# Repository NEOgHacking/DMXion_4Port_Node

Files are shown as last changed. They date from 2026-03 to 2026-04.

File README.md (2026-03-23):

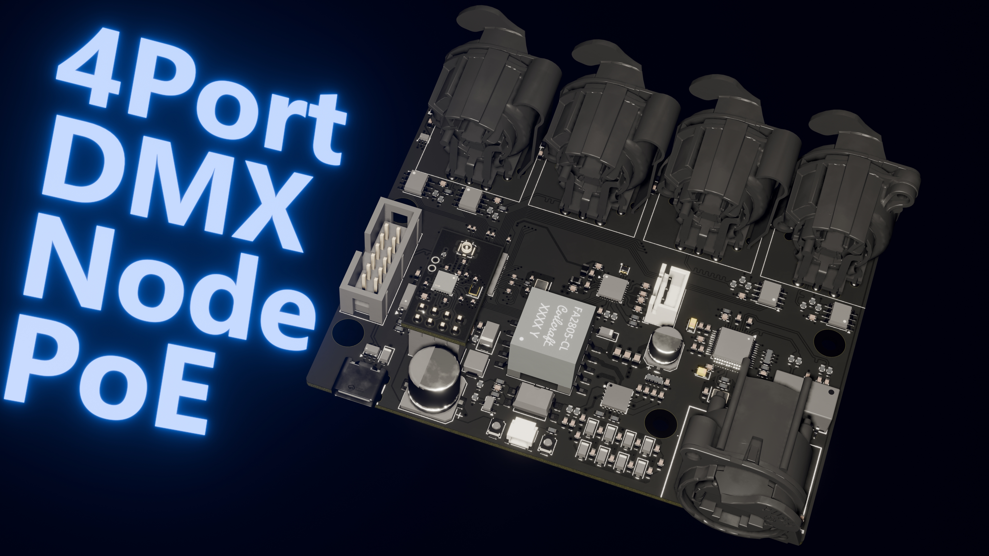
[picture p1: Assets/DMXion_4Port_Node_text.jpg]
Render

# DMXion_4Port_Node
DMXion_4Port_Node is a DMX network node based on the official grandMA3 onPC 4Port Node 4k. My version also has 4DMX outputs with RDM support, a EtherCON connector for sturdy Ethernet connections and a display with a rotating knob for configuration. It also uses the Neutrik halo connectors with adressable rgb leds to show the status of the connection. But it also has some differences. First it unfortunately doesn't unlock any parameters in the GrandMA onPC software, but its 20x cheaper. About $100 instead of $2000.

# Features
This specific DMX node has some really usefull features.
1. 4DMX outputs with RDM support.
2. Neutrik EtherCON connector for a sturdy and lasting connection. Also support for ARTNET and sACN
3. Color display with a rotary encoder for configuration straigt from the unit itself.
4. UPS (uniteruptable power supply) For when the power cuts out but you still need it or just for battery operation.
5. Wifi card slot for wireless operation with the battery.
6. Powered by a rp2350 for its PIO modules so DMX is correctly implemented and not via a hacked uart or bitbanging a pin.
7. PoE (Power over Ethernet) For easy setup and as little wires as possible.
8. USB-C port for power and data to program the rp2350 or configure it.
9. Cheap PCB. The PCB is 100x72mm 4 layer so its cost is low only $7.

# Motivation
I started on making this DMX network node for a few reasons. First i was using a raspberry pi with a usb DMX dongle, this worked but was hard to set up and only got me 1 DMX universe without RDM. It also wasn't the cheapest setup. I wanted it to be cheaper and have more functionallity. Second I once had the opurtunity to use a grandMA3 onPC 4Port Node 4k at school once and realized how usefull it would be. Then my dumb brain said the same sentence it always says: "I can build that myself for cheaper right?" Next thing you know you are 100 hours deep into the project.

# Design
The design process was a heck of a ride, at first i started with the simple DMX part but then got to the ethernet. I really wanted PoE so started with the ride. It was a heck of a long ride, i think it took up 1/3 of the projects time its really complex. Also the most complex schematic from the whole project. The rest went pretty smooth. I had recently done another big project my 3D Printer mainboard and learned allot from that! So the rest was pretty straight forward, always some small chip changes here and there but apart from that it went well. The case design also went quick didn't have to high of standards for that but still wanted it to look good. After a whole day that was done. 
I used KiCad for PCB design, Onshape for 3D design and VScode for Firmware.

# Use
To use this product first get the firmware uploaded via the arduino IDE or PlatformIO Then just plug it into a ethernet setup and plug in your DMX devices. Thats it! Its that simple! For config use the display with the rotating knob to select universes, ethernet settings, ext.

# Schematic
This is a very long schematic. You can find the whole schematics in .PDF format in the individual PCB design folders. But here are some important ones.
First the main schematic of the main PCB.
Main schematic
Then the schematic of the display module.
Display module schematic
And finally the esp wifi module.
WIFI module schematic

# PCB's
So this project has 3 PCB's, first the main PCB that does all the hard work, then a display PCB with a rotary encoder and support components for a bare LCD and finally a custom made WIFI module PCB based on the esp.
Main PCB
Display_module PCB
WIFI_module PCB
(there is a glitch in this game, every project i do i get exactly 3 PCB's)

# Case
For this project there needed to be a case to protect the PCB from the outside world. I did this in onshape and am happy with the end result.
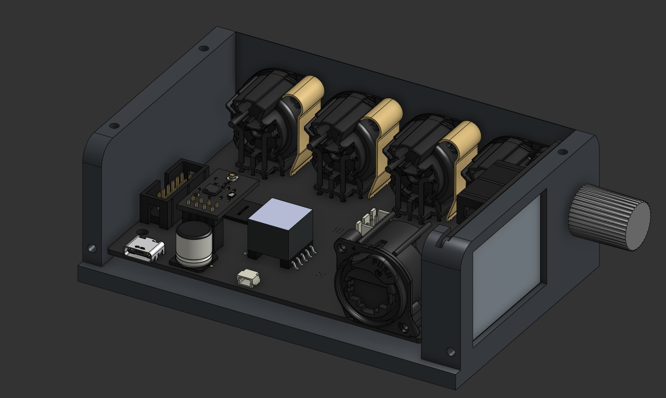
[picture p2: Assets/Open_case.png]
Open_case

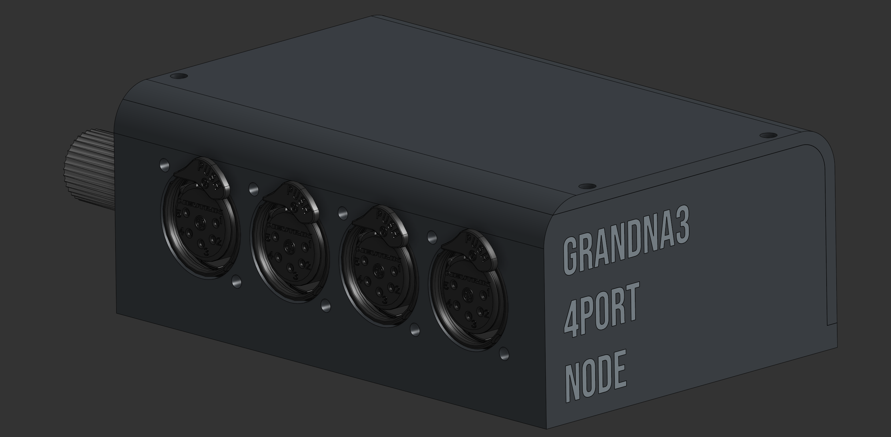
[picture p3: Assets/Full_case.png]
Full_case

Here is the Onshape link:
https://cad.onshape.com/documents/7a1aa90c6a7c74ef8699231e/w/3ea57ea1703701009a206be9/e/21fe65d6bda3912845cd8de3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
<details>
  <summary>BOM</summary>
  
# BOM
| Id | Designator | Footprint | Quantity | Designation | Supplier and ref | Column1 | Needed quantity | - | LCSC | MOUSER | Already in another pcb | Enough? | Mrf# | Mfr. | Order Qty. | Unit Price(USD) | Ext.Price(USD) | LCSC#/MOUSER | Package | Min | Mult | SPQ | Availability | Stock Status | Customer Notes | Description | Matched status | Product Link |  |  |  |  |  |  |  |  |  |  |  |  |  |  |  |  |  |  |  |
| --- | --- | --- | --- | --- | --- | --- | --- | --- | --- | --- | --- | --- | --- | --- | --- | --- | --- | --- | --- | --- | --- | --- | --- | --- | --- | --- | --- | --- | --- | --- | --- | --- | --- | --- | --- | --- | --- | --- | --- | --- | --- | --- | --- | --- | --- | --- | --- |
| 17 | BT1 | JST_XH_B3B-XH-A_1x03_P2.50mm_Vertical | 1 | Battery_Cell |  |  | 2 |  | x |  |  |  | B3B-XH-A(LF)(SN) | JST | 10 | $0.05 | $0.50 | C144394 | Through Hole,P=2.5mm | 10 | 10 | 1000 | 61980 | In Stock |  | Connector Header 3 position 2.5mm Pitch 3A Through Hole -25?~+85? | Exact Matches | https://www.lcsc.com/product-detail/C144394.html |  |  |  |  |  |  |  |  |  |  |  |  |  |  |  |  |  |  |  |
| 6 | C12,C7,C5,C13,C11,C4,C6,C3,C9,C10,C8,C1 | C_0402_1005Metric | 12 | 100n |  |  | 24 |  | x |  |  |  | CL05B104KO5NNNC | Samsung Electro-Mechanics | 100 | $0.00 | $0.13 | C1525 | 402 | 100 | 100 | 10000 | 22016000 | In Stock |  | 100nF �10% 16V Ceramic Capacitor X7R 0402 | Exact Matches | https://www.lcsc.com/product-detail/C1525.html |  |  |  |  |  |  |  |  |  |  |  |  |  |  |  |  |  |  |  |
| 37 | C17,C19 | C_0402_1005Metric | 2 | 15p |  |  | 4 |  | x |  |  |  | CL05C150JB5NNNC | Samsung Electro-Mechanics | 100 | $0.00 | $0.37 | C86285 | 402 | 100 | 100 | 10000 | 454800 | In Stock |  | 15pF �5% 50V Ceramic Capacitor C0G 0402 | Exact Matches | https://www.lcsc.com/product-detail/C86285.html |  |  |  |  |  |  |  |  |  |  |  |  |  |  |  |  |  |  |  |
| 3 | C2,C15,C16,C14 | C_0402_1005Metric | 4 | 4u7 |  |  | 8 |  | x |  |  |  | CL05A475KP5NRNC | Samsung Electro-Mechanics | 50 | $0.01 | $0.31 | C368809 | 402 | 50 | 50 | 10000 | 5001000 | In Stock |  | 4.7uF �10% 10V Ceramic Capacitor X5R 0402 | Exact Matches | https://www.lcsc.com/product-detail/C368809.html |  |  |  |  |  |  |  |  |  |  |  |  |  |  |  |  |  |  |  |
| 9 | C20,C23,C57,C33,C21 | C_0603_1608Metric | 5 | 10n |  |  | 10 |  | x |  |  |  | CL10B103KC8NNNC | Samsung Electro-Mechanics | 100 | $0.01 | $0.62 | C84709 | 603 | 100 | 100 | 4000 | 18800 | In Stock |  | 10nF �10% 100V Ceramic Capacitor X7R 0603 | Exact Matches | https://www.lcsc.com/product-detail/C84709.html |  |  |  |  |  |  |  |  |  |  |  |  |  |  |  |  |  |  |  |
| 15 | C22,C36,C39,C41,C34,C38,C63,C37,C65,C47,C40,C35 | C_0603_1608Metric | 12 | 1n |  |  | 24 |  | x |  |  |  | CL10B102KC8NNNC | Samsung Electro-Mechanics | 50 | $0.01 | $0.25 | C153291 | 603 | 50 | 50 | 4000 | 107650 | In Stock |  | 1nF �10% 100V Ceramic Capacitor X7R 0603 | Exact Matches | https://www.lcsc.com/product-detail/C153291.html |  |  |  |  |  |  |  |  |  |  |  |  |  |  |  |  |  |  |  |
| 5 | C27,C76,C72,C70,C73,C64,C79,C60,C28,C74,C29,C88,C43,C78,C61,C71,C30,C66,C69,C68,C25,C42,C75,C67,C45,C31,C18,C26,C77 | C_0603_1608Metric | 29 | 100n |  |  | 58 |  | x |  |  |  | CL10B104KC8NNNC | Samsung Electro-Mechanics | 100 | $0.01 | $0.65 | C15725 | 603 | 50 | 50 | 4000 | 175750 | In Stock |  | 100nF �10% 100V Ceramic Capacitor X7R 0603 | Exact Matches | https://www.lcsc.com/product-detail/C15725.html |  |  |  |  |  |  |  |  |  |  |  |  |  |  |  |  |  |  |  |
| 63 | C32,C24 | CP_EIA-2012-12_Kemet-R | 2 | 10u |  |  | 4 |  | x |  |  |  | T491A106K006AT | KEMET | 5 | $0.18 | $0.91 | C122260 | CASE-A-3216-18(mm) | 5 | 5 | 2000 | 1980 | In Stock |  | 10uF �10% 6.3V Tantalum Capacitors 4?@100kHz CASE-A-3216-18(mm) | Exact Matches | https://www.lcsc.com/product-detail/C122260.html |  |  |  |  |  |  |  |  |  |  |  |  |  |  |  |  |  |  |  |
| 50 | C46,C44 | C_0603_1608Metric | 2 | 6.8n |  |  | 4 |  | x |  |  |  | CL10B682KB8NNNC | Samsung Electro-Mechanics | 100 | $0.01 | $0.68 | C84723 | 603 | 100 | 100 | 4000 | 5300 | In Stock |  | 6.8nF �10% 50V Ceramic Capacitor X7R 0603 | Exact Matches | https://www.lcsc.com/product-detail/C84723.html |  |  |  |  |  |  |  |  |  |  |  |  |  |  |  |  |  |  |  |
| 8 | C48,C49 | C_0603_1608Metric | 2 | 10p |  |  | 4 |  | x |  |  |  | CL10C100JB8NNNC | Samsung Electro-Mechanics | 100 | $0.01 | $0.50 | C1634 | 603 | 100 | 100 | 4000 | 1498600 | In Stock |  | 10pF �5% 50V Ceramic Capacitor C0G 0603 | Exact Matches | https://www.lcsc.com/product-detail/C1634.html |  |  |  |  |  |  |  |  |  |  |  |  |  |  |  |  |  |  |  |
| 41 | C52,C51,C50 | C_0805_2012Metric | 3 | 1u |  |  | 6 |  | x |  |  |  | C2012X7S2A105KT000N | TDK | 10 | $0.11 | $1.12 | C342785 | 805 | 5 | 5 | 2000 | 5645 | In Stock |  | 1uF �10% 100V Ceramic Capacitor X7S 0805 | Exact Matches | https://www.lcsc.com/product-detail/C342785.html |  |  |  |  |  |  |  |  |  |  |  |  |  |  |  |  |  |  |  |
| 57 | C53 | CP_Elec_6.3x5.8 | 1 | 10u |  |  | 2 |  | x |  |  |  | EEEFK1J100P | PANASONIC | 5 | $0.14 | $0.71 | C128459 | SMD,D6.3xL5.8mm | 5 | 5 | 1000 | 1420 | In Stock |  | 10uF �20% 63V Aluminum Electrolytic Capacitors 2000hrs@105? | Exact Matches | https://www.lcsc.com/product-detail/C128459.html |  |  |  |  |  |  |  |  |  |  |  |  |  |  |  |  |  |  |  |
| 69 | C54 | C_0603_1608Metric | 1 | 470p |  |  | 2 |  | x |  |  |  | CL10B471KB8NNNC | Samsung Electro-Mechanics | 100 | $0.01 | $0.56 | C22396 | 603 | 100 | 100 | 4000 | 189700 | In Stock |  | 470pF �10% 50V Ceramic Capacitor X7R 0603 | Exact Matches | https://www.lcsc.com/product-detail/C22396.html |  |  |  |  |  |  |  |  |  |  |  |  |  |  |  |  |  |  |  |
| 44 | C55 | CP_Elec_10x10.5 | 1 | 1000u |  |  | 2 |  | x |  |  |  | EEEFT1E102UP | PANASONIC | 2 | $0.78 | $1.55 | C401766 | SMD,D10xL10.2mm | 1 | 1 | 500 | 4041 | In Stock |  | 1000uF �20% 25V Aluminum Electrolytic Capacitors 2000hrs@105? | Exact Matches | https://www.lcsc.com/product-detail/C401766.html |  |  |  |  |  |  |  |  |  |  |  |  |  |  |  |  |  |  |  |
| 52 | C56 | C_1206_3216Metric | 1 | 100u |  |  | 2 |  | x |  |  |  | CL31A107MQHNNNE | Samsung Electro-Mechanics | 10 | $0.06 | $0.61 | C15008 | 1206 | 10 | 10 | 2000 | 6009890 | In Stock |  | 100uF �20% 6.3V Ceramic Capacitor X5R 1206 | Exact Matches | https://www.lcsc.com/product-detail/C15008.html |  |  |  |  |  |  |  |  |  |  |  |  |  |  |  |  |  |  |  |
| 14 | C58 | C_0603_1608Metric | 1 | 4u7 |  |  | 2 |  | x |  |  |  | CL10A475KP8NNNC | Samsung Electro-Mechanics | 50 | $0.01 | $0.28 | C1705 | 603 | 50 | 50 | 4000 | 13333100 | In Stock |  | 4.7uF �10% 10V Ceramic Capacitor X5R 0603 | Exact Matches | https://www.lcsc.com/product-detail/C1705.html |  |  |  |  |  |  |  |  |  |  |  |  |  |  |  |  |  |  |  |
| 20 | C59 | C_0603_1608Metric | 1 | 3.3n |  |  | 2 |  | x |  |  |  | CL10B332KB8NNNC | Samsung Electro-Mechanics | 20 | $0.01 | $0.11 | C1613 | 603 | 20 | 20 | 4000 | 61420 | In Stock |  | 3.3nF �10% 50V Ceramic Capacitor X7R 0603 | Exact Matches | https://www.lcsc.com/product-detail/C1613.html |  |  |  |  |  |  |  |  |  |  |  |  |  |  |  |  |  |  |  |
| 42 | C62 | C_0603_1608Metric | 1 | 15n |  |  | 2 |  | x |  |  |  | CL10B153KB8NNNC | Samsung Electro-Mechanics | 20 | $0.01 | $0.16 | C296713 | 603 | 20 | 20 | 4000 | 39800 | In Stock |  | 15nF �10% 50V Ceramic Capacitor X7R 0603 | Exact Matches | https://www.lcsc.com/product-detail/C296713.html |  |  |  |  |  |  |  |  |  |  |  |  |  |  |  |  |  |  |  |
| 10 | C80,C81 | C_0603_1608Metric | 2 | 1u |  |  | 4 |  | x |  |  |  | CL10A105KB8NNNC | Samsung Electro-Mechanics | 50 | $0.01 | $0.28 | C15849 | 603 | 50 | 50 | 4000 | 4548950 | In Stock |  | 1uF �10% 50V Ceramic Capacitor X5R 0603 | Exact Matches | https://www.lcsc.com/product-detail/C15849.html |  |  |  |  |  |  |  |  |  |  |  |  |  |  |  |  |  |  |  |
| 53 | C82,C86,C87,C83,C84 | C_0603_1608Metric | 5 | 10u |  |  | 10 |  | x |  |  |  | CL10A106KP8NNNC | Samsung Electro-Mechanics | 50 | $0.01 | $0.33 | C19702 | 603 | 50 | 50 | 4000 | 13475400 | In Stock |  | 10uF �10% 10V Ceramic Capacitor X5R 0603 | Exact Matches | https://www.lcsc.com/product-detail/C19702.html |  |  |  |  |  |  |  |  |  |  |  |  |  |  |  |  |  |  |  |
| 58 | C85 | C_0603_1608Metric | 1 | 2u2 |  |  | 2 |  | x |  |  |  | CL10A225KO8NNNC | Samsung Electro-Mechanics | 50 | $0.01 | $0.31 | C23630 | 603 | 50 | 50 | 4000 | 5941500 | In Stock |  | 2.2uF �10% 16V Ceramic Capacitor X5R 0603 | Exact Matches | https://www.lcsc.com/product-detail/C23630.html |  |  |  |  |  |  |  |  |  |  |  |  |  |  |  |  |  |  |  |
| 32 | D1 | D_SOD-123F | 1 | DSK24L |  |  | 2 |  | x |  |  |  | DSK24L | LGE | 10 | $0.06 | $0.62 | C19272974 | SOD-123FL | 10 | 10 | 3000 | 2600 | In Stock |  | Diode Independent 40V 2A Surface Mount SOD-123FL | Exact Matches | https://www.lcsc.com/product-detail/C19272974.html |  |  |  |  |  |  |  |  |  |  |  |  |  |  |  |  |  |  |  |
| 56 | D10 | D_SMA | 1 | SS34 |  |  | 2 |  | x |  |  |  | SS34 | GOODWORK | 20 | $0.03 | $0.56 | C908680 | SMA(DO-214AC) | 20 | 20 | 5000 | 202260 | In Stock |  | Diode Independent 40V 3A Surface Mount SMA(DO-214AC) | Exact Matches | https://www.lcsc.com/product-detail/C908680.html |  |  |  |  |  |  |  |  |  |  |  |  |  |  |  |  |  |  |  |
| 49 | D11 | D_SOD-123 | 1 | 1N4148W |  |  | 2 |  | x |  |  |  | 1N4148W-E3-08 | VISHAY | 5 | $0.03 | $0.17 | C241939 | SOD-123 | 5 | 5 | 3000 | 71145 | In Stock |  | Diode Independent 75V 150mA Surface Mount SOD-123 | Exact Matches | https://www.lcsc.com/product-detail/C241939.html |  |  |  |  |  |  |  |  |  |  |  |  |  |  |  |  |  |  |  |
| 66 | D12 | D_SOD-123F | 1 | DFTL30A |  |  | 2 |  | x |  |  |  | P4FL30A_R1_00001 | PANJIT | 5 | $0.09 | $0.43 | C2902532 | SOD-123FL | 5 | 5 | 3000 | 2220 | In Stock |  | 48.4VC Clamp 8.3A@10/1000us Ipp TVS DIODE SOD-123FL | Exact Matches | https://www.lcsc.com/product-detail/C2902532.html |  |  |  |  |  |  |  |  |  |  |  |  |  |  |  |  |  |  |  |
| 11 | D13 | LED-SMD_4P-L1.6-W1.5-TR | 1 | LED_ABGR |  |  | 2 |  | x |  |  |  | DY-S161506BRGC-T5-4T-03 | TONYU | 10 | $0.04 | $0.37 | C7280953 | SMD,1.6x1.5mm | 10 | 10 | 4000 | 1640 | In Stock |  | Red, Green, Blue 630nm LED Indication - Discrete 1.8V~2.4V SMD,1.5x1.6mm | Exact Matches | https://www.lcsc.com/product-detail/C7280953.html |  |  |  |  |  |  |  |  |  |  |  |  |  |  |  |  |  |  |  |
| 28 | D2,D7,D5,D6,D9,D3,D4,D8 | D_SOD-123F | 8 | SL110PL-TP |  |  | 16 |  | x |  |  |  | SL110PL-TP | MCC | 20 | $0.15 | $3.07 | C7080765 | SOD-123FL | 10 | 10 | 2500 | 4140 | In Stock |  | Diode 100V 1A Surface Mount SOD-123FL | Exact Matches | https://www.lcsc.com/product-detail/C7080765.html |  |  |  |  |  |  |  |  |  |  |  |  |  |  |  |  |  |  |  |
| 62 | IC1 | QFN-32-1EP_5x5mm_P0.5mm_EP3.45x3.45mm_ThermalVias | 1 | NPM1300-QEAA-R7 |  |  | 2 |  |  | x |  |  | nPM1300-QEAA-R7 | Nordic Semiconductor | 2 | $1.54 | $3.08 | 949-NPM1300-QEAA-R7 |  |  |  |  |  |  |  |  |  | https://nl.mouser.com/ProductDetail/Nordic-Semiconductor/nPM1300-QEAA-R7?qs=3pZoU%2F6IRTj0hxAp51B2zA%3D%3D |  |  |  |  |  |  |  |  |  |  |  |  |  |  |  |  |  |  |  |
| 33 | J1 | JST_SH_SM03B-SRSS-TB_1x03-1MP_P1.00mm_Horizontal | 1 | Conn_01x03_MountingPin |  |  | 2 |  | x |  |  |  | SM03B-SRSS-TB(LF)(SN) | JST | 5 | $0.17 | $0.87 | C160403 | SMD,P=1mm,Surface Mount,Right Angle | 5 | 5 | 3000 | 47315 | In Stock |  | Connector Header 3 position 1mm Pitch 1A Surface Mount, Right Angle -25?~+85? | Exact Matches | https://www.lcsc.com/product-detail/C160403.html |  |  |  |  |  |  |  |  |  |  |  |  |  |  |  |  |  |  |  |
| 39 | J12 | IDC-Header_2x06_P2.54mm_Vertical | 1 | IDC |  |  | 2 |  | x |  |  |  | 2.54-2*6P | BOOMELE(Boom Precision Elec) | 5 | $0.11 | $0.57 | C9136 | Through Hole,P=2.54mm | 5 | 5 | 220 | 19840 | In Stock |  | Connector IDC Header Through Hole 12 position 2.54mm | Exact Matches | https://www.lcsc.com/product-detail/C9136.html |  |  |  |  |  |  |  |  |  |  |  |  |  |  |  |  |  |  |  |
| 51 | J13 | PinSocket_2x04_P2.54mm_Vertical | 1 | Conn_02x04 |  |  | 2 |  | x |  |  |  | PM254V-12-08-H85 | XFCN | 5 | $0.11 | $0.56 | C2834799 | Through Hole,P=2.54mm | 5 | 5 | 1000 | 26375 | In Stock |  | Female Header 8 Position 2.54mm Pitch Dual Row Through Hole -40?~+105? | Exact Matches | https://www.lcsc.com/product-detail/C2834799.html |  |  |  |  |  |  |  |  |  |  |  |  |  |  |  |  |  |  |  |
| 13 | J2 | USB-C_SMD-TYPE-C-31-M-12_1 | 1 | USB_C_Receptacle_USB2.0_14P |  |  | 2 |  | x |  |  |  | TYPE-C-31-M-12 | Korean Hroparts Elec | 5 | $0.17 | $0.84 | C165948 | SMD | 5 | 5 | 1000 | 263130 | In Stock |  | USB-C (USB TYPE-C) Receptacle Connector 16 Position Surface Mount | Exact Matches | https://www.lcsc.com/product-detail/C165948.html |  |  |  |  |  |  |  |  |  |  |  |  |  |  |  |  |  |  |  |
| 1 | J3 | NE8FAHLRDAE | 1 | RJ45 |  |  | 2 |  |  | x |  |  | NE8FAH-LR-DAE | Neutrik | 2 | $6.73 | $13.46 | 568-NE8FAH-LR-DAE |  |  |  |  |  |  |  |  |  | https://nl.mouser.com/ProductDetail/Neutrik/NE8FAH-LR-DAE?qs=4ASt3YYao0WhX9cY4j%252BFSA%3D%3D |  |  |  |  |  |  |  |  |  |  |  |  |  |  |  |  |  |  |  |
| 12 | J4,J8,J10,J6 | NC5FAH1-LR-DAE | 4 | XLR5 |  |  | 4 |  |  | x |  |  | NC5FAH1-LR-DAE | Neutrik | 4 | $7.79 | $31.16 | 568-NC5FAH1-LR-DAE |  |  |  |  |  |  |  |  |  | https://nl.mouser.com/ProductDetail/Neutrik/NC5FAH1-LR-DAE?qs=6avfeC6zeS5u3oz5Q9UQlw%3D%3D |  |  |  |  |  |  |  |  |  |  |  |  |  |  |  |  |  |  |  |
| 47 | J7,J11,J5,J9 | NC3FAH2-LR-DAE | 4 | XLR3 |  |  | 4 |  |  | x |  |  | NC3FAH2-LR-DAE | Neutrik | 4 | $4.33 | $17.32 | 568-NC3FAH2-LR-DAE |  |  |  |  |  |  |  |  |  | https://nl.mouser.com/ProductDetail/Neutrik/NC3FAH2-LR-DAE?qs=4ASt3YYao0XSl5KoEkZrIA%3D%3D |  |  |  |  |  |  |  |  |  |  |  |  |  |  |  |  |  |  |  |
| 21 | L1 | IND-SMD_L2.0-W1.6_AOTA-B201610S3R3-101-T | 1 | 3.3u |  |  | 2 |  | x |  |  |  | AOTA-B201610S3R3-101-T | ABRACON | 5 | $0.29 | $1.44 | C42411119 | 806 | 5 | 5 | 3000 | 15360 | In Stock |  | 2.1A 3.3uH 115m? 2.4A Molded Inductor 0806 Fixed Inductors RoHS | Exact Matches | https://www.lcsc.com/product-detail/C42411119.html |  |  |  |  |  |  |  |  |  |  |  |  |  |  |  |  |  |  |  |
| 48 | L2 | L_Vishay_IHLP-1616 | 1 | 1u |  |  | 2 |  | x |  |  |  | IHLP1616BZER1R0M11 | VISHAY | 2 | $1.63 | $3.26 | C844978 | 1616 | 1 | 1 | 4000 | 79 | In Stock |  | 4.5A 1uH 27m? 5A �20% 1616 Fixed Inductors RoHS | Exact Matches | https://www.lcsc.com/product-detail/C844978.html |  |  |  |  |  |  |  |  |  |  |  |  |  |  |  |  |  |  |  |
| 22 | L3 | XFMR-SMD_16P-L12.7-W7.1-P1.27-LS9.4-BL | 1 | H2019NLT |  |  | 2 |  | x |  |  |  | H2019NLT | PULSE | 2 | $0.74 | $1.49 | C110250 | SMD,12.7x7.1mm | 1 | 1 | 600 | 2085 | In Stock |  | LAN Transformer 1CT:1CT Surface Mount,12.7x7.1mm | Exact Matches | https://www.lcsc.com/product-detail/C110250.html |  |  |  |  |  |  |  |  |  |  |  |  |  |  |  |  |  |  |  |
| 30 | L4,L5 | L_0805_2012Metric | 2 | 2u2 |  |  | 4 |  | x |  |  |  | MLP2012H2R2MT0S1 | TDK | 10 | $0.08 | $0.84 | C383369 | 805 | 10 | 10 | 4000 | 89820 | In Stock |  | 1A 2.2uH 195m? �20% 0805 Fixed Inductors RoHS | Exact Matches | https://www.lcsc.com/product-detail/C383369.html |  |  |  |  |  |  |  |  |  |  |  |  |  |  |  |  |  |  |  |
| 16 | LED1,LED5,LED6,LED3,LED8,LED10,LED9,LED2,LED4,LED7 | LED-SMD_4P-L1.5-W1.5-BL | 10 | SK6805-EC15 |  |  | 20 |  | x |  |  |  | SK6805-EC15 | OPSCO Optoelectronics | 45 | $0.09 | $4.04 | C2890035 | SMD-4P,1.5x1.5mm | 5 | 5 | 4500 | 259070 | In Stock |  | SMD-4P,1.5x1.5mm LED Addressable, Specialty RoHS | Exact Matches | https://www.lcsc.com/product-detail/C2890035.html |  |  |  |  |  |  |  |  |  |  |  |  |  |  |  |  |  |  |  |
| 29 | R1,R27,R3 | R_0603_1608Metric | 3 | 1k |  |  | 6 |  | x |  |  |  | RC0603FR-071KL | YAGEO | 100 | $0.00 | $0.14 | C22548 | 603 | 100 | 100 | 5000 | 4596000 | In Stock |  | 100mW 1k? 75V Thick Film Resistor �100ppm/? �1% 0603 Chip Resistor - Surface Mount RoHS | Exact Matches | https://www.lcsc.com/product-detail/C22548.html |  |  |  |  |  |  |  |  |  |  |  |  |  |  |  |  |  |  |  |
| 34 | R11,R43,R7,R42 | R_0603_1608Metric | 4 | 10k |  |  | 8 |  | x |  |  |  | RC0603FR-0710KL | YAGEO | 100 | $0.00 | $0.14 | C98220 | 603 | 100 | 100 | 5000 | 9034300 | In Stock |  | 100mW 10k? 75V Thick Film Resistor �100ppm/? �1% 0603 Chip Resistor - Surface Mount RoHS | Exact Matches | https://www.lcsc.com/product-detail/C98220.html |  |  |  |  |  |  |  |  |  |  |  |  |  |  |  |  |  |  |  |
| 19 | R13,R12,R15,R14 | R_0603_1608Metric | 4 | 33R |  |  | 8 |  | x |  |  |  | RC0603FR-0733RL | YAGEO | 100 | $0.00 | $0.15 | C108661 | 603 | 100 | 100 | 5000 | 1912100 | In Stock |  | 100mW 33? 75V Thick Film Resistor �100ppm/? �1% 0603 Chip Resistor - Surface Mount RoHS | Exact Matches | https://www.lcsc.com/product-detail/C108661.html |  |  |  |  |  |  |  |  |  |  |  |  |  |  |  |  |  |  |  |
| 38 | R16 | R_0603_1608Metric | 1 | 1M |  |  | 2 |  | x |  |  |  | RC0603FR-071ML | YAGEO | 100 | $0.00 | $0.15 | C105578 | 603 | 100 | 100 | 5000 | 711300 | In Stock |  | 100mW 1M? 75V Thick Film Resistor �100ppm/? �1% 0603 Chip Resistor - Surface Mount RoHS | Exact Matches | https://www.lcsc.com/product-detail/C105578.html |  |  |  |  |  |  |  |  |  |  |  |  |  |  |  |  |  |  |  |
| 2 | R18 | R_0603_1608Metric | 1 | 10R |  |  | 2 |  | x |  |  |  | RC0603FR-0710RL | YAGEO | 100 | $0.00 | $0.43 | C109318 | 603 | 100 | 100 | 5000 | 1937200 | In Stock |  | 100mW 10? 75V Thick Film Resistor �1% �200ppm/? 0603 Chip Resistor - Surface Mount RoHS | Exact Matches | https://www.lcsc.com/product-detail/C109318.html |  |  |  |  |  |  |  |  |  |  |  |  |  |  |  |  |  |  |  |
| 72 | R19 | R_0603_1608Metric | 1 | 12.4k |  |  | 2 |  | x |  |  |  | RC0603FR-0712K4L | YAGEO | 100 | $0.00 | $0.15 | C137798 | 603 | 100 | 100 | 5000 | 38200 | In Stock |  | 100mW 12.4k? 75V Thick Film Resistor �100ppm/? �1% 0603 Chip Resistor - Surface Mount RoHS | Exact Matches | https://www.lcsc.com/product-detail/C137798.html |  |  |  |  |  |  |  |  |  |  |  |  |  |  |  |  |  |  |  |
| 54 | R2 | R_0402_1005Metric | 1 | 33R |  |  | 2 |  | x |  |  |  | RC0402FR-0733RL | YAGEO | 100 | $0.00 | $0.08 | C138002 | 402 | 100 | 100 | 10000 | 1384200 | In Stock |  | 62.5mW 33? 50V Thick Film Resistor �100ppm/? �1% 0402 Chip Resistor - Surface Mount RoHS | Exact Matches | https://www.lcsc.com/product-detail/C138002.html |  |  |  |  |  |  |  |  |  |  |  |  |  |  |  |  |  |  |  |
| 73 | R20 | R_0603_1608Metric | 1 | 4.99k |  |  | 2 |  | x |  |  |  | RC0603FR-074K99L | YAGEO | 100 | $0.00 | $0.15 | C114621 | 603 | 100 | 100 | 5000 | 164800 | In Stock |  | 100mW 4.99k? 75V Thick Film Resistor �100ppm/? �1% 0603 Chip Resistor - Surface Mount RoHS | Exact Matches | https://www.lcsc.com/product-detail/C114621.html |  |  |  |  |  |  |  |  |  |  |  |  |  |  |  |  |  |  |  |
| 24 | R21 | R_0603_1608Metric | 1 | 2.05k |  |  | 2 |  | x |  |  |  | RC0603FR-072K05L | YAGEO | 100 | $0.00 | $0.14 | C137751 | 603 | 100 | 100 | 5000 | 7700 | In Stock |  | 100mW 2.05k? 75V Thick Film Resistor �100ppm/? �1% 0603 Chip Resistor - Surface Mount RoHS | Exact Matches | https://www.lcsc.com/product-detail/C137751.html |  |  |  |  |  |  |  |  |  |  |  |  |  |  |  |  |  |  |  |
| 46 | R22,R40,R23,R17,R8 | R_0603_1608Metric | 5 | 0R |  |  | 10 |  | x |  |  |  | RC0603FR-070RL | YAGEO | 100 | $0.00 | $0.13 | C100044 | 603 | 100 | 100 | 5000 | 2174100 | In Stock |  | 0? 100mW 75V Thick Film Resistor �1% 0603 Chip Resistor - Surface Mount RoHS | Exact Matches | https://www.lcsc.com/product-detail/C100044.html |  |  |  |  |  |  |  |  |  |  |  |  |  |  |  |  |  |  |  |
| 55 | R24 | R_0603_1608Metric | 1 | 36.5k |  |  | 2 |  | x |  |  |  | RC0603FR-0736K5L | YAGEO | 100 | $0.00 | $0.14 | C137738 | 603 | 100 | 100 | 5000 | 20500 | In Stock |  | 36.5k? 100mW 75V Thick Film Resistor �100ppm/? �1% 0603 Chip Resistor - Surface Mount RoHS | Exact Matches | https://www.lcsc.com/product-detail/C137738.html |  |  |  |  |  |  |  |  |  |  |  |  |  |  |  |  |  |  |  |
| 68 | R25 | R_0603_1608Metric | 1 | 12.1k |  |  | 2 |  | x |  |  |  | RC0603FR-0712K1L | YAGEO | 100 | $0.00 | $0.18 | C123417 | 603 | 100 | 100 | 5000 | 0 | Backordered |  | 100mW 12.1k? 75V Thick Film Resistor �100ppm/? �1% 0603 Chip Resistor - Surface Mount RoHS | Exact Matches | https://www.lcsc.com/product-detail/C123417.html |  |  |  |  |  |  |  |  |  |  |  |  |  |  |  |  |  |  |  |
| 67 | R26 | R_0603_1608Metric | 1 | 24.9k |  |  | 2 |  | x |  |  |  | RC0603FR-0724K9L | YAGEO | 100 | $0.00 | $0.15 | C137761 | 603 | 100 | 100 | 5000 | 0 | Backordered |  | 100mW 24.9k? 75V Thick Film Resistor �100ppm/? �1% 0603 Chip Resistor - Surface Mount RoHS | Exact Matches | https://www.lcsc.com/product-detail/C137761.html |  |  |  |  |  |  |  |  |  |  |  |  |  |  |  |  |  |  |  |
| 4 | R29,R38,R28,R30,R39,R31,R36,R37 | R_0603_1608Metric | 8 | 348R |  |  | 16 |  | x |  |  |  | RC0603FR-07348RL | YAGEO | 100 | $0.00 | $0.14 | C137742 | 603 | 100 | 100 | 5000 | 6700 | In Stock |  | 100mW 348? 75V Thick Film Resistor �100ppm/? �1% 0603 Chip Resistor - Surface Mount RoHS | Exact Matches | https://www.lcsc.com/product-detail/C137742.html |  |  |  |  |  |  |  |  |  |  |  |  |  |  |  |  |  |  |  |
| 26 | R33,R32,R35,R34 | R_0603_1608Metric | 4 | 133R |  |  | 8 |  | x |  |  |  | RC0603FR-07133RL | YAGEO | 100 | $0.00 | $0.07 | C273752 | 603 | 100 | 100 | 5000 | 0 | Backordered |  | 133? 100mW 75V Thick Film Resistor �100ppm/? �1% 0603 Chip Resistor - Surface Mount RoHS | Exact Matches | https://www.lcsc.com/product-detail/C273752.html |  |  |  |  |  |  |  |  |  |  |  |  |  |  |  |  |  |  |  |
| 61 | R41 | R_0603_1608Metric | 1 | 430k |  |  | 2 |  | x |  |  |  | RC0603FR-07430KL | YAGEO | 100 | $0.00 | $0.15 | C482869 | 603 | 100 | 100 | 5000 | 30900 | In Stock |  | 430k? 100mW 75V Thick Film Resistor �100ppm/? �1% 0603 Chip Resistor - Surface Mount RoHS | Exact Matches | https://www.lcsc.com/product-detail/C482869.html |  |  |  |  |  |  |  |  |  |  |  |  |  |  |  |  |  |  |  |
| 7 | R5,R4 | R_0402_1005Metric | 2 | 27R |  |  | 4 |  | x |  |  |  | RC0402FR-0727RL | YAGEO | 100 | $0.00 | $0.09 | C138021 | 402 | 100 | 100 | 10000 | 134000 | In Stock |  | 27? �1% 62.5mW 0402 Thick Film Resistor | Exact Matches | https://www.lcsc.com/product-detail/C138021.html |  |  |  |  |  |  |  |  |  |  |  |  |  |  |  |  |  |  |  |
| 64 | R6 | R_0402_1005Metric | 1 | 1k |  |  | 2 |  | x |  |  |  | RC0402FR-071KL | YAGEO | 100 | $0.00 | $0.08 | C106235 | 402 | 100 | 100 | 10000 | 5619500 | In Stock |  | 1k? 62.5mW 50V Thick Film Resistor �100ppm/? �1% 0402 Chip Resistor - Surface Mount RoHS | Exact Matches | https://www.lcsc.com/product-detail/C106235.html |  |  |  |  |  |  |  |  |  |  |  |  |  |  |  |  |  |  |  |
| 45 | REF**,REF**,REF** | NLR-LB | 3 | NLR-LB |  |  | 6 |  |  | x |  |  | NLR-LB | Neutrik | 6 | $1.01 | $6.06 | 568-NLR-LB |  |  |  |  |  |  |  |  |  | https://nl.mouser.com/ProductDetail/Neutrik/NLR-LB?qs=Imq1NPwxi76abBKVKeKReg%3D%3D |  |  |  |  |  |  |  |  |  |  |  |  |  |  |  |  |  |  |  |
| 36 | RN1,RN2 | R_Array_Concave_4x0603 | 2 | 75R |  |  | 4 |  | x |  |  |  | RTA03-4D750JTP | RALEC | 100 | $0.01 | $0.50 | C102680 | 0603x4 | 100 | 100 | 5000 | 584400 | In Stock |  | 4 �5% 75? 62.5mW �200ppm/? 0603x4 Resistor Networks, Arrays RoHS | Exact Matches | https://www.lcsc.com/product-detail/C102680.html |  |  |  |  |  |  |  |  |  |  |  |  |  |  |  |  |  |  |  |
| 59 | RN3 | R_Array_Concave_4x0603 | 1 | 10k |  |  | 2 |  | x |  |  |  | YC164-FR-0710KL | YAGEO | 50 | $0.01 | $0.47 | C110924 | 0603x4 | 50 | 50 | 5000 | 15400 | In Stock |  | 4 �1% 10k? 62.5mW �200ppm/? 0603x4 Resistor Networks, Arrays RoHS | Exact Matches | https://www.lcsc.com/product-detail/C110924.html |  |  |  |  |  |  |  |  |  |  |  |  |  |  |  |  |  |  |  |
| 18 | SW2,SW1 | SW_SPST_B3U-1000P | 2 | SW_Push |  |  | 4 |  | x |  |  |  | B3U-1000P | OMRON | 5 | $0.22 | $1.09 | C231329 | SMD,3x2.5mm | 5 | 5 | 3500 | 107795 | In Stock |  | Tactile Switch SPST 153gf 1.6mm SMD (SMT) Tab 3mm x 2.5mm Surface Mount | Exact Matches | https://www.lcsc.com/product-detail/C231329.html |  |  |  |  |  |  |  |  |  |  |  |  |  |  |  |  |  |  |  |
| 65 | T1 | FA2924ALD | 1 | FA2805 |  |  | 2 |  |  | x |  |  | FA2805-CLD | Coilcraft | 2 | $4.94 | $9.88 | 994-FA2805-CLD |  |  |  |  |  |  |  |  |  | https://nl.mouser.com/ProductDetail/Coilcraft/FA2805-CLD?qs=ZYnrCdKdyef%252BZjF1kFFBVA%3D%3D |  |  |  |  |  |  |  |  |  |  |  |  |  |  |  |  |  |  |  |
| 43 | U1 | QFN-80-1EP_10x10mm_P0.4mm_EP3.4x3.4mm | 1 | RP2350B |  |  | 2 |  |  | x |  |  | SC1510(13)-A4 | Raspberry Pi | 2 | $0.90 | $1.79 | 358-SC151013 |  |  |  |  |  |  |  |  |  | https://nl.mouser.com/ProductDetail/Raspberry-Pi/SC151013-A4?qs=jcD%2FCkGBYeM5TtP1Ew4BSg%3D%3D |  |  |  |  |  |  |  |  |  |  |  |  |  |  |  |  |  |  |  |
| 31 | U10,U8,U9,U11 | SOIC-8_3.9x4.9mm_P1.27mm | 4 | MAX3485 |  |  | 8 |  | x |  |  |  | MAX3485EESA+T | MAXIM | 8 | $2.30 | $18.38 | C9943 | SOIC-8 | 1 | 1 | 2500 | 12603 | In Stock |  | 3V~3.6V Transceiver 12Mbps Half-Duplex SOIC-8 Drivers, Receivers, Transceivers RoHS | Exact Matches | https://www.lcsc.com/product-detail/C9943.html |  |  |  |  |  |  |  |  |  |  |  |  |  |  |  |  |  |  |  |
| 25 | U12 | SOT-363_SC-70-6 | 1 | TXS0101DCK |  |  | 2 |  | x |  |  |  | TXS0101DCKR | TI | 2 | $0.52 | $1.04 | C132031 | SC-70-6 | 1 | 1 | 3000 | 660 | In Stock |  | 24Mbps 1 1 SC-70-6 Translators, Level Shifters RoHS | Exact Matches | https://www.lcsc.com/product-detail/C132031.html |  |  |  |  |  |  |  |  |  |  |  |  |  |  |  |  |  |  |  |
| 70 | U2 | SOIC-8_5.3x5.3mm_P1.27mm | 1 | W25Q128JVS |  |  | 2 |  | x |  |  |  | W25Q128JVSIQ | Winbond | 5 | $2.34 | $11.69 | C97521 | SOIC-8-208mil | 5 | 5 | 2000 | 59900 | In Stock |  | 2.7V~3.6V 128Mbit 133MHz SPI SOIC-8-208mil Memory (ICs) RoHS | Exact Matches | https://www.lcsc.com/product-detail/C97521.html |  |  |  |  |  |  |  |  |  |  |  |  |  |  |  |  |  |  |  |
| 27 | U3 | SOT-23-6 | 1 | USBLC6-2SC6 |  |  | 2 |  | x |  |  |  | USBLC6-2SC6 | ST | 5 | $0.14 | $0.69 | C7519 | SOT-23-6L | 5 | 5 | 3000 | 29740 | In Stock |  | 17VC Clamp 5A Ipp ESD DIODE SOT-23-6L | Exact Matches | https://www.lcsc.com/product-detail/C7519.html |  |  |  |  |  |  |  |  |  |  |  |  |  |  |  |  |  |  |  |
| 60 | U4 | LQFP-48_7x7mm_P0.5mm | 1 | W5500 |  |  | 2 |  | x |  |  |  | W5500 | WIZNET | 2 | $2.78 | $5.56 | C32843 | LQFP-48(7x7) | 1 | 1 | 2500 | 40852 | In Stock |  | 8 SPI LQFP-48(7x7) Interface Controllers RoHS | Exact Matches | https://www.lcsc.com/product-detail/C32843.html |  |  |  |  |  |  |  |  |  |  |  |  |  |  |  |  |  |  |  |
| 71 | U5 | SMDIP-4_W9.53mm_Clearance8mm | 1 | VO618A-3X017T |  |  | 2 |  | x |  |  |  | VO618A-3X017T | VISHAY | 5 | $0.38 | $1.89 | C143748 | SMD-4P | 5 | 5 | 1000 | 4355 | In Stock |  | 50mA 250mV@2.5mA,1mA 80V 6V 1.1V DC SMD-4P Transistor, Photovoltaic Output Optoisolators RoHS | Exact Matches | https://www.lcsc.com/product-detail/C143748.html |  |  |  |  |  |  |  |  |  |  |  |  |  |  |  |  |  |  |  |
| 74 | U6 | QFN-20_L5.0-W5.0-P0.80-TL-EP2.8 | 1 | SI3402-B-GMR |  |  | 2 |  | x |  |  |  | SI3402-B-GMR | SILICON LABS | 2 | $2.96 | $5.93 | C510771 | QFN-20-EP(5x5) | 1 | 1 | 2500 | 91 | In Stock |  | 37V~57V QFN-20-EP(5x5) Drivers, Receivers, Transceivers RoHS | Exact Matches | https://www.lcsc.com/product-detail/C510771.html |  |  |  |  |  |  |  |  |  |  |  |  |  |  |  |  |  |  |  |
| 35 | U7 | TSOT-23 | 1 | TLV431 |  |  | 2 |  | x |  |  |  | TLV431BQDBZR | TI | 5 | $0.23 | $1.16 | C398374 | SOT-23-3 | 5 | 5 | 3000 | 11190 | In Stock |  | 1.24V~6V �0.5% 1.24V~6V 15mA Adjustable SOT-23-3 Voltage Reference RoHS | Exact Matches | https://www.lcsc.com/product-detail/C398374.html |  |  |  |  |  |  |  |  |  |  |  |  |  |  |  |  |  |  |  |
| 40 | Y1 | Crystal_SMD_3225-4Pin_3.2x2.5mm | 1 | ABM8-272-T3 |  |  | 2 |  | x |  |  |  | ABM8-272-T3 | ABRACON | 5 | $0.33 | $1.64 | C20625731 | SMD3225-4P | 5 | 5 | 3000 | 0 | Backordered |  | �30ppm 10pF �30ppm SMD3225-4P Crystals RoHS | Exact Matches | https://www.lcsc.com/product-detail/C20625731.html |  |  |  |  |  |  |  |  |  |  |  |  |  |  |  |  |  |  |  |
| 23 | Y2 | Crystal_SMD_3225-4Pin_3.2x2.5mm | 1 | ABM8-25.000MHZ-10-D1G-T |  |  | 2 |  | x |  |  |  | ABM8-25.000MHZ-10-D1G-T | ABRACON | 2 | $0.84 | $1.68 | C5366868 | SMD3225-4P | 1 | 1 | 1000 | 436 | In Stock |  | �15ppm 10pF �10ppm SMD3225-4P Crystals RoHS | Exact Matches | https://www.lcsc.com/product-detail/C5366868.html |  |  |  |  |  |  |  |  |  |  |  |  |  |  |  |  |  |  |  |
| Id | Designator | Footprint | Quantity | Designation | Supplier and ref | Column1 | Needed quantity | - | LCSC | MOUSER | Already in another pcb | -- | Mrf# | Mfr. | Order Qty. | Unit Price(USD) | Ext.Price(USD) | LCSC#/MOUSER | Package | Min | Mult | SPQ | Availability | Stock Status | Customer Notes | Description | Matched status | Product Link |  |  |  |  |  |  |  |  |  |  |  |  |  |  |  |  |  |  |  |
| 5 | C1 | C_0603_1608Metric | 1 | 4u7 |  |  | 2 |  |  |  | x |  |  |  |  |  |  |  |  |  |  |  |  |  |  |  |  |  |  |  |  |  |  |  |  |  |  |  |  |  |  |  |  |  |  |  |  |
| 8 | C2 | C_0603_1608Metric | 1 | 100n |  |  | 2 |  |  |  | x |  |  |  |  |  |  |  |  |  |  |  |  |  |  |  |  |  |  |  |  |  |  |  |  |  |  |  |  |  |  |  |  |  |  |  |  |
| 4 | J1 | FPC-SMD_5034801200 | 1 | Conn_01x12_MountingPin |  |  | 2 |  | x |  |  |  | 5034801200 | MOLEX | 5 | $0.36 | $1.78 | C587969 | SMD,P=0.5mm,Surface Mount,Right Angle | 5 | 5 | 3000 | 19735 | In Stock |  | FFC/FPC Connector 12 Position 0.5mm Pitch Double-Sided Contacts, Top and Bottom Entry Surface Mount, Right Angle -40?~+85? | Exact Matches | https://www.lcsc.com/product-detail/C587969.html |  |  |  |  |  |  |  |  |  |  |  |  |  |  |  |  |  |  |  |
| 9 | J2 | IDC-Header_2x06_P2.54mm_Vertical | 1 | IDC |  |  | 2 |  |  |  | x |  |  |  |  |  |  |  |  |  |  |  |  |  |  |  |  |  |  |  |  |  |  |  |  |  |  |  |  |  |  |  |  |  |  |  |  |
| 3 | Q2 | SOT-23 | 1 | BSS138 |  |  | 2 |  | x |  |  |  | BSS138LT1G | onsemi | 10 | $0.04 | $0.41 | C82045 | SOT-23 | 10 | 10 | 3000 | 267340 | In Stock |  | N-Channel 50V 200mA 225mW Surface Mount SOT-23 | Exact Matches | https://www.lcsc.com/product-detail/C82045.html |  |  |  |  |  |  |  |  |  |  |  |  |  |  |  |  |  |  |  |
| 7 | R1 | R_0603_1608Metric | 1 | 10R |  |  | 2 |  |  |  | x |  |  |  |  |  |  |  |  |  |  |  |  |  |  |  |  |  |  |  |  |  |  |  |  |  |  |  |  |  |  |  |  |  |  |  |  |
| 2 | R2,R4,R3 | R_0603_1608Metric | 3 | 10k |  |  | 6 |  |  |  | x |  |  |  |  |  |  |  |  |  |  |  |  |  |  |  |  |  |  |  |  |  |  |  |  |  |  |  |  |  |  |  |  |  |  |  |  |
| 1 | SW2 | RotaryEncoder_Alps_EC11E-Switch_Vertical_H20mm | 1 | EC11E18244AU |  |  | 2 |  | x |  |  |  | EC11E18244AU | ALPSALPINE | 2 | $2.12 | $4.23 | C202365 | Through Hole | 1 | 1 | 120 | 2382 | In Stock |  | Through Hole Encoders RoHS | Exact Matches | https://www.lcsc.com/product-detail/C202365.html |  |  |  |  |  |  |  |  |  |  |  |  |  |  |  |  |  |  |  |
| 6 | U1 | SOT-23 | 1 | APX803S-31SA-7 |  |  | 2 |  | x |  |  |  | APX803S-31SA-7 | DIODES | 5 | $0.18 | $0.90 | C129757 | SOT-23 | 5 | 5 | 3000 | 4525 | In Stock |  | 240ms Active Low 1V~5.5V 1 SOT-23 Supervisors RoHS | Exact Matches | https://www.lcsc.com/product-detail/C129757.html |  |  |  |  |  |  |  |  |  |  |  |  |  |  |  |  |  |  |  |
| Id | Designator | Footprint | Quantity | Designation | Supplier and ref | Column1 | Needed quantity | - | LCSC | MOUSER | Already in another pcb | -- | Mrf# | Mfr. | Order Qty. | Unit Price(USD) | Ext.Price(USD) | LCSC#/MOUSER | Package | Min | Mult | SPQ | Availability | Stock Status | Customer Notes | Description | Matched status | Product Link |  |  |  |  |  |  |  |  |  |  |  |  |  |  |  |  |  |  |  |
| 6 | C1 | C_0603_1608Metric | 1 | 10u |  |  | 2 |  | x |  |  |  | CL10B106MQ8NRNC | Samsung Electro-Mechanics | 2 | $0.08 | $0.15 | C3039698 | 603 | 2 | 2 | 4000 | 25412 | In Stock |  | 10uF �20% 6.3V Ceramic Capacitor X7R 0603 | Exact Matches | https://www.lcsc.com/product-detail/C3039698.html |  |  |  |  |  |  |  |  |  |  |  |  |  |  |  |  |  |  |  |
| 7 | C10,C9 | C_0402_1005Metric | 2 | 14p |  |  | 4 |  | x |  |  |  | 0402CG140J500NT | FH | 100 | $0.00 | $0.16 | C3037644 | 402 | 100 | 100 | 10000 | 41300 | In Stock |  | 14pF �5% 50V Ceramic Capacitor C0G 0402 | Exact Matches | https://www.lcsc.com/product-detail/C3037644.html |  |  |  |  |  |  |  |  |  |  |  |  |  |  |  |  |  |  |  |
| 1 | C2,C4,C5,C3,C6 | C_0402_1005Metric | 5 | 100n |  |  | 10 |  |  |  | x |  |  |  |  |  |  |  |  |  |  |  |  |  |  |  |  |  |  |  |  |  |  |  |  |  |  |  |  |  |  |  |  |  |  |  |  |
| 5 | C7,C8 | C_0402_1005Metric | 2 | 3p |  |  | 4 |  | x |  |  |  | CC0402BRNPO9BN3R0 | YAGEO | 100 | $0.00 | $0.26 | C327228 | 402 | 100 | 100 | 10000 | 17400 | In Stock |  | 3pF 50V Ceramic Capacitor NP0 0402 | Exact Matches | https://www.lcsc.com/product-detail/C327228.html |  |  |  |  |  |  |  |  |  |  |  |  |  |  |  |  |  |  |  |
| 9 | J1 | U.FL_Molex_MCRF_73412-0110_Vertical | 1 | Conn_01x01_Shielded |  |  | 2 |  | x |  |  |  | 734120110 | MOLEX | 2 | $0.62 | $1.25 | C434806 | SMD | 1 | 1 | 5000 | 279 | In Stock |  | Connector Receptacle IPEX Male Pin Surface Mount | Exact Matches | https://www.lcsc.com/product-detail/C434806.html |  |  |  |  |  |  |  |  |  |  |  |  |  |  |  |  |  |  |  |
| 11 | J2 | PinHeader_2x04_P2.54mm_Vertical | 1 | Conn_02x04 |  |  | 2 |  | x |  |  |  | PZ254V-12-8P | XFCN | 10 | $0.04 | $0.40 | C492421 | Through Hole,P=2.54mm | 10 | 10 | 1000 | 148950 | In Stock |  | Pin Header 8 Position 2.54mm Pitch Dual Row Through Hole -40?~+105? | Exact Matches | https://www.lcsc.com/product-detail/C492421.html |  |  |  |  |  |  |  |  |  |  |  |  |  |  |  |  |  |  |  |
| 3 | L1 | L_0402_1005Metric | 1 | 2n |  |  | 2 |  | x |  |  |  | MLG1005S2N0BT000 | TDK | 10 | $0.01 | $0.09 | C76769 | 402 | 10 | 10 | 10000 | 67470 | In Stock |  | 900mA 2nH 70m? Multilayer inductor 0402 Fixed Inductors RoHS | Exact Matches | https://www.lcsc.com/product-detail/C76769.html |  |  |  |  |  |  |  |  |  |  |  |  |  |  |  |  |  |  |  |
| 4 | R1 | R_0402_1005Metric | 1 | 10k |  |  | 2 |  | x |  |  |  | RC0402FR-0710KL | YAGEO | 100 | $0.00 | $0.08 | C60490 | 402 | 100 | 100 | 10000 | 5173500 | In Stock |  | 62.5mW 10k? 50V Thick Film Resistor �100ppm/? �1% 0402 Chip Resistor - Surface Mount RoHS | Exact Matches | https://www.lcsc.com/product-detail/C60490.html |  |  |  |  |  |  |  |  |  |  |  |  |  |  |  |  |  |  |  |
| 2 | TP2,TP1 | TestPoint_Pad_D1.0mm | 2 | TestPoint |  |  | 4 |  |  |  |  |  |  |  |  |  |  |  |  |  |  |  |  |  |  |  |  |  |  |  |  |  |  |  |  |  |  |  |  |  |  |  |  |  |  |  |  |
| 8 | U1 | QFN-24-1EP_4x4mm_P0.5mm_EP2.8x2.8mm | 1 | ESP8684 |  |  | 2 |  | x |  |  |  | ESP8684H4X | ESPRESSIF | 2 | $1.54 | $3.08 | C48929155 | QFN-24(4x4) | 1 | 1 | 5000 | 4843 | In Stock |  | QFN-24(4x4) RF Transceiver ICs RoHS | Exact Matches | https://www.lcsc.com/product-detail/C48929155.html |  |  |  |  |  |  |  |  |  |  |  |  |  |  |  |  |  |  |  |
| 10 | Y1 | Crystal_SMD_SeikoEpson_FA128-4Pin_2.0x1.6mm | 1 | Q22FA12800230 |  |  | 2 |  |  |  |  |  | Q22FA12800230 | EPSON | 5 | $0.33 | $1.63 | C255886 | SMD2016-4P | 5 | 5 | 3000 | 1585 | In Stock |  | Crystal 26MHz �10ppm 10pF 60? SMD2016-4P | Exact Matches | https://www.lcsc.com/product-detail/C255886.html |  |  |  |  |  |  |  |  |  |  |  |  |  |  |  |  |  |  |  |
| x | x | x | 1 | IDC interconnect cable |  |  | 2 |  | x |  |  |  | IDC-265126-200-12P | DEALON | 2 | $0.30 | $0.60 | C7465811 | - | 1 | 1 | 250 | 119 | In Stock |  | Wire Wrap RoHS | Exact Matches | https://www.lcsc.com/product-detail/C7465811.html |  |  |  |  |  |  |  |  |  |  |  |  |  |  |  |  |  |  |  |
| x | x | x | 1 | 2 Inch 240x320 lcd display |  |  | 2 |  | x |  |  |  | HS20HS072RX | HS | 2 | $3.46 | $6.93 | C5329582 | - | 1 | 1 | 1 | 242 | In Stock |  | 2 320x240 ST7789 SPI LCD, OLED, Graphic RoHS | Exact Matches | https://www.lcsc.com/product-detail/C5329582.html |  |  |  |  |  |  |  |  |  |  |  |  |  |  |  |  |  |  |  |
|  |  |  |  | PKCELL Li-Po Battery 3.7V 2000mAh |  |  | 2 |  |  |  |  |  | Li-Po Battery 3.7V 2000mAh - JST-PH - LP803860 | PKCELL | 2 | $8.69 | $17.37 |  |  |  |  |  |  |  |  | Li-Po Battery 3.7V 2000mAh - JST-PH - LP803860 |  | https://www.tinytronics.nl/en/power/batteries/li-po/pkcell-li-po-battery-3.7v-2000mah-jst-ph-lp803860 |  |  |  |  |  |  |  |  |  |  |  |  |  |  |  |  |  |  |  |
|  |  |  |  |  |  |  |  |  |  |  |  |  | JLCPCB Main PCB inc. Stencil |  |  |  | $14.11 |  |  |  |  |  |  |  |  |  |  |  |  |  |  |  |  |  |  |  |  |  |  |  |  |  |  |  |  |  |  |
|  |  |  |  |  |  |  |  |  |  |  |  |  | JLCPCB WIFI PCB inc. Stencil |  |  |  | $5.05 |  |  |  |  |  |  |  |  |  |  |  |  |  |  |  |  |  |  |  |  |  |  |  |  |  |  |  |  |  |  |
|  |  |  |  |  |  |  |  |  |  |  |  |  | JLCPCB Display PCB inc. Stencil |  |  |  | $7.05 |  |  |  |  |  |  |  |  |  |  |  |  |  |  |  |  |  |  |  |  |  |  |  |  |  |  |  |  |  |  |
|  |  |  |  |  |  |  |  |  |  |  |  |  | shipping LCSC |  |  |  | $14.87 |  |  |  |  |  |  |  |  |  |  |  |  |  |  |  |  |  |  |  |  |  |  |  |  |  |  |  |  |  |  |
|  |  |  |  |  |  |  |  |  |  |  |  |  | Shipping JLCPCB |  |  |  | $14.89 |  |  |  |  |  |  |  |  |  |  |  |  |  |  |  |  |  |  |  |  |  |  |  |  |  |  |  |  |  |  |
|  |  |  |  |  |  |  |  |  |  |  |  |  | Shipping Tinytronics |  |  |  | $6.90 |  |  |  |  |  |  |  |  |  |  |  |  |  |  |  |  |  |  |  |  |  |  |  |  |  |  |  |  |  |  |
|  |  |  |  |  |  |  |  |  |  |  |  |  | Shipping Mouser |  |  |  | $- |  |  |  |  |  |  |  |  |  |  |  |  |  |  |  |  |  |  |  |  |  |  |  |  |  |  |  |  |  |  |
|  |  |  |  |  |  |  |  |  |  |  |  |  | Total |  |  |  | $269.39 |  |  |  |  |  |  |  |  |  |  |  |  |  |  |  |  |  |  |  |  |  |  |  |  |  |  |  |  |  |  |

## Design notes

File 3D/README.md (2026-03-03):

# 3D design

I used onshape so here is the link:

https://cad.onshape.com/documents/7a1aa90c6a7c74ef8699231e/w/3ea57ea1703701009a206be9/e/21fe65d6bda3912845cd8de3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

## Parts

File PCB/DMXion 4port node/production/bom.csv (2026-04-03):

Designator | Footprint | Quantity | Value | LCSC Part #
BT1 | JST_XH_B3B-XH-A_1x03_P2.50mm_Vertical | 1 | Battery_Cell
C1, C10, C11, C12, C13, C3, C4, C5, C6, C7, C8, C9 | 0402 | 12 | 100n
C14, C15, C16, C2 | 0402 | 4 | 4u7
C17, C19 | 0402 | 2 | 15p
C18, C25, C26, C27, C28, C29, C30, C31, C38, C39, C41, C60, C61, C64, C66, C67, C68, C69, C70, C71, C72, C73, C74, C75, C76, C77, C78, C79, C88 | 0603 | 29 | 100n
C20, C21, C23, C33, C57 | 0603 | 5 | 10n
C22, C34, C35, C36, C37, C43, C44, C45, C46, C47, C63, C65 | 0603 | 12 | 1n
C24, C32 | CP_EIA-2012-12_Kemet-R | 2 | 10u
C40, C42 | 0603 | 2 | 6.8n
C48, C49 | 0603 | 2 | 10p
C50, C51, C52 | 0805 | 3 | 1u
C53 | CP_Elec_6.3x5.8 | 1 | 10u
C54 | 0603 | 1 | 470p
C55 | CP_Elec_10x10.5 | 1 | 1000u
C56 | 1206 | 1 | 100u
C58 | 0603 | 1 | 4u7
C59 | 0603 | 1 | 3.3n
C62 | 0603 | 1 | 15n
C80, C84 | 0603 | 2 | 1u
C81, C82, C83, C86, C87, C89, C90 | 0603 | 7 | 10u
C85 | 0603 | 1 | 2u2
D1 | D_SOD-123F | 1 | DSK24L
D10 | D_SMA | 1 | SS34
D11 | D_SOD-123 | 1 | 1N4148W
D12 | D_SOD-123F | 1 | DFTL30A
D13 | LED-SMD_4P-L1.6-W1.5-TR | 1 | LED_ABGR
D2, D3, D4, D5, D6, D7, D8, D9 | D_SOD-123F | 8 | SL110PL-TP
IC1 | QFN-32-1EP_5x5mm_P0.5mm_EP3.45x3.45mm_ThermalVias | 1 | NPM1300-QEAA-R7
J1 | JST_SH_SM03B-SRSS-TB_1x03-1MP_P1.00mm_Horizontal | 1 | Conn_01x03_MountingPin
J10, J4, J6, J8 | NC5FAH1-LR-DAE | 4 | XLR5
J11, J5, J7, J9 | NC3FAH2-LR-DAE | 4 | XLR3
J12 | IDC-Header_2x06_P2.54mm_Vertical | 1 | IDC
J13 | PinSocket_2x04_P2.54mm_Vertical | 1 | Conn_02x04
J2 | USB-C_SMD-TYPE-C-31-M-12_1 | 1 | USB_C_Receptacle_USB2.0_14P
J3 | NE8FAHLRDAE | 1 | RJ45
L1 | L_pol_2016 | 1 | 3.3u
L2 | L_Vishay_IHLP-1616 | 1 | 1u
L3 | XFMR-SMD_16P-L12.7-W7.1-P1.27-LS9.4-BL | 1 | H2019NLT | C110250
L4, L5 | 0805 | 2 | 2u2
LED1, LED10, LED2, LED3, LED4, LED5, LED6, LED7, LED8, LED9 | LED-SMD_4P-L1.5-W1.5-BL | 10 | SK6805-EC15 | C2890035
R1, R25, R3 | 0603 | 3 | 1k
R10, R11, R12, R13 | 0603 | 4 | 33R
R14 | 0603 | 1 | 1M
R15, R20, R21, R38, R8 | 0603 | 5 | 0R
R16 | 0603 | 1 | 10R
R17 | 0603 | 1 | 12.4k
R18 | 0603 | 1 | 4.99k
R19 | 0603 | 1 | 2.05k
R2 | 0402 | 1 | 33R
R22 | 0603 | 1 | 36.5k
R23 | 0603 | 1 | 12.1k
R24 | 0603 | 1 | 24.9k
R26, R27, R28, R29, R34, R35, R36, R37 | 0603 | 8 | 348R
R30, R31, R32, R33 | 0603 | 4 | 133R
R39 | 0603 | 1 | 430k
R4, R5 | 0402 | 2 | 27R
R40, R41, R7, R9 | 0603 | 4 | 10k
R6 | 0402 | 1 | 1k
RN1, RN2 | R_Array_Concave_4x0603 | 2 | 75R
RN3 | R_Array_Concave_4x0603 | 1 | 10k
SW1, SW2 | SW_SPST_B3U-1000P | 2 | SW_Push
T1 | FA2924ALD | 1 | FA2805
TP1, TP10, TP11, TP12, TP13, TP14, TP15, TP16, TP17, TP18, TP19, TP2, TP20, TP21, TP22, TP23, TP24, TP25, TP26, TP27, TP28, TP29, TP3, TP30, TP31, TP32, TP33, TP34, TP35, TP36, TP37, TP38, TP39, TP4, TP40, TP41, TP42, TP43, TP44, TP45, TP46, TP47, TP48, TP49, TP5, TP50, TP51, TP52, TP53, TP54, TP55, TP56, TP57, TP58, TP59, TP6, TP60, TP61, TP62, TP7, TP8, TP9 | TestPoint_Pad_D1.5mm | 62 | TestPoint
U1 | RP2350-QFN-80-1EP_10x10_P0.4mm_EP3.4x3.4mm_ThermalVias | 1 | RP2350B
U10, U11, U8, U9 | SOIC-8_3.9x4.9mm_P1.27mm | 4 | MAX3485
U12 | SOT-363_SC-70-6 | 1 | TXS0101DCK
U13 | SOT-223-3_TabPin2 | 1 | AP7361C-33E
U2 | SOIC-8_5.3x5.3mm_P1.27mm | 1 | W25Q128JVS
U3 | SOT-23-6 | 1 | USBLC6-2SC6
U4 | LQFP-48_7x7mm_P0.5mm | 1 | W5500
U5 | SMDIP-4_W9.53mm_Clearance8mm | 1 | VO618A-3X019T
U6 | QFN-20_L5.0-W5.0-P0.80-TL-EP2.8 | 1 | SI3402-B-GMR | C510771
U7 | TSOT-23 | 1 | TLV431
Y1 | Crystal_SMD_3225-4Pin_3.2x2.5mm | 1 | ABM8-272-T3
Y2 | Crystal_SMD_3225-4Pin_3.2x2.5mm | 1 | ABM8-25.000MHZ-10-D1G-T

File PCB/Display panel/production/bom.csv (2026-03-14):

Designator | Footprint | Quantity | Value | LCSC Part #
C1_2, C1 | 0603 | 2 | 4u7
C2_2, C2 | 0603 | 2 | 100n
J1_2, J1 | FPC-SMD_5034801200 | 2 | Conn_01x12_MountingPin
J2_2, J2 | IDC-Header_2x06_P2.54mm_Vertical | 2 | IDC
Q2_2, Q2 | SOT-23 | 2 | BSS138
R1_2, R1 | 0603 | 2 | 10R
R2_2, R2, R3_2, R3, R4_2, R4 | 0603 | 6 | 10k
SW2_2, SW2 | RotaryEncoder_Alps_EC11E-Switch_Vertical_H20mm | 2 | EC11E18244AU
U1_2, U1 | SOT-23 | 2 | APX803S-31SA-7 | C129757

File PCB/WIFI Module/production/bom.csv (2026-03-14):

Designator | Footprint | Quantity | Value | LCSC Part #
C1_8, C1_7, C1_6, C1_5, C1_4, C1_3, C1_2, C1 | 0603 | 8 | 10u
C10_8, C10_7, C10_6, C10_5, C10_4, C10_3, C10_2, C10, C9_8, C9_7, C9_6, C9_5, C9_4, C9_3, C9_2, C9 | 0402 | 16 | 14p
C2_8, C2_7, C2_6, C2_5, C2_4, C2_3, C2_2, C2, C3_8, C3_7, C3_6, C3_5, C3_4, C3_3, C3_2, C3, C4_8, C4_7, C4_6, C4_5, C4_4, C4_3, C4_2, C4, C5_8, C5_7, C5_6, C5_5, C5_4, C5_3, C5_2, C5, C6_8, C6_7, C6_6, C6_5, C6_4, C6_3, C6_2, C6 | 0402 | 40 | 100n
C7_8, C7_7, C7_6, C7_5, C7_4, C7_3, C7_2, C7, C8_8, C8_7, C8_6, C8_5, C8_4, C8_3, C8_2, C8 | 0402 | 16 | 3p
J1_8, J1_7, J1_6, J1_5, J1_4, J1_3, J1_2, J1 | U.FL_Molex_MCRF_73412-0110_Vertical | 8 | Conn_01x01_Shielded
J2_8, J2_7, J2_6, J2_5, J2_4, J2_3, J2_2, J2 | PinHeader_2x04_P2.54mm_Vertical | 8 | Conn_02x04
L1_8, L1_7, L1_6, L1_5, L1_4, L1_3, L1_2, L1 | 0402 | 8 | 2n
R1_8, R1_7, R1_6, R1_5, R1_4, R1_3, R1_2, R1 | 0402 | 8 | 10k
TP1_8, TP1_7, TP1_6, TP1_5, TP1_4, TP1_3, TP1_2, TP1, TP2_8, TP2_7, TP2_6, TP2_5, TP2_4, TP2_3, TP2_2, TP2 | TestPoint_Pad_D1.0mm | 16 | TestPoint
U1_8, U1_7, U1_6, U1_5, U1_4, U1_3, U1_2, U1 | QFN-24-1EP_4x4mm_P0.5mm_EP2.8x2.8mm | 8 | ESP8684
Y1_8, Y1_7, Y1_6, Y1_5, Y1_4, Y1_3, Y1_2, Y1 | Crystal_SMD_SeikoEpson_FA128-4Pin_2.0x1.6mm | 8 | Q22FA12800230

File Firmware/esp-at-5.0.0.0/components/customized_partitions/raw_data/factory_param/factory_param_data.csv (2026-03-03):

platform | module_name | description | version | max_tx_power | uart_port | start_channel | channel_num | country_code | uart_baudrate | uart_tx_pin | uart_rx_pin | uart_cts_pin | uart_rts_pin | sys_store
PLATFORM_ESP32 | WROOM-32 | 4MB, Wi-Fi + BLE, OTA, TX:17 RX:16 | 4 | 78 | 1 | 1 | 13 | CN | 115200 | 17 | 16 | 15 | 14 | 1
PLATFORM_ESP32 | PICO-D4 | 4MB, Wi-Fi + BLE, OTA, TX:22 RX:19 | 4 | 78 | 1 | 1 | 13 | CN | 115200 | 22 | 19 | 15 | 14 | 1
PLATFORM_ESP32 | MINI-1 | 4MB, Wi-Fi + BLE, OTA, TX:22 RX:19 | 4 | 78 | 1 | 1 | 13 | CN | 115200 | 22 | 19 | 15 | 14 | 1
PLATFORM_ESP32 | ESP32-SDIO | 4MB, Wi-Fi + BLE, OTA, communicate with MCU via SDIO | 4 | 78 | -1 | 1 | 13 | CN | -1 | -1 | -1 | -1 | -1 | 1
PLATFORM_ESP32 | ESP32-D2WD | 2MB, Wi-Fi + BLE, No OTA, TX:22 RX:19 | 4 | 78 | 1 | 1 | 13 | CN | 115200 | 22 | 19 | 15 | 14 | 1
PLATFORM_ESP32 | SOLO-1 | Not recommended for new design. 4MB, Wi-Fi + BLE, OTA, TX:17 RX:16 | 4 | 78 | 1 | 1 | 13 | CN | 115200 | 17 | 16 | 15 | 14 | 1
PLATFORM_ESP32 | WROVER-32 | Not recommended for new design. 4MB, Wi-Fi + BLE, OTA, TX:22 RX:19 | 4 | 78 | 1 | 1 | 13 | CN | 115200 | 22 | 19 | 15 | 14 | 1
PLATFORM_ESP32C3 | MINI-1 | 4MB, Wi-Fi + BLE, OTA, TX:7 RX:6 | 4 | 78 | 1 | 1 | 13 | CN | 115200 | 7 | 6 | 5 | 4 | 1
PLATFORM_ESP32C3 | ESP32C3-SPI | 4MB, Wi-Fi + BLE, OTA, communicate with MCU via SPI | 4 | 78 | -1 | 1 | 13 | CN | -1 | -1 | -1 | -1 | -1 | 1
PLATFORM_ESP32C3 | ESP32C3_RAINMAKER | 4MB, RainMaker, Compress OTA, TX:7 RX:6 | 4 | 78 | 1 | 1 | 13 | CN | 115200 | 7 | 6 | 5 | 4 | 1
PLATFORM_ESP32C2 | ESP32C2-2MB | 2MB, Wi-Fi, Compress OTA, All ECOs, TX:7 RX:6 | 4 | 78 | 1 | 1 | 13 | CN | 115200 | 7 | 6 | 19 | 20 | 1
PLATFORM_ESP32C2 | ESP32C2-4MB | 4MB, Wi-Fi + BluFi, OTA, All ECOs, TX:7 RX:6 | 4 | 78 | 1 | 1 | 13 | CN | 115200 | 7 | 6 | 5 | 4 | 1
PLATFORM_ESP32C2 | ESP32C2-2MB-BLE | 2MB, BLE, No OTA, All ECOs, TX:7 RX:6 | 4 | 78 | 1 | 1 | 13 | CN | 115200 | 7 | 6 | 5 | 4 | 1
PLATFORM_ESP32C2 | ESP32C2-2MB-G2 | 2MB, Wi-Fi, Compress OTA, ECO4, TX:7 RX:6 | 4 | 78 | 1 | 1 | 13 | CN | 115200 | 7 | 6 | 19 | 20 | 1
PLATFORM_ESP32C2 | ESP32C2-4MB-G2 | 4MB, Wi-Fi + BluFi, OTA, ECO4, TX:7 RX:6 | 4 | 78 | 1 | 1 | 13 | CN | 115200 | 7 | 6 | 5 | 4 | 1
PLATFORM_ESP32C2 | ESP32C2-2MB-BLE-G2 | 2MB, BLE, No OTA, ECO4, TX:7 RX:6 | 4 | 78 | 1 | 1 | 13 | CN | 115200 | 7 | 6 | 5 | 4 | 1
PLATFORM_ESP32C2 | ESP32C2-2MB-NO-OTA-G2 | 2MB, Wi-Fi + BLE, No OTA, ECO4, TX:7 RX:6 | 4 | 78 | 1 | 1 | 13 | CN | 115200 | 7 | 6 | 5 | 4 | 1
PLATFORM_ESP32C5 | ESP32C5-4MB | 4MB, Wi-Fi + BLE, OTA, TX:23 RX:24 | 4 | 78 | 1 | 1 | 13 | CN | 115200 | 23 | 24 | 25 | 26 | 1
PLATFORM_ESP32C5 | ESP32C5-SDIO | 4MB, Wi-Fi + BLE, OTA, communicate with MCU via SDIO | 4 | 78 | -1 | 1 | 13 | CN | -1 | -1 | -1 | -1 | -1 | 1
PLATFORM_ESP32C5 | ESP32C5-SPI | 4MB, Wi-Fi + BLE, OTA, communicate with MCU via SPI | 4 | 78 | 1 | 1 | 13 | CN | -1 | -1 | -1 | -1 | -1 | 1
PLATFORM_ESP32C6 | ESP32C6-4MB | 4MB, Wi-Fi + BLE, OTA, TX:7 RX:6 | 4 | 78 | 1 | 1 | 13 | CN | 115200 | 7 | 6 | 5 | 4 | 1
PLATFORM_ESP32C61 | ESP32C61-4MB | 4MB, Wi-Fi + BLE, OTA, TX:7 RX:6 | 4 | 78 | 1 | 1 | 13 | CN | 115200 | 7 | 6 | 5 | 4 | 1
PLATFORM_ESP32S2 | MINI | 4MB, Wi-Fi, OTA, TX:17 RX:21 | 4 | 78 | 1 | 1 | 13 | CN | 115200 | 17 | 21 | 20 | 19 | 1

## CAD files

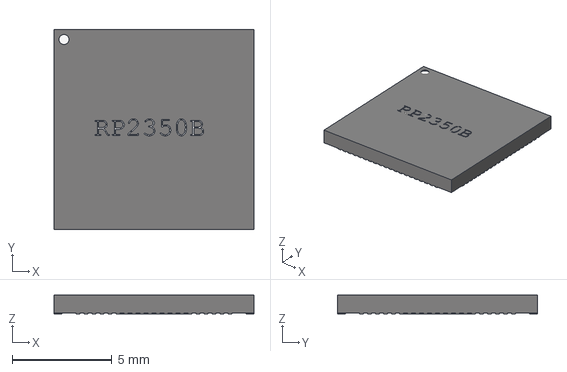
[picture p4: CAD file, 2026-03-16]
PCB/DMXion 4port node/RP2350_3D/RP2350_QFN80.step
10.0 x 10.0 x 0.95 mm

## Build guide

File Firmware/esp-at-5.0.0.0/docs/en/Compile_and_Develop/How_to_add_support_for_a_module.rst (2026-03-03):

How to Add Support for a Module
============================================

:link_to_translation:`zh_CN:[中文]`

The ESP-AT project supports multiple modules, and provides configuration for them in the :component_file:`factory_param_data.csv <customized_partitions/raw_data/factory_param/factory_param_data.csv>` table and the files in the :project:`module_config` folder. If you want to add support for an {IDF_TARGET_NAME} module in your ESP-AT project, you need to modify those configuration files. The "{IDF_TARGET_NAME} module" here means:

- Modules that the ESP-AT project has not supported yet, including those of supported platform and not supported platform. However, adding support for the latter requires extra huge work, thus not recommended and not explained in this document.

- Modules that the ESP-AT project supports, but you want to modify the default configuration.

.. only:: esp32c2 or esp32c3 or esp32c5 or esp32c6 or esp32c61

  The document uses an example to explain how to add support for an {IDF_TARGET_NAME} module in the ESP-AT project. The example module is {IDF_TARGET_NAME}-MINI-1 that uses SPI instead of the default UART interface.

.. only:: esp32 or esp32s2

  This document will explain how to add new module support for a {IDF_TARGET_NAME} chip/module that ESP-AT already supports in the ESP-AT project. The following example will enable the default :ref:`FileSystem AT commands <FS-AT>` and add support for a new module.

.. contents::
   :local:
   :depth: 1

Step 1: Configure the Factory Parameters for the New Module
-----------------------------------------------------------------------------

Open your local :component_file:`factory_param_data.csv <customized_partitions/raw_data/factory_param/factory_param_data.csv>`, insert a new row at the end, and set the relevant parameters as needed. In this example, we set ``platform`` to ``PLATFORM_{IDF_TARGET_CFG_PREFIX}`` and ``module_name`` to ``{IDF_TARGET_CFG_PREFIX}-USER-DEFINED``. The values for other parameters are shown in the table below (for parameter meanings, please refer to :ref:`factory-param-intro`).

- platform: PLATFORM_{IDF_TARGET_CFG_PREFIX}
- module_name: {IDF_TARGET_CFG_PREFIX}-USER-DEFINED
- description:
- version: 4
- max_tx_power: 78
- uart_port: 1
- start_channel: 1
- channel_num: 13
- country_code: CN
- uart_baudrate: -1
- uart_tx_pin: -1
- uart_rx_pin: -1
- uart_cts_pin: -1
- uart_rts_pin: -1

Step 2: Configure OTA for the Newly Added Module
----------------------------------------------------

Add customized module information in the ``s_module_info`` structure in :component_file:`at/src/at_default_config.c`.

The ``s_module_info`` structure provides ``OTA`` upgrade verification ``token``:

.. code-block:: c

    typedef struct {
        char* module_name;
        char* ota_token;
        char* ota_ssl_token;
    } at_module_info_t;

If you do not want to use ``OTA`` features, member 2 ``ota_token`` and member 3 ``ota_ssl_token`` should be set to ``NULL``. Member 1 ``module_name`` must correspond to the field ``module_name`` in the factory_param_data.csv file.

The modified ``s_module_info`` structure is as follows:

.. code-block:: c

    static const at_module_info_t s_module_info[] = {
    #if defined(CONFIG_IDF_TARGET_ESP32)
      ...
    #endif

    #if defined(CONFIG_IDF_TARGET_ESP32C3)
      ...
    #endif

    #if defined(CONFIG_IDF_TARGET_ESP32C2)
      ...
    #endif

    #if defined(CONFIG_IDF_TARGET_ESP32C5)
      ...
    #endif

    #if defined(CONFIG_IDF_TARGET_ESP32C6)
      ...
    #endif

    #if defined(CONFIG_IDF_TARGET_{IDF_TARGET_CFG_PREFIX})
      {"MY_MODULE",       CONFIG_ESP_AT_OTA_TOKEN_MY_MODULE,      CONFIG_ESP_AT_OTA_SSL_TOKEN_MY_MODULE },     // MY_MODULE
    #endif
    };

Macro ``CONFIG_ESP_AT_OTA_TOKEN_MY_MODULE`` and macro ``CONFIG_ESP_AT_OTA_SSL_TOKEN_MY_MODULE`` are defined in the header file :component_file:`at/private_include/at_ota_token.h`.

.. code-block:: none

    #if defined(CONFIG_IDF_TARGET_{IDF_TARGET_CFG_PREFIX})
    ...
    #define CONFIG_ESP_AT_OTA_TOKEN_MY_MODULE       CONFIG_ESP_AT_OTA_TOKEN_DEFAULT

    ...
    #define CONFIG_ESP_AT_OTA_SSL_TOKEN_MY_MODULE       CONFIG_ESP_AT_OTA_SSL_TOKEN_DEFAULT

Step 3: Add New Module Configuration
------------------------------------------------

The ESP-AT project supports multiple platforms, each of which supports multiple module configurations and provides configuration files for each module configuration: :component_file:`factory_param_data.csv <customized_partitions/raw_data/factory_param/factory_param_data.csv>` and :project:`module_config`. The table below lists the names of the platforms (i.e., chip series) supported by the ESP-AT project, the names of the module configurations, and the locations of the corresponding configuration files for each module configuration.

.. list-table::
   :header-rows: 1
   :widths: 5 10 40

   * - Platform
     - Module Configuration Name
     - Corresponding Default Configuration File
   * - ESP32
     - WROOM-32
     - - :project_file:`module_config/module_esp32_default/sdkconfig.defaults`
       - :project_file:`module_config/module_esp32_default/sdkconfig_silence.defaults`
   * - ESP32
     - PICO-D4
     - - :project_file:`module_config/module_esp32_default/sdkconfig.defaults`
       - :project_file:`module_config/module_esp32_default/sdkconfig_silence.defaults`
   * - ESP32
     - SOLO-1
     - - :project_file:`module_config/module_esp32_default/sdkconfig.defaults`
       - :project_file:`module_config/module_esp32_default/sdkconfig_silence.defaults`
   * - ESP32
     - MINI-1
     - - :project_file:`module_config/module_esp32_default/sdkconfig.defaults`
       - :project_file:`module_config/module_esp32_default/sdkconfig_silence.defaults`
   * - ESP32
     - WROVER-32
     - - :project_file:`module_config/module_wrover-32/sdkconfig.defaults`
       - :project_file:`module_config/module_wrover-32/sdkconfig_silence.defaults`
   * - ESP32
     - ESP32-D2WD
     - - :project_file:`module_config/module_esp32-d2wd/sdkconfig.defaults`
       - :project_file:`module_config/module_esp32-d2wd/sdkconfig_silence.defaults`
   * - ESP32
     - ESP32-SDIO
     - - :project_file:`module_config/module_esp32-sdio/sdkconfig.defaults`
       - :project_file:`module_config/module_esp32-sdio/sdkconfig_silence.defaults`
   * - ESP32-C2
     - ESP32C2-2MB
     - - :project_file:`module_config/module_esp32c2-2mb/sdkconfig.defaults`
       - :project_file:`module_config/module_esp32c2-2mb/sdkconfig_silence.defaults`
   * - ESP32-C2
     - ESP32C2-2MB-BLE
     - - :project_file:`module_config/module_esp32c2-2mb-ble/sdkconfig.defaults`
       - :project_file:`module_config/module_esp32c2-2mb-ble/sdkconfig_silence.defaults`
   * - ESP32-C2
     - ESP32C2-4MB
     - - :project_file:`module_config/module_esp32c2_default/sdkconfig.defaults`
       - :project_file:`module_config/module_esp32c2_default/sdkconfig_silence.defaults`
   * - ESP32-C3
     - MINI-1
     - - :project_file:`module_config/module_esp32c3_default/sdkconfig.defaults`
       - :project_file:`module_config/module_esp32c3_default/sdkconfig_silence.defaults`
   * - ESP32-C3
     - ESP32C3-SPI
     - - :project_file:`module_config/module_esp32c3-spi/sdkconfig.defaults`
       - :project_file:`module_config/module_esp32c3-spi/sdkconfig_silence.defaults`
   * - ESP32-C3
     - ESP32C3_RAINMAKER
     - - :project_file:`module_config/module_esp32c3_rainmaker/sdkconfig.defaults`
       - :project_file:`module_config/module_esp32c3_rainmaker/sdkconfig_silence.defaults`
   * - ESP32-C5
     - ESP32C5-4MB
     - - :project_file:`module_config/module_esp32c5_default/sdkconfig.defaults`
       - :project_file:`module_config/module_esp32c5_default/sdkconfig_silence.defaults`
   * - ESP32-C6
     - ESP32C6-4MB
     - - :project_file:`module_config/module_esp32c6_default/sdkconfig.defaults`
       - :project_file:`module_config/module_esp32c6_default/sdkconfig_silence.defaults`
   * - ESP32-C61
     - ESP32C61-4MB
     - - :project_file:`module_config/module_esp32c61_default/sdkconfig.defaults`
       - :project_file:`module_config/module_esp32c61_default/sdkconfig_silence.defaults`

.. note::

  - When the ``silence mode`` in :ref:`python build.py install <esp-at-install-env>` is ``0``, the default sdkconfig corresponding to the module is ``sdkconfig.defaults``.
  - When the ``silence mode`` in :ref:`python build.py install <esp-at-install-env>` is ``1``, the default sdkconfig corresponding to the module is ``sdkconfig_silence.defaults``.

Firstly, enter ``module_config`` folder, and create a new folder to store all the configuration files for your module. Note that the folder name should be in lower case. Then, add the configuration files in the new folder: IDF_VERSION, patch, at_customize.csv, partitions_at.csv, sdkconfig.defaults, and sdkconfig_silence.defaults.

In this example, we copy the ``module_{IDF_TARGET_PATH_NAME}_default`` folder as well as the files within it and rename it as ``module_{IDF_TARGET_PATH_NAME}-user-defined``. The copied IDF_VERSION, patch, at_customize.csv, and partitions_at.csv do not need any modification in our case. We only need to modify the sdkconfig.defaults and sdkconfig_silence.defaults:

- Modify the two files to use the partition table in the ``module_{IDF_TARGET_PATH_NAME}-user-defined`` folder as follows:

  ::

    CONFIG_PARTITION_TABLE_CUSTOM_FILENAME="module_config/module_{IDF_TARGET_PATH_NAME}-user-defined/partitions_at.csv"
    CONFIG_PARTITION_TABLE_FILENAME="module_config/module_{IDF_TARGET_PATH_NAME}-user-defined/partitions_at.csv"
    CONFIG_AT_CUSTOMIZED_PARTITION_TABLE_FILE="module_config/module_{IDF_TARGET_PATH_NAME}-user-defined/at_customize.csv"

.. only:: esp32c2 or esp32c3 or esp32c5 or esp32c6 or esp32c61

  - Modify the two files to use the SPI configuration and remove the UART configuration as follows:
  
    - Remove the UART configuration
    
      ::
  
        CONFIG_AT_BASE_ON_UART=n
  
    - Add the SPI configuration
  
      ::

        CONFIG_AT_BASE_ON_SPI=y
        CONFIG_SPI_STANDARD_MODE=y
        CONFIG_SPI_SCLK_PIN=6
        CONFIG_SPI_MOSI_PIN=7
        CONFIG_SPI_MISO_PIN=2
        CONFIG_SPI_CS_PIN=10
        CONFIG_SPI_HANDSHAKE_PIN=3
        CONFIG_SPI_NUM=1
        CONFIG_SPI_MODE=0
        CONFIG_TX_STREAM_BUFFER_SIZE=4096
        CONFIG_RX_STREAM_BUFFER_SIZE=4096

.. only:: esp32 or esp32s2

  - Add support for :ref:`FileSystem AT commands <FS-AT>` configuration

    ::
  
      CONFIG_AT_FS_COMMAND_SUPPORT=y

After completing the above steps, you can recompile the ESP-AT project to generate the module firmware. In this example, when we compile the AT firmware locally during :ref:`Step 3: Install Environment <esp-at-install-env>`, we can select ``PLATFORM_{IDF_TARGET_CFG_PREFIX}`` and ``{IDF_TARGET_CFG_PREFIX}-USER-DEFINED`` to generate the AT firmware.

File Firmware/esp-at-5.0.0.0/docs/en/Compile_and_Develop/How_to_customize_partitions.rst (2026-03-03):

How to Customize Partitions
===========================

{IDF_TARGET_AT_SECOND_PARTITION_ADDR: default="undefined", esp32="0x20000", esp32c2="0x1E000", esp32c3="0x1E000", esp32c5="0x30000", esp32c6="0x1E000", esp32c61="0x30000", esp32s2="0x20000"}
{IDF_TARGET_PRODUCT_NAME: default="undefined", esp32="ESP32-WROOM-32", esp32c2="ESP8684-MINI-1 4MB", esp32c3="ESP32-C3-MINI-1", esp32c5="ESP32-C5-WROOM-1", esp32c6="ESP32-C6-MINI-1", esp32c61="ESP32-C61-WROOM-1", esp32s2="ESP32-S2-MINI"}

:link_to_translation:`zh_CN:[中文]`

This document describes how to customize the partitions in your {IDF_TARGET_NAME} by modifying the at_customize.csv table provided by ESP-AT. There are two partition tables: the primary partition and the secondary partition table.

The primary partition table partitions_at.csv is for system usage, based on which the partitions_at.bin file is generated. If the primary partition table goes wrong, the system will fail to startup. Therefore, it is not recommended to modify the partitions_at.csv.

ESP-AT provides a secondary partition table at_customize.csv that you can customize to store self-defined blocks of data. It is based on the primary partition table.

To modify the partition in your {IDF_TARGET_NAME}, please follow the first three steps. The fourth section illustrates the three steps with an example.

- :ref:`modify-at-customize-csv`
- :ref:`generate-at-customize-bin`
- :ref:`flash-at-customize-bin-into-ESP`
- :ref:`customize-partition-example`

.. _modify-at-customize-csv:

Modify at_customize.csv
-----------------------

Find the at_customize.csv for your module with reference to the following table.

.. only:: esp32

  .. list-table:: at_customize.csv paths
    :header-rows: 1

    * - Platform
      - Module
      - Path
    * - ESP32
      - - WROOM-32
        - PICO-D4
        - SOLO-1
        - MINI-1
      - :project_file:`module_config/module_esp32_default/at_customize.csv`
    * - ESP32
      - WROVER-32
      - :project_file:`module_config/module_wrover-32/at_customize.csv`
    * - ESP32
      - ESP32-D2WD
      - :project_file:`module_config/module_esp32-d2wd/at_customize.csv`

.. only:: esp32c2

  .. list-table:: at_customize.csv paths
    :header-rows: 1

    * - Platform
      - Module
      - Path
    * - ESP32-C2
      - ESP32C2-2MB (all ESP32-C2 (ESP8684) series with 2 MB flash)
      - :project_file:`module_config/module_esp32c2-2mb/at_customize.csv`
    * - ESP32-C2
      - ESP32C2-4MB (all ESP32-C2 (ESP8684) series with 4 MB flash)
      - :project_file:`module_config/module_esp32c2_default/at_customize.csv`

.. only:: esp32c3

  .. list-table:: at_customize.csv paths
    :header-rows: 1

    * - Platform
      - Module
      - Path
    * - ESP32-C3
      - MINI-1
      - :project_file:`module_config/module_esp32c3_default/at_customize.csv`

.. only:: esp32c5

  .. list-table:: at_customize.csv paths
    :header-rows: 1

    * - Platform
      - Module
      - Path
    * - ESP32-C5
      - ESP32C5-4MB (all ESP32-C5 series with 4 MB flash)
      - :project_file:`module_config/module_esp32c5_default/at_customize.csv`

.. only:: esp32c6

  .. list-table:: at_customize.csv paths
    :header-rows: 1

    * - Platform
      - Module
      - Path
    * - ESP32-C6
      - ESP32C6-4MB (all ESP32-C6 series with 4 MB flash)
      - :project_file:`module_config/module_esp32c6_default/at_customize.csv`

.. only:: esp32c61

  .. list-table:: at_customize.csv paths
    :header-rows: 1

    * - Platform
      - Module
      - Path
    * - ESP32-C61
      - ESP32C61-4MB (all ESP32-C61 series with 4 MB flash)
      - :project_file:`module_config/module_esp32c61_default/at_customize.csv`

.. only:: esp32s2

  .. list-table:: at_customize.csv paths
    :header-rows: 1

    * - Platform
      - Module
      - Path
    * - ESP32-S2
      - MINI (all ESP32-S2 series with 4 MB flash)
      - :project_file:`module_config/module_esp32s2_default/at_customize.csv`

Then, follow the rules below when modifying at_customize.csv.

- Do not change the ``Name`` and ``Type`` of the user partitions that have already been defined in it, while ``SubType``, ``Offset``, and ``Size`` can be changed.
- If you need to add a new user partition, please check if it has already been defined in the ESP-IDF (``esp_partition.h``) first.

    - If yes, you should keep the ``Type`` value the same as that of ESP-IDF.
    - If no, please set the ``Type`` to ``0x40``.
- A user partition's ``Name`` should not be longer than ``16`` bytes.
- The default size of the entire ``at_customize`` partition is defined in the partitions_at.csv table. Please do not exceed the range when adding new user partitions.

.. _generate-at-customize-bin:

Generate at_customize.bin
--------------------------

After having modified the at_customize.csv, you can either recompile the ESP-AT project to generate the at_customize.bin file, or use the python script ``gen_esp32part.py``.

If you use the script, execute the following command under the root directory of ESP-AT project and replace ``INPUT`` and ``OUTPUT``:

::

    python esp-idf/components/partition_table/gen_esp32part.py <INPUT> [OUTPUT]

- Replace ``INPUT`` with the path to at_customize.csv or the binary file to parse.
- Replace ``OUTPUT`` with the path to output converted binary or CSV file. Stdout will be used if omitted.

.. _flash-at-customize-bin-into-ESP:

Flash at_customize.bin into {IDF_TARGET_NAME} Device
----------------------------------------------------

Download the at_customize.bin into flash. Please refer to :ref:`flash-at-firmware-into-your-device` for how to flash bin files into {IDF_TARGET_NAME} device and the following table for the download address for your module.

.. only:: esp32

  .. list-table:: Download Address of at_customize.bin in Modules
    :header-rows: 1

    * - Platform
      - Module
      - Address
      - Size
    * - ESP32
      - - WROOM-32
        - WROVER-32
        - PICO-D4
        - SOLO-1
        - MINI-1
        - ESP32-D2WD
      - 0x20000
      - 0xE0000

.. only:: esp32c2

  .. list-table:: Download Address of at_customize.bin in Modules
    :header-rows: 1

    * - Platform
      - Module
      - Address
      - Size
    * - ESP32-C2
      - ESP32C2-2MB (all ESP32-C2 (ESP8684) series with 2 MB flash)
      - 0x1A000
      - 0x26000
    * - ESP32-C2
      - ESP32C2-4MB (all ESP32-C2 (ESP8684) series with 4 MB flash)
      - {IDF_TARGET_AT_SECOND_PARTITION_ADDR}
      - 0x42000

.. only:: esp32c3

  .. list-table:: Download Address of at_customize.bin in Modules
    :header-rows: 1

    * - Platform
      - Module
      - Address
      - Size
    * - ESP32-C3
      - MINI-1
      - 0x1E000
      - 0x42000

.. only:: esp32c6

  .. list-table:: Download Address of at_customize.bin in Modules
    :header-rows: 1

    * - Platform
      - Module
      - Address
      - Size
    * - {IDF_TARGET_NAME}
      - {IDF_TARGET_CFG_PREFIX}-4MB (all {IDF_TARGET_NAME} series with 4 MB flash)
      - 0x1E000
      - 0x42000

.. only:: esp32c5 or esp32c61

  .. list-table:: Download Address of at_customize.bin in Modules
    :header-rows: 1

    * - Platform
      - Module
      - Address
      - Size
    * - {IDF_TARGET_NAME}
      - {IDF_TARGET_CFG_PREFIX}-4MB (all {IDF_TARGET_NAME} series with 4 MB flash)
      - 0x30000
      - 0x70000

.. only:: esp32s2

  .. list-table:: Download Address of at_customize.bin in Modules
    :header-rows: 1

    * - Platform
      - Module
      - Address
      - Size
    * - ESP32-S2
      - MINI
      - 0x20000
      - 0xE0000

There are cases where at_customize.bin must be downloaded to flash in order to use certain AT commands:

- :ref:`cmd-SYSFLASH`
- :ref:`cmd-FS`
- ``SSL`` server relevant commands
- ``BLE`` server relevant commands

.. _customize-partition-example:

Example
-------

The section demonstrates how to add a 4 KB partition named ``test`` into the {IDF_TARGET_PRODUCT_NAME} module.

Firstly, find the at_customize.csv table for {IDF_TARGET_PRODUCT_NAME} and set the ``Name``, ``Type``, ``Subtype``, ``Offset``, and ``Size`` of the new partition:

.. only:: esp32 or esp32s2

  ::

      # Name,Type,SubType,Offset,Size
      ... ...
      test,0x40,15,0x3D000,4K
      fatfs,data,fat,0x70000,576K

.. only:: esp32c2 or esp32c3 or esp32c5 or esp32c6 or esp32c61

  ::

      # Name,Type,SubType,Offset,Size
      ... ...
      test,0x40,15,0x3E000,4K
      fatfs,data,fat,0x47000,100K

Secondly, recompile the ESP-AT project, or execute the python script in the ESP-AT root directory to generate at_customize.bin.

::

    python esp-idf/components/partition_table/gen_esp32part.py -q ./module_config/module_{IDF_TARGET_PATH_NAME}_default/at_customize.csv at_customize.bin

Then, the at_customize.bin will be generated in the ESP-AT root directory.

Thirdly, download the at_customize.bin to flash.

Execute the following command under the root directory of ESP-AT project and replace ``PORT`` and ``BAUD``.

::

    python esp-idf/components/esptool_py/esptool/esptool.py -p PORT -b BAUD --before default_reset --after hard_reset --chip auto write_flash --flash_mode dio --flash_size detect --flash_freq 40m {IDF_TARGET_AT_SECOND_PARTITION_ADDR} ./at_customize.bin

- Replace ``PORT`` with your port name.
- Replace ``BAUD`` with the baud rate.

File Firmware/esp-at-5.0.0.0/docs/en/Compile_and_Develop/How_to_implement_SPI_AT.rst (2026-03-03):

SPI AT Guide
===============

:link_to_translation:`zh_CN:[中文]`

This document mainly introduces the implementation and use of SPI AT, mainly involving the following aspects:

.. contents::
   :local:
   :depth: 1

Overview
--------------

SPI AT is based on ESP-AT project and uses SPI protocol for data communication. When SPI AT is used, MCU works as SPI master and {IDF_TARGET_NAME} AT device works as SPI slave. Both sides of communication exchange data based on AT command through SPI protocol.

Why SPI AT?
^^^^^^^^^^^^^^^^^^^

ESP-AT project uses UART protocol for data communication by default, but UART protocol is not applicable in some application scenarios that need high-speed data transmission. In this case, the SPI protocol which supports a higher transmission rate is a better choice.

How to enable SPI AT?
^^^^^^^^^^^^^^^^^^^^^^^^^

You can configure and enable SPI AT through the following steps:

1. ``./build.py menuconfig`` -> ``Component config`` -> ``AT`` -> ``communicate method for AT command`` -> ``AT through SPI`` to enable SPI AT.
2. ``./build.py menuconfig`` -> ``Component config`` -> ``AT`` -> ``communicate method for AT command`` -> ``AT SPI Data Transmission Mode`` to choose the SPI data transmission mode.
3. ``./build.py menuconfig`` -> ``Component config`` -> ``AT`` -> ``communicate method for AT command`` -> ``AT SPI GPIO settings`` to change the default pin assignments for SPI AT.
4. ``./build.py menuconfig`` -> ``Component config`` -> ``AT`` -> ``communicate method for AT command`` -> ``AT SPI driver settings`` to choose the SPI slave mode, and config the buffer size for data transmission.
5. Recompile the ``esp-at`` project(see :doc:`../Compile_and_Develop/How_to_clone_project_and_compile_it`), download AT bin into flash.

The Default Pin Assignment
^^^^^^^^^^^^^^^^^^^^^^^^^^^^^^

The following pin assignments are used by default:

.. only:: esp32c2 or esp32c3

  .. list-table:: The Default Pins for SPI AT
    :widths: 10 25
    :header-rows: 1

    * - Signal
      - GPIO Number
    * - SCLK
      - 6
    * - MISO
      - 2
    * - MOSI
      - 7
    * - CS
      - 10
    * - HANDSHAKE
      - 3
    * - GND
      - GND
    * - QUADWP (qio/qout) :sup:`1`
      - 8
    * - QUADHD (qio/qout) :sup:`1`
      - 9

.. only:: esp32c6 or esp32c61

  .. list-table:: The Default Pins for SPI AT
    :widths: 10 25
    :header-rows: 1

    * - Signal
      - GPIO Number
    * - SCLK
      - 19
    * - MISO
      - 20
    * - MOSI
      - 18
    * - CS
      - 23
    * - HANDSHAKE
      - 21
    * - GND
      - GND
    * - QUADWP (qio/qout) :sup:`1`
      - 22
    * - QUADHD (qio/qout) :sup:`1`
      - 2

.. only:: esp32c5

  .. list-table:: The Default Pins for SPI AT
    :widths: 10 25
    :header-rows: 1

    * - Signal
      - GPIO Number
    * - SCLK
      - 6
    * - MISO
      - 2
    * - MOSI
      - 7
    * - CS
      - 10
    * - HANDSHAKE
      - 3
    * - GND
      - GND
    * - QUADWP (qio/qout) :sup:`1`
      - 5
    * - QUADHD (qio/qout) :sup:`1`
      - 4

**Note** 1: QUADWP and QUADHD signals are only used for 4-bit (qio/qout) transactions.

You can change the default pin assignments by ``./build.py menuconfig`` > ``Component config`` > ``AT`` > ``communicate method for AT command`` > ``AT through SPI`` > ``AT SPI GPIO settings`` and compile the project (see :doc:`../Compile_and_Develop/How_to_clone_project_and_compile_it`).

How to Use SPI AT?
-----------------------

When SPI AT is used, {IDF_TARGET_NAME} works in SPI half-duplex mode as a slave. 

Handshake Pin
^^^^^^^^^^^^^^^^

Since SPI is a master-slave model, all transmission is initiated by the master, and the slave cannot actively transmit data. However, when AT command is used for data interaction, {IDF_TARGET_NAME} (slave) is required to actively report some information. Therefore, a handshake line is added between SPI master and slave to achieve the purpose.

When the slave needs to transfer data, it pulls up the handshake pin, generating a rising edge GPIO interrupt on the master side. Then, the master initiates communication with the slave. After the data is transferred, the slave pulls down the handshake pin to end this communication.

The specific methods of using the handshake line are as follows:

- When master sends AT commands to slave via SPI, the workflow with an extra handshake line is as follows:

  1. The master sends a request for data transmission to the slave, and then waits for the signal sent by the slave to the handshake line to allow data transmission.
  2. After the master detects the permission signal sent by the slave on the handshake line, it starts to send data.
  3. After sending the data, the master notifies slave that the data transmission is finished.

- When slave sends AT responses to master via SPI, the workflow with an extra handshake line is as follows:

  1. The slave sends a signal through the handshake line to inform the master to start receiving data.
  2. The master receives data and notifies slave that the data transmission is finished after receiving all data.

Communication Formats
^^^^^^^^^^^^^^^^^^^^^^^

The communication format used by SPI AT is CMD+ADDR+DUMMY+DATA (Read or Write). When using SPI AT, some communication messages used by SPI master are described as follows:

- The message used by the master to send data to slave:

.. list-table:: Master write data to slave
   :header-rows: 1
   :widths: 25 25 15 30

   * - CMD (1 byte)
     - ADDR (1 byte)
     - DUMMY (1 byte)
     - DATA (Up to 4092 bytes)
   * - 0x3
     - 0x0
     - 0x0
     - data_buffer

- The message used by the master to inform the slave all data has been sent:

.. list-table:: Master write data done
   :header-rows: 1
   :widths: 25 25 15 30

   * - CMD (1 byte)
     - ADDR (1 byte)
     - DUMMY (1 byte)
     - DATA
   * - 0x7
     - 0x0
     - 0x0
     - null

- The message used by the master to receive data from the slave:

.. list-table:: Master read data from slave
   :header-rows: 1
   :widths: 25 25 15 30

   * - CMD (1 byte)
     - ADDR (1 byte)
     - DUMMY (1 byte)
     - DATA (Up to 4092 bytes)
   * - 0x4
     - 0x0
     - 0x0
     - data_buffer

- The message used by the master to inform the slave all data has been received:

.. list-table:: Master read data done
   :header-rows: 1
   :widths: 25 25 15 30

   * - CMD (1 byte)
     - ADDR (1 byte)
     - DUMMY (1 byte)
     - DATA
   * - 0x8
     - 0x0
     - 0x0
     - null

- The message used by the master to send a request to send data:

.. list-table:: Master request to send data
   :header-rows: 1
   :widths: 25 25 15 30

   * - CMD (1 byte)
     - ADDR (1 byte)
     - DUMMY (1 byte)
     - DATA (4 bytes)
   * - 0x1
     - 0x0
     - 0x0
     - data_info

The 4-byte length ``data_info`` contains the information about the packet to be sent. The specific format is as follows:

1. 0~15 bits: the length of the data that the master want to send to the slave.
2. 16~23 bits: the sequence number of the packet sent by the master to the slave.
3. 24~31 bits: the magic num, and default value is 0xFE.

- After receiving the signal from the handshake line, the master can send the message to query the read or write status of the slave:

.. list-table:: Master query the read/write status of the slave
   :header-rows: 1
   :widths: 25 25 15 30

   * - CMD (1 byte)
     - ADDR (1 byte)
     - DUMMY (1 byte)
     - DATA (4 bytes)
   * - 0x2
     - 0x4
     - 0x0
     - slave_status

After sending the query request, the slave's status returned will be stored in the 4-byte length ``slave_status``, the specific format is as follows:

1. 0~15 bits: the length of the data the slave wants to send to the master. This field is valid only when the slave is readable.
2. 16~23 bits: the sequence number of the packet to be sent. The maximum sequence number is 0xFF, and if the number is reached, the sequence number is incremented by 1 from 0.
3. 24~31 bits: the slave status (readable/writable). 0x1 means readable, and 0x2 means writable.

SPI AT Workflow
^^^^^^^^^^^^^^^^^^^^^^
The workflows mainly includes two aspects:

- When master sends AT commands to slave, the workflow is as follows: 

.. code-block:: none

         | SPI master |                            | SPI slave |
                |                                        |
                |   -------step 1: request to send---->  |
                |                                        |
                |   <------step 2: GPIO interrupt------  |
                |                                        |
                |   -------step 3: read slave status-->  |
                |                                        |
                |   -------step 4: send data---------->  |
                |                                        |
                |   -------step 5: send done---------->  |

The specific description of each step is as follows:

step 1. The master sends a request for data transmission to the slave.
step 2. The slave receives the request from the master. If the master is allowed to send data, the slave sets the status register, and then triggers the GPIO interrupt on the master through the handshake line.
step 3. After receiving the interrupt, master will query the status register of slave. If the query result shows that the slave is in the writable state, the master starts to send data.
step 4. The master send data to the slave.
step 5. After sending the data, the master notifies slave that the data transmission is finished.

- When master receives AT responses from slave, the workflow is as follows: 

.. code-block:: none

         | SPI master |                            | SPI slave |
                |                                        |
                |   <------step 1: GPIO interrupt------  |
                |                                        |
                |   -------step 2: read slave status-->  |
                |                                        |
                |   <------step 3: send data-----------  |
                |                                        |
                |   -------step 4: receive done------->  |

The specific description of each step is as follows:

step 1. The slave sets the status register, and then triggers the GPIO interrupt on the master through the handshake line.
step 2. After receiving the interrupt, master will query the status register of slave. If the query result shows that the slave is in the readable state, the master starts to receive data.
step 3. The master receives the data send by the slave.
step 4. After receiving all data, the master notifies the slave that the data transmission is finished.

**Note** 1. To facilitate understanding, the :example_file:`at_spi_master/spi/esp32_c_series/README.md` provides all the interaction workflow and logic analyzer data involved in the communication by taking sending an AT command as an example.

Sample Code of SPI Master for SPI AT
^^^^^^^^^^^^^^^^^^^^^^^^^^^^^^^^^^^^

SPI AT is used as the SPI slave. For a code example of communication between the SPI master and the SPI slave, please refer to :example:`at_spi_master/spi/esp32_c_series`.

**Note** 1. Before developing with MCU, it is highly recommended to run this example using ESP32-C3 or ESP32 emulated MCU as SPI master to make it easier to debug problems.

SPI AT Throughput
----------------------

Introduction of the Test
^^^^^^^^^^^^^^^^^^^^^^^^^^

- An ESP32 or ESP32-C3 development board is been used as SPI master. The application runs in the board can be found under the directory :example:`at_spi_master/spi/esp32_c_series` of the `ESP-AT <https://github.com/espressif/esp-at>`_ project. Some related configurations are described below: 

1. Hardware configuration: The frequency of CPU is 240 MHz, flash SPI mode is in QIO mode with 40 MHz.

2. Software configuration: The `ESP-IDF <https://docs.espressif.com/projects/esp-idf/en/latest/esp32/get-started/index.html>`_ version is v4.3. The size of streambuffer is 8192 bytes.

- An {IDF_TARGET_NAME}-DevKitC development board is been used as SPI slave. Please refer to :doc:`../Compile_and_Develop/How_to_clone_project_and_compile_it` to build your own ESP-AT project and flash the generated binary files into the board. The board works in the TCP passthrough mode, and some related configurations are described below:

1. Hardware configuration: The frequency of CPU is 160 MHz.

2. Software configuration: The size of streambuffer is 8192 bytes, the sdkconfig is `sdkconfig.defaults.esp32c3 <https://github.com/espressif/esp-idf/blob/master/examples/wifi/iperf/sdkconfig.defaults.esp32c3>`_.

Reference Results
^^^^^^^^^^^^^^^^^^^^

The table below shows the throughput results we got in a shield box.

.. only:: esp32c6 or esp32c3

  .. list-table:: SPI AT Wi-Fi TCP Throughput
    :header-rows: 1
    :widths: 15 20 25 25

    * - Clock
      - SPI mode
      - master->slave
      - slave->master
    * - 10 M
      - Standard
      - 0.95 MByte/s
      - 1.00 MByte/s
    * - 10 M
      - Dual
      - 1.37 MByte/s
      - 1.29 MByte/s
    * - 10 M
      - Quad
      - 1.43 MByte/s
      - 1.31 MByte/s
    * - 20 M
      - Standard
      - 1.41 MByte/s
      - 1.30 MByte/s
    * - 20 M
      - Dual
      - 1.39 MByte/s
      - 1.30 MByte/s
    * - 20 M
      - Quad
      - 1.39 MByte/s
      - 1.30 MByte/s
    * - 40 M
      - Standard
      - 1.37 MByte/s
      - 1.30 MByte/s
    * - 40 M
      - Dual
      - 1.40 MByte/s
      - 1.31 MByte/s
    * - 40 M
      - Quad
      - 1.48 MByte/s
      - 1.31 MByte/s

  **Note** : When SPI clock frequency is high, due to the limitation of upper network components, the communication rate of Dual or Quad mode is not significantly improved compared with Standard mode.

.. only:: esp32c5

  .. list-table:: SPI AT Wi-Fi 5G TCP Throughput
    :header-rows: 1
    :widths: 15 20 25 25

    * - Clock
      - SPI mode
      - master->slave
      - slave->master
    * - 26 M
      - Standard
      - 2.15 MByte/s
      - 2.25 MByte/s
    * - 26 M
      - Dual
      - 2.97 MByte/s
      - 2.59 MByte/s

**Note** : For more information about SPI communication, please refer to the `Technical Reference Manuals <https://www.espressif.com/en/support/documents/technical-documents>`_.

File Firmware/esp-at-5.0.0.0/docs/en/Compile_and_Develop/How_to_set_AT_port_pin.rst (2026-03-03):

How to Set AT Port Pins
==========================

:link_to_translation:`zh_CN:[中文]`

This document introduces how to modify :term:`AT port` pins in the firmware for {IDF_TARGET_NAME} series of products. By default, ESP-AT uses two UART interfaces as AT ports: one is to output logs (named as log port below) and the other to send AT commands and receive responses (named as command port below). 

If you already have the {IDF_TARGET_NAME} AT firmware and only need to modify the command port pins, you can directly modify the firmware using the :doc:`tools_at_py` to generate a new firmware for your module. Otherwise, if you need to modify the AT port pins of your {IDF_TARGET_NAME} device, you need to complete the following steps:

- :doc:`clone the ESP-AT project <How_to_clone_project_and_compile_it>`;
- modify the pins either in the menuconfig utility or the factory_param_data.csv table;
- :doc:`compile the project <How_to_clone_project_and_compile_it>` to generate the new bin in ``build/customized_partitions/factory_param.bin``;
- :ref:`flash the new bin to your device <flash-at-firmware-into-your-device>`.

This document focuses on modifying the pins. Click the links above for details of other steps.

.. note::
  To use other interfaces as the AT command port, please refer to :project_file:`AT through SDIO <main/interface/sdio/README.md>`, :project_file:`AT through SPI <main/interface/spi/README.md>`, or :project_file:`AT through socket <main/interface/socket/README.md>` for more details.

{IDF_TARGET_NAME} Series
------------------------

The log port and command port pins of {IDF_TARGET_NAME} AT firmware can be user-defined to other pins. Refer to `{IDF_TARGET_NAME} Technical Reference Manual <{IDF_TARGET_TRM_EN_URL}>`_ for the pins you can use.

Modify Log Port Pins
^^^^^^^^^^^^^^^^^^^^^^^^^^^^^

By default, the {IDF_TARGET_NAME} AT firmware provided by Espressif uses the following UART0 pins to output log:

.. only:: esp32

  - TX: GPIO1
  - RX: GPIO3

.. only:: esp32c2

  - TX: GPIO20
  - RX: GPIO19

.. only:: esp32c3

  - TX: GPIO21
  - RX: GPIO20

.. only:: esp32c5

  - TX: GPIO11
  - RX: GPIO12

.. only:: esp32c6

  - TX: GPIO16
  - RX: GPIO17

.. only:: esp32c61

  - TX: GPIO11
  - RX: GPIO10

.. only:: esp32s2

  - TX: GPIO43
  - RX: GPIO44

When compiling your ESP-AT project, you can modify them to other pins with the menuconfig utility:

* ``./build.py menuconfig`` --> ``Component config`` --> ``ESP System Settings`` --> ``Channel for console output`` --> ``Custom UART``
* ``./build.py menuconfig`` --> ``Component config`` --> ``ESP System Settings`` --> ``UART TX on GPIO#``
* ``./build.py menuconfig`` --> ``Component config`` --> ``ESP System Settings`` --> ``UART RX on GPIO#``

Modify Command Port Pins
^^^^^^^^^^^^^^^^^^^^^^^^^^^^^^^^^^

By default, UART1 is used to send AT commands and receive AT responses, and its pins are defined in Column ``uart_port``, ``uart_tx_pin``, ``uart_rx_pin``, ``uart_cts_pin``, and ``uart_rts_pin`` of the :component_file:`factory_param_data.csv <customized_partitions/raw_data/factory_param/factory_param_data.csv>`.

You can change them directly in your factory_param_data.csv table:

- Open your local factory_param_data.csv file.
- Locate the row of your module.
- Set ``uart_port`` as needed. (If you want to use the AT log port as the AT command port as well, you need to modify this line, and ensure that the ``uart_tx_pin`` and ``uart_rx_pin`` below have the same pins as the AT log port)
- Set ``uart_tx_pin`` and ``uart_rx_pin`` as needed. (Make sure that the pins you are going to modify are not being used by other functions, including the AT log port)
- Set ``uart_cts_pin`` and ``uart_rts_pin`` to be -1 if you do not use the hardware flow control function.
- Save the table.

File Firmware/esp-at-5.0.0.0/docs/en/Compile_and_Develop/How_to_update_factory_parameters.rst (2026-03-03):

How to Update Factory Parameters
================================

{IDF_TARGET_VER: default="5.4", esp32c5="5.5", esp32c61="5.5"}

:link_to_translation:`zh_CN:[中文]`

This document describes how to update the default factory parameter configuration for ESP-AT. The factory parameter configuration includes some Wi-Fi configurations, UART configurations, and module configurations.

.. contents::
   :local:
   :depth: 1

.. _factory-param-intro:

Factory Parameter Configuration
-------------------------------

The default factory parameters are configured in the source file :component_file:`customized_partitions/raw_data/factory_param/factory_param_data.csv`, as shown below:

   .. list-table::
      :header-rows: 1
      :widths: 40 90 75

      * - Function
        - Current Configuration
        - Related AT Commands
      * - Wi-Fi Configuration
        -
          * max_tx_power (Wi-Fi maximum transmission power for {IDF_TARGET_NAME}, see `{IDF_TARGET_NAME} Transmit Power <https://docs.espressif.com/projects/esp-idf/en/release-v{IDF_TARGET_VER}/{IDF_TARGET_PATH_NAME}/api-reference/network/esp_wifi.html#_CPPv425esp_wifi_set_max_tx_power6int8_t>`_ for the setting range)
          * country_code (country code)
          * start_channel (starting Wi-Fi channel)
          * channel_num (total number of Wi-Fi channels)
        - All AT commands requiring Wi-Fi functionality

      * - UART Configuration
        -
          * uart_port (UART port used for sending AT commands and receiving AT responses)
          * uart_baudrate (UART baud rate)
          * uart_tx_pin (UART TX pin)
          * uart_rx_pin (UART RX pin)
          * uart_cts_pin (UART CTS pin)
          * uart_rts_pin (UART RTS pin)
        - All AT commands requiring UART functionality

      * - Module Name
        - module_name
        - :ref:`AT+GMR <cmd-GMR>`

Please modify the factory parameters configurations according to your own needs and generate ``mfg_nvs.bin`` file.

Generate mfg_nvs.bin
^^^^^^^^^^^^^^^^^^^^^

Please refer to :ref:`mfg-nvs-generate` document to generate the ``mfg_nvs.bin`` file with the factory parameters configurations.

Download mfg_nvs.bin
^^^^^^^^^^^^^^^^^^^^^

Please refer to :ref:`mfg-nvs-download` document.

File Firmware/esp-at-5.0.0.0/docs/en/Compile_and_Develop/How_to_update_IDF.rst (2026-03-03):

How to Update the ESP-IDF Version
=================================

{IDF_TARGET_COMPILE_MNAME: default="undefined", esp32="WROOM-32", esp32c2="ESP32C2-4MB", esp32c3="MINI-1", esp32c5="ESP32C5-4MB", esp32c6="ESP32C6-4MB", esp32c61="ESP32C61-4MB", esp32s2="MINI"}

:link_to_translation:`zh_CN:[中文]`

ESP-AT firmware is based on the Espressif IoT Development Framework (ESP-IDF), and each version of ESP-AT firmware corresponds to a specific ESP-IDF version. It is strongly recommended to use the default ESP-IDF version of the ESP-AT project, and **NOT** recommended to update it, because the inconsistency between the underlying ESP-IDF versions of lib{IDF_TARGET_PATH_NAME}_at_core.a and the ESP-AT project may cause incorrect operation of the firmware.

However, in some special cases, a minor updated ESP-IDF version may be also able to work with the ESP-AT project. In case you should update it, this document can be a reference.

The ESP-IDF version that a specific ESP-AT firmware corresponds to is recorded in the ``IDF_VERSION`` files, which are distributed in different module folders under the :project:`module_config` folder. The file describes the branch, commit ID, and repository URL of the ESP-IDF that a module firmware is based on. For example, the ``IDF_VERSION`` of the ``{IDF_TARGET_COMPILE_MNAME}`` module of ``PLATFORM_{IDF_TARGET_CFG_PREFIX}`` platform is located at :project_file:`module_config/module_{IDF_TARGET_PATH_NAME}_default/IDF_VERSION`.

If you want to update the ESP-IDF version for your ESP-AT firmware, please follow the steps:

- Find the ``IDF_VERSION`` file for your module.
- Update the branch, commit ID, repository as needed.
- Delete the original ``esp-idf`` under the ``esp-at`` root directory, so that the ESP-IDF of the version specified in ``IDF_VERSION`` will be cloned first in the next compilation.
- Recompile the ESP-AT project.

Note that when the ESP-AT version and the ESP-IDF version do not match, the following error will be reported when compiling:

::

    Please wait for the update to complete, which will take some time

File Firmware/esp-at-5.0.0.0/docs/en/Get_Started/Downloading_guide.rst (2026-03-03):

Downloading Guide
=================

{IDF_TARGET_MODULE_NAME: default="undefined", esp32="ESP32-WROOM-32", esp32c2="ESP8684-MINI-1", esp32c3="ESP32-C3-MINI-1", esp32c5="ESP32-C5-WROOM-1", esp32c6="ESP32-C6-MINI-1", esp32c61="ESP32-C61-WROOM-1", esp32s2="ESP32-S2-MINI"}
{IDF_TARGET_FACTORY_BIN: default="undefined", esp32="ESP32-WROOM-32-AT-V3.2.0.0", esp32c2="ESP32C2-4MB-AT-V3.3.0.0", esp32c3="ESP32-C3-MINI-1-AT-V3.3.0.0", esp32c5="ESP32C5-4MB-AT-V5.0.0.0", esp32c6="ESP32C6-4MB-AT-V4.0.0.0", esp32c61="ESP32C61-4MB-AT-V4.0.0.0", esp32s2="ESP32-S2-MINI-AT-V3.4.0.0"}

:link_to_translation:`zh_CN:[中文]`

This Guide demonstrates how to download AT firmware and flash it into an {IDF_TARGET_MODULE_NAME} device by taking {IDF_TARGET_MODULE_NAME} as an example. The Guide is also applicable to other {IDF_TARGET_NAME} modules.

Before you start, please make sure you have already connected your hardware. For more details, see :doc:`Hardware_connection`.

For different series of modules, the commands supported by AT firmware are different. Please refer to :doc:`/Compile_and_Develop/esp-at_firmware_differences` for more details.

.. _download-at-firmware:

Download AT Firmware
---------------------

To download AT firmware to your computer, please do as follows:

- Navigate to :doc:`../AT_Binary_Lists/index`
- Find the firmware for your device
- Click the link to download it

Here, we download ``{IDF_TARGET_FACTORY_BIN}`` for {IDF_TARGET_MODULE_NAME}. The list below describes the structure of this firmware and what each bin file contains. Other AT firmware has similar structure and bin files.

.. code-block:: none

   .
   ├── at_customize.bin                 // secondary partition table
   ├── bootloader                       // bootloader
   │   └── bootloader.bin
   ├── customized_partitions            // AT customized binaries
         ├── mfg_nvs.csv                  // raw data of manufacturing nvs partition
   │   └── mfg_nvs.bin                  // manufacturing nvs partition binary
   ├── download.config                  // configuration of downloading
   ├── esp-at.bin                       // AT application binary
   ├── esp-at.elf
   ├── esp-at.map
   ├── factory                          // A combined bin for factory downloading
   │   └── factory_XXX.bin
   ├── flasher_args.json                // flasher arguments
   ├── ota_data_initial.bin             // ota data parameters
   ├── partition_table                  // primary partition table
   │   └── partition-table.bin
   └── sdkconfig                        // compilation configuration for AT firmware

The file ``download.config`` contains the configuration to flash the firmware into multiple addresses: 

.. only:: esp32

   .. code-block:: none

      --flash_mode dio --flash_freq 40m --flash_size 4MB
      0x1000 bootloader/bootloader.bin
      0x8000 partition_table/partition-table.bin
      0x10000 ota_data_initial.bin
      0x20000 at_customize.bin
      0x21000 customized_partitions/mfg_nvs.bin
      0x100000 esp-at.bin

.. only:: esp32c2

   .. code-block:: none

      --flash_mode dio --flash_freq 60m --flash_size 4MB
      0x0 bootloader/bootloader.bin
      0x8000 partition_table/partition-table.bin
      0xd000 ota_data_initial.bin
      0x1e000 at_customize.bin
      0x1f000 customized_partitions/mfg_nvs.bin
      0x60000 esp-at.bin

.. only:: esp32c3

   .. code-block:: none

      --flash_mode dio --flash_freq 40m --flash_size 4MB
      0x0 bootloader/bootloader.bin
      0x8000 partition_table/partition-table.bin
      0xd000 ota_data_initial.bin
      0x1e000 at_customize.bin
      0x1f000 customized_partitions/mfg_nvs.bin
      0x60000 esp-at.bin

.. only:: esp32c5

   .. code-block:: none

      --flash_mode dio --flash_freq 80m --flash_size 4MB
      0x2000 bootloader/bootloader.bin
      0xc000 partition_table/partition-table.bin
      0xd000 ota_data_initial.bin
      0x30000 at_customize.bin
      0x31000 customized_partitions/mfg_nvs.bin
      0xa0000 esp-at.bin

.. only:: esp32c6

   .. code-block:: none

      --flash_mode dio --flash_freq 80m --flash_size 4MB
      0x0 bootloader/bootloader.bin
      0x8000 partition_table/partition-table.bin
      0xd000 ota_data_initial.bin
      0x1e000 at_customize.bin
      0x1f000 customized_partitions/mfg_nvs.bin
      0x60000 esp-at.bin

.. only:: esp32c61

   .. code-block:: none

      --flash_mode dio --flash_freq 80m --flash_size 4MB
      0x0 bootloader/bootloader.bin
      0xc000 partition_table/partition-table.bin
      0xd000 ota_data_initial.bin
      0x30000 at_customize.bin
      0x31000 customized_partitions/mfg_nvs.bin
      0xa0000 esp-at.bin

.. only:: esp32s2

   .. code-block:: none

      --flash_mode dio --flash_freq 80m --flash_size 4MB
      0x1000 bootloader/bootloader.bin
      0x8000 partition_table/partition-table.bin
      0x10000 ota_data_initial.bin
      0x20000 at_customize.bin
      0x21000 customized_partitions/mfg_nvs.bin
      0x100000 esp-at.bin

.. list::

   - ``--flash_mode dio`` means the firmware is compiled with flash DIO mode.
   :esp32 or esp32c3: - ``--flash_freq 40m`` means the firmware's flash frequency is 40 MHz.
   :esp32c2: - ``--flash_freq 60m`` means the firmware's flash frequency is 60 MHz.
   :esp32c5 or esp32c6 or esp32c61 or esp32s2: - ``--flash_freq 80m`` means the firmware's flash frequency is 80 MHz.
   - ``--flash_size 4MB`` means the firmware is using flash size 4 MB.
   :esp32 or esp32s2: - ``0x10000 ota_data_initial.bin`` means downloading ``ota_data_initial.bin`` into the address ``0x10000``.
   :esp32c2 or esp32c3 or esp32c5 or esp32c6 or esp32c61: - ``0xd000 ota_data_initial.bin`` means downloading ``ota_data_initial.bin`` into the address ``0xd000``.

.. _flash-at-firmware-into-your-device:

Flash AT Firmware into Your Device
-----------------------------------

Follow the instructions below for your operating system.

Windows
^^^^^^^^

Before starting to flash, you need to download `Flash Download Tool <https://dl.espressif.com/public/flash_download_tool.zip>`_ for Windows. You can refer to the `Flash Download Tool User Guide <https://docs.espressif.com/projects/esp-test-tools/en/latest/{IDF_TARGET_PATH_NAME}/production_stage/tools/flash_download_tool.html>`_ for instructions.

- Open the {IDF_TARGET_NAME} Flash Download Tool.
- Select chipType. (Here, we select ``{IDF_TARGET_NAME}``.)
- Select a workMode according to your need. (Here, we select ``Developer Mode``.)
- Select a loadMode according to your need. (Here, we select ``uart``.)

Firmware Download Configurations

   Firmware Download Configurations

- Flash AT firmware into your device. You can select either of the two ways below.

   - To download one combined factory bin (namely, ``factory_XXX.bin`` in the ``build/factory`` directory) to address ``0x0``, select "DoNotChgBin" to use the default configuration of the factory bin.

     Download to One Address

        Download to One Address (click to enlarge)

   - To download multiple bins separately to different addresses, set up the configurations according to the file ``download.config`` and do NOT select "DoNotChgBin".

     Download to Multiple Addresses

        Download to Multiple Addresses (click to enlarge)

In case of flashing issues, please verify what the COM port number of download interface of the {IDF_TARGET_NAME} board is and select it from "COM:" dropdown list. If you do not know the port number, you can refer to `Check port on Windows <https://docs.espressif.com/projects/esp-idf/en/latest/{IDF_TARGET_PATH_NAME}/get-started/establish-serial-connection.html#check-port-on-windows>`_ for details.

When you finish flashing, please `Check Whether AT Works`_.

Linux or macOS
^^^^^^^^^^^^^^^

Before you start to flash, you need to install `esptool.py <https://github.com/espressif/esptool>`_.

You can select either of the two ways below to flash AT firmware into your device.

- To download the bins separately into multiple addresses, enter the following command and replace ``PORTNAME`` and ``download.config``:

  .. code-block:: none

       esptool.py --chip auto --port PORTNAME --baud 115200 --before default_reset --after hard_reset write_flash -z download.config

  Replace ``PORTNAME`` with your port name. If you do not know it, you can refer to `Check port on Linux and macOS <https://docs.espressif.com/projects/esp-idf/en/latest/{IDF_TARGET_PATH_NAME}/get-started/establish-serial-connection.html#check-port-on-linux-and-macos>`_ for details.

  Replace ``download.config`` with the content inside the file.

  Below is the example command for {IDF_TARGET_MODULE_NAME}.

   .. only:: esp32

      .. code-block:: none

         esptool.py --chip auto --port /dev/tty.usbserial-0001 --baud 115200 --before default_reset --after hard_reset write_flash -z --flash_mode dio --flash_freq 40m --flash_size 4MB 0x8000 partition_table/partition-table.bin 0x10000 ota_data_initial.bin 0x1000 bootloader/bootloader.bin 0x100000 esp-at.bin 0x20000 at_customize.bin 0x21000 customized_partitions/mfg_nvs.bin

   .. only:: esp32c2

      .. code-block:: none

         esptool.py --chip auto --port /dev/tty.usbserial-0001 --baud 115200 --before default_reset --after hard_reset write_flash -z --flash_mode dio --flash_freq 60m --flash_size 4MB 0x0 bootloader/bootloader.bin 0x60000 esp-at.bin 0x8000 partition_table/partition-table.bin 0xd000 ota_data_initial.bin 0x1e000 at_customize.bin 0x1f000 customized_partitions/mfg_nvs.bin

   .. only:: esp32c3

      .. code-block:: none

         esptool.py --chip auto --port /dev/tty.usbserial-0001 --baud 115200 --before default_reset --after hard_reset write_flash -z --flash_mode dio --flash_freq 40m --flash_size 4MB 0x8000 partition_table/partition-table.bin 0xd000 ota_data_initial.bin 0x0 bootloader/bootloader.bin 0x60000 esp-at.bin 0x1e000 at_customize.bin 0x1f000 customized_partitions/mfg_nvs.bin

   .. only:: esp32c5

      .. code-block:: none

         esptool.py --chip auto --port /dev/tty.usbserial-0001 --baud 115200 --before default_reset --after hard_reset write_flash -z --flash_mode dio --flash_freq 80m --flash_size 4MB 0xc000 partition_table/partition-table.bin 0xd000 ota_data_initial.bin 0x2000 bootloader/bootloader.bin 0xa0000 esp-at.bin 0x30000 at_customize.bin 0x31000 customized_partitions/mfg_nvs.bin

   .. only:: esp32c6

      .. code-block:: none

         esptool.py --chip auto --port /dev/tty.usbserial-0001 --baud 115200 --before default_reset --after hard_reset write_flash -z --flash_mode dio --flash_freq 80m --flash_size 4MB 0x8000 partition_table/partition-table.bin 0xd000 ota_data_initial.bin 0x0 bootloader/bootloader.bin 0x60000 esp-at.bin 0x1e000 at_customize.bin 0x1f000 customized_partitions/mfg_nvs.bin

   .. only:: esp32c61

      .. code-block:: none

         esptool.py --chip auto --port /dev/tty.usbserial-0001 --baud 115200 --before default_reset --after hard_reset write_flash -z --flash_mode dio --flash_freq 80m --flash_size 4MB 0xc000 partition_table/partition-table.bin 0xd000 ota_data_initial.bin 0x0 bootloader/bootloader.bin 0xa0000 esp-at.bin 0x30000 at_customize.bin 0x31000 customized_partitions/mfg_nvs.bin

   .. only:: esp32s2

      .. code-block:: none

         esptool.py --chip auto --port /dev/tty.usbserial-0001 --baud 115200 --before default_reset --after hard_reset write_flash -z --flash_mode dio --flash_freq 40m --flash_size 4MB 0x0 bootloader/bootloader.bin 0x60000 esp-at.bin 0x8000 partition_table/partition-table.bin 0xd000 ota_data_initial.bin 0x1e000 at_customize.bin 0x1f000 customized_partitions/mfg_nvs.bin

- To download the bins together to one address, enter the following command and replace ``PORTNAME`` and ``FILEDIRECTORY``:

  .. code-block:: none

     esptool.py --chip auto --port PORTNAME --baud 115200 --before default_reset --after hard_reset write_flash -z --flash_mode dio --flash_freq 40m --flash_size 4MB 0x0 FILEDIRECTORY

  Replace ``PORTNAME`` with your port name. If you do not know it, you can refer to `Check port on Linux and macOS <https://docs.espressif.com/projects/esp-idf/en/latest/{IDF_TARGET_PATH_NAME}/get-started/establish-serial-connection.html#check-port-on-linux-and-macos>`_ for details.

  Replace ``FILEDIRECTORY`` with the file directory you would flash to the address ``0x0``. It is normally factory/XXX.bin.

  Below is the example command for {IDF_TARGET_MODULE_NAME}.

   .. only:: esp32

      .. code-block:: none

         esptool.py --chip auto --port /dev/tty.usbserial-0001 --baud 115200 --before default_reset --after hard_reset write_flash -z --flash_mode dio --flash_freq 40m --flash_size 4MB 0x0 factory/factory_WROOM-32.bin

   .. only:: esp32c2

      .. code-block:: none

         esptool.py --chip auto --port /dev/tty.usbserial-0001 --baud 115200 --before default_reset --after hard_reset write_flash -z --flash_mode dio --flash_freq 60m --flash_size 4MB 0x0 factory/factory_ESP32C2-4MB.bin

   .. only:: esp32c3

      .. code-block:: none

         esptool.py --chip auto --port /dev/tty.usbserial-0001 --baud 115200 --before default_reset --after hard_reset write_flash -z --flash_mode dio --flash_freq 40m --flash_size 4MB 0x0 factory/factory_MINI-1.bin

   .. only:: esp32c5

      .. code-block:: none

         esptool.py --chip auto --port /dev/tty.usbserial-0001 --baud 115200 --before default_reset --after hard_reset write_flash -z --flash_mode dio --flash_freq 80m --flash_size 4MB 0x0 factory/factory_ESP32C5-4MB.bin

   .. only:: esp32c6

      .. code-block:: none

         esptool.py --chip auto --port /dev/tty.usbserial-0001 --baud 115200 --before default_reset --after hard_reset write_flash -z --flash_mode dio --flash_freq 80m --flash_size 4MB 0x0 factory/factory_ESP32C6-4MB.bin

   .. only:: esp32c61

      .. code-block:: none

         esptool.py --chip auto --port /dev/tty.usbserial-0001 --baud 115200 --before default_reset --after hard_reset write_flash -z --flash_mode dio --flash_freq 80m --flash_size 4MB 0x0 factory/factory_ESP32C61-4MB.bin

   .. only:: esp32s2

      .. code-block:: none

         esptool.py --chip auto --port /dev/tty.usbserial-0001 --baud 115200 --before default_reset --after hard_reset write_flash -z --flash_mode dio --flash_freq 80m --flash_size 4MB 0x0 factory/factory_MINI-1.bin

When you finish flashing, please `Check Whether AT Works`_.

.. _check-whether-at-works:

Check Whether AT Works
-----------------------

To check whether AT works, do as follows:

- Open a serial port tool, such as SecureCRT;
- Select the Port attached to "AT command/response" line (see :doc:`Hardware_connection` for details);
- Set Baudrate to 115200;
- Set Data Bits to 8;
- Set Parity to None;
- Set Stop Bits to 1;
- Set Flow Type to None;
- Enter the command "AT+GMR" with a new line (CR LF). 

If the response is OK as shown below, AT works.

.. only:: esp32c2

   .. code-block:: none

      AT+GMR
      AT version:3.3.0.0(3b13d04 - ESP32C2 - May  8 2024 08:21:45)
      SDK version:v5.0.6-dirty
      compile time(be332568):May  8 2024 08:50:59
      Bin version:v3.3.0.0(ESP32C2-4MB)

      OK

.. only:: esp32c3

   .. code-block:: none

      AT+GMR
      AT version:3.3.0.0(3b13d04 - ESP32C3 - May  8 2024 08:21:54)
      SDK version:v5.0.6-dirty
      compile time(be332568):May  8 2024 08:51:33
      Bin version:v3.3.0.0(MINI-1)

      OK

.. only:: esp32c5

   .. code-block:: none

      AT+GMR
      AT version:5.0.0.0(b0fe7e5 - ESP32C5 - Aug 22 2025 09:44:01)
      SDK version:v5.5-beta1-695-ga3ca8669f24
      compile time(7917c1fb):Aug 25 2025 15:10:23
      Bin version:v5.0.0.0(ESP32C5-4MB)

      OK

.. only:: esp32c6

   .. code-block:: none

      AT+GMR
      AT version:4.0.0.0(3fe3806 - ESP32C6 - Dec 29 2023 11:10:21)
      SDK version:v5.1.2-dirty
      compile time(89040be7):Jan  2 2024 05:53:07
      Bin version:v4.0.0.0(ESP32C6-4MB)

      OK

.. only:: esp32c61

   .. code-block:: none

      AT+GMR
      AT version:5.0.0.0(f6b0e89 - ESP32C61 - Oct 17 2025 08:55:06)
      SDK version:v5.5.1-255-g07e9bf4970
      compile time(65202f43):Oct 17 2025 19:46:13
      Bin version:v5.0.0.0(ESP32C61-4MB)

      OK

.. only:: esp32

   .. code-block:: none

      AT+GMR
      AT version:3.2.0.0(s-ec2dec2 - ESP32 - Jul 28 2023 07:05:28)
      SDK version:v5.0.2-376-g24b9d38a24-dirty
      compile time(6118fc22):Jul 28 2023 09:47:28
      Bin version:v3.2.0.0(WROOM-32)

      OK

.. only:: esp32s2

   .. code-block:: none

      AT+GMR
      AT version:3.4.0.0-dev(ca45add - ESP32S2 - May  9 2024 08:00:07)
      SDK version:v5.0.6-dirty
      compile time(877c7e69):May 10 2024 06:47:54
      Bin version:v3.4.0.0-dev(MINI)

      OK

Otherwise, you need to check your {IDF_TARGET_NAME} startup log in one of the following ways:

**Method 1:**

- Open a serial port tool, such as SecureCRT;
- Select the port attached to the "Download/Log output" line. For more information on this line, see :doc:`Hardware_connection`.
- Set Baudrate to 115200;
- Set Data Bits to 8;
- Set Parity to None;
- Set Stop Bits to 1;
- Set Flow Type to None;
- Press the RST key of the board directly. If it is like the log below, it means that ESP-AT firmware have been initialized correctly.

**Method 2:**

- Open two serial port tools, such as SecureCRT;
- In one serial port tool, select the port attached to the "AT command/response" line. In the other tool, select the port attached to the "Download/Log output" line. For more information on these lines, see :doc:`Hardware_connection`.
- Set Baudrate to 115200;
- Set Data Bits to 8;
- Set Parity to None;
- Set Stop Bits to 1;
- Set Flow Type to None;
- Enter the command :ref:`AT+RST <cmd-RST>` with a new line (CR LF) to the "AT command/response" line. If the serial log from the "Download/Output log" line is like the log below, it means that ESP-AT firmware have been initialized correctly.

.. only:: esp32

   {IDF_TARGET_NAME} startup log:

   .. code-block:: none

      rst:0x1 (POWERON_RESET),boot:0x13 (SPI_FAST_FLASH_BOOT)
      configsip: 0, SPIWP:0xee
      clk_drv:0x00,q_drv:0x00,d_drv:0x00,cs0_drv:0x00,hd_drv:0x00,wp_drv:0x00
      mode:DIO, clock div:2
      load:0x3fff0030,len:5884
      ho 0 tail 12 room 4
      load:0x40078000,len:15844
      load:0x40080400,len:3560
      entry 0x40080604
      I (29) boot: ESP-IDF v5.0-541-g885e501d99-dirty 2nd stage bootloader
      I (29) boot: compile time 08:40:13
      I (29) boot: chip revision: v1.0
      I (34) boot.esp32: SPI Speed      : 40MHz
      I (38) boot.esp32: SPI Mode       : DIO
      I (43) boot.esp32: SPI Flash Size : 4MB
      I (47) boot: Enabling RNG early entropy source...
      I (53) boot: Partition Table:
      I (56) boot: ## Label            Usage          Type ST Offset   Length
      I (64) boot:  0 phy_init         RF data          01 01 0000f000 00001000
      I (71) boot:  1 otadata          OTA data         01 00 00010000 00002000
      I (78) boot:  2 nvs              WiFi data        01 02 00012000 0000e000
      I (86) boot:  3 at_customize     unknown          40 00 00020000 000e0000
      I (93) boot:  4 ota_0            OTA app          00 10 00100000 00180000
      I (101) boot:  5 ota_1            OTA app          00 11 00280000 00180000
      I (108) boot: End of partition table
      I (113) esp_image: segment 0: paddr=00100020 vaddr=3f400020 size=1a854h (108628) map
      I (161) esp_image: segment 1: paddr=0011a87c vaddr=3ff80063 size=00008h (     8) load
      I (161) esp_image: segment 2: paddr=0011a88c vaddr=3ffbdb60 size=04d5ch ( 19804) load
      I (174) esp_image: segment 3: paddr=0011f5f0 vaddr=40080000 size=00a28h (  2600) load
      I (176) esp_image: segment 4: paddr=00120020 vaddr=400d0020 size=11f5c0h (1177024) map
      I (609) esp_image: segment 5: paddr=0023f5e8 vaddr=40080a28 size=1e948h (125256) load
      I (660) esp_image: segment 6: paddr=0025df38 vaddr=400c0000 size=00064h (   100) load
      I (676) boot: Loaded app from partition at offset 0x100000
      I (676) boot: Disabling RNG early entropy source...
      no external 32k oscillator, disable it now.
      at param mode: 1
      AT cmd port:uart1 tx:17 rx:16 cts:15 rts:14 baudrate:115200
      module_name: WROOM-32
      max tx power=78, ret=0
      2.5.0

.. only:: esp32c2

   {IDF_TARGET_NAME} startup log:

   .. code-block:: none

      ESP-ROM:esp8684-api2-20220127
      Build:Jan 27 2022
      rst:0x1 (POWERON),boot:0xc (SPI_FAST_FLASH_BOOT)
      SPIWP:0xee
      mode:DIO, clock div:1
      load:0x3fcd6108,len:0x18b0
      load:0x403ae000,len:0x854
      load:0x403b0000,len:0x2724
      entry 0x403ae000
      I (32) boot: ESP-IDF v5.0-dev-5949-g885e501d99-dirty 2nd stage bootloader
      I (32) boot: compile time 11:05:11
      I (32) boot: chip revision: v1.0
      I (36) boot.esp32c2: MMU Page Size  : 64K
      I (41) boot.esp32c2: SPI Speed      : 60MHz
      I (46) boot.esp32c2: SPI Mode       : DIO
      I (50) boot.esp32c2: SPI Flash Size : 4MB
      I (55) boot: Enabling RNG early entropy source...
      I (61) boot: Partition Table:
      I (64) boot: ## Label            Usage          Type ST Offset   Length
      I (71) boot:  0 otadata          OTA data         01 00 0000d000 00002000
      I (79) boot:  1 phy_init         RF data          01 01 0000f000 00001000
      I (86) boot:  2 nvs              WiFi data        01 02 00010000 0000e000
      I (94) boot:  3 at_customize     unknown          40 00 0001e000 00042000
      I (101) boot:  4 ota_0            OTA app          00 10 00060000 001d0000
      I (109) boot:  5 ota_1            OTA app          00 11 00230000 001d0000
      I (116) boot: End of partition table
      I (121) esp_image: segment 0: paddr=00060020 vaddr=3c0e0020 size=288c8h (166088) map
      I (167) esp_image: segment 1: paddr=000888f0 vaddr=3fca6010 size=02c18h ( 11288) load
      I (170) esp_image: segment 2: paddr=0008b510 vaddr=40380000 size=04b08h ( 19208) load
      I (178) esp_image: segment 3: paddr=00090020 vaddr=42000020 size=d444ch (869452) map
      I (378) esp_image: segment 4: paddr=00164474 vaddr=40384b08 size=01508h (  5384) load
      I (382) boot: Loaded app from partition at offset 0x60000
      I (383) boot: Disabling RNG early entropy source...
      at param mode: 1
      AT cmd port:uart1 tx:7 rx:6 cts:5 rts:4 baudrate:115200
      module_name: ESP32C2-4MB
      max tx power=78, ret=0
      3.0.0

.. only:: esp32c3

   {IDF_TARGET_NAME} startup log:

   .. code-block:: none

      ESP-ROM:esp32c3-api1-20210207
      Build:Feb  7 2021
      rst:0x1 (POWERON),boot:0xc (SPI_FAST_FLASH_BOOT)
      SPIWP:0xee
      mode:DIO, clock div:2
      load:0x3fcd5820,len:0x16b4
      load:0x403cc710,len:0x970
      load:0x403ce710,len:0x2e90
      entry 0x403cc710
      I (31) boot: ESP-IDF v5.0-541-g885e501d99-dirty 2nd stage bootloader
      I (31) boot: compile time 14:34:08
      I (32) boot: chip revision: v0.3
      I (35) boot.esp32c3: SPI Speed      : 40MHz
      I (40) boot.esp32c3: SPI Mode       : DIO
      I (45) boot.esp32c3: SPI Flash Size : 4MB
      I (49) boot: Enabling RNG early entropy source...
      I (55) boot: Partition Table:
      I (58) boot: ## Label            Usage          Type ST Offset   Length
      I (66) boot:  0 otadata          OTA data         01 00 0000d000 00002000
      I (73) boot:  1 phy_init         RF data          01 01 0000f000 00001000
      I (81) boot:  2 nvs              WiFi data        01 02 00010000 0000e000
      I (88) boot:  3 at_customize     unknown          40 00 0001e000 00042000
      I (95) boot:  4 ota_0            OTA app          00 10 00060000 001d0000
      I (103) boot:  5 ota_1            OTA app          00 11 00230000 001d0000
      I (110) boot: End of partition table
      I (115) esp_image: segment 0: paddr=00060020 vaddr=3c170020 size=3bd30h (245040) map
      I (175) esp_image: segment 1: paddr=0009bd58 vaddr=3fc95400 size=03884h ( 14468) load
      I (178) esp_image: segment 2: paddr=0009f5e4 vaddr=40380000 size=00a34h (  2612) load
      I (181) esp_image: segment 3: paddr=000a0020 vaddr=42000020 size=167a10h (1473040) map
      I (497) esp_image: segment 4: paddr=00207a38 vaddr=40380a34 size=1486ch ( 84076) load
      I (518) esp_image: segment 5: paddr=0021c2ac vaddr=50000000 size=00018h (    24) load
      I (525) boot: Loaded app from partition at offset 0x60000
      I (525) boot: Disabling RNG early entropy source...
      no external 32k oscillator, disable it now.
      at param mode: 1
      AT cmd port:uart1 tx:7 rx:6 cts:5 rts:4 baudrate:115200
      module_name: MINI-1
      max tx power=78, ret=0
      2.5.0

.. only:: esp32c5

   {IDF_TARGET_NAME} startup log:

   .. code-block:: none

      ESP-ROM:esp32c5-eco2-20250121
      Build:Jan 21 2025
      rst:0x1 (POWERON),boot:0x58 (SPI_FAST_FLASH_BOOT)
      SPI mode:DIO, clock div:1
      load:0x408556b0,len:0x1710
      load:0x4084bba0,len:0xd7c
      load:0x4084e5a0,len:0x31bc
      entry 0x4084bbaa
      I (23) boot: ESP-IDF v5.5-beta1-695-ga3ca8669f24-dir 2nd stage bootloader
      I (24) boot: compile time Aug 25 2025 15:10:14
      I (24) boot: chip revision: v1.0
      I (26) boot: efuse block revision: v0.2
      I (29) boot.esp32c5: SPI Speed      : 80MHz
      I (33) boot.esp32c5: SPI Mode       : DIO
      I (37) boot.esp32c5: SPI Flash Size : 4MB
      I (41) boot: Enabling RNG early entropy source...
      I (45) boot: Partition Table:
      I (48) boot: ## Label            Usage          Type ST Offset   Length
      I (54) boot:  0 otadata          OTA data         01 00 0000d000 00002000
      I (60) boot:  1 phy_init         RF data          01 01 0000f000 00001000
      I (67) boot:  2 nvs              WiFi data        01 02 00010000 0000e000
      I (73) boot:  3 at_customize     unknown          40 00 0001e000 00042000
      I (80) boot:  4 ota_0            OTA app          00 10 00060000 001d0000
      I (86) boot:  5 ota_1            OTA app          00 11 00230000 001d0000
      I (93) boot: End of partition table
      I (97) esp_image: segment 0: paddr=00060020 vaddr=42170020 size=2c954h (182612) map
      I (136) esp_image: segment 1: paddr=0008c97c vaddr=40800000 size=0369ch ( 13980) load
      I (139) esp_image: segment 2: paddr=00090020 vaddr=42000020 size=16d640h (1496640) map
      I (396) esp_image: segment 3: paddr=001fd668 vaddr=4080369c size=196d0h (104144) load
      I (417) esp_image: segment 4: paddr=00216d40 vaddr=4081cd80 size=04998h ( 18840) load
      I (421) esp_image: segment 5: paddr=0021b6e0 vaddr=50000000 size=000a4h (   164) load
      I (428) boot: Loaded app from partition at offset 0x60000
      I (429) boot: Disabling RNG early entropy source...
      I (927) at-init: at param mode: 1
      I (1554) at-uart: AT cmd port:uart1 tx:23 rx:24 cts:25 rts:26 baudrate:115200
      I (1555) at-init: module_name: ESP32C5-4MB
      I (1557) at-init: max tx power=78, ret=0
      I (1560) at-init: v5.0.0.0 (gitlab)
      I (2752) at-wifi: negotiated phy mode: 4

.. only:: esp32c6

   {IDF_TARGET_NAME} startup log:

   .. code-block:: none

      ESP-ROM:esp32c6-20220919
      Build:Sep 19 2022
      rst:0xc (SW_CPU),boot:0x6c (SPI_FAST_FLASH_BOOT)
      Saved PC:0x4001975a
      SPIWP:0xee
      mode:DIO, clock div:2
      load:0x4086c410,len:0xd50
      load:0x4086e610,len:0x2d74
      load:0x40875720,len:0x1800
      entry 0x4086c410
      I (27) boot: ESP-IDF v5.0-dev-9643-g4bc762621d-dirty 2nd stage bootloader
      I (27) boot: compile time Jul  5 2023 11:12:16
      I (29) boot: chip revision: v0.1
      I (32) boot.esp32c6: SPI Speed      : 40MHz
      I (37) boot.esp32c6: SPI Mode       : DIO
      I (41) boot.esp32c6: SPI Flash Size : 4MB
      I (46) boot: Enabling RNG early entropy source...
      I (52) boot: Partition Table:
      I (55) boot: ## Label            Usage          Type ST Offset   Length
      I (62) boot:  0 otadata          OTA data         01 00 0000d000 00002000
      I (70) boot:  1 phy_init         RF data          01 01 0000f000 00001000
      I (77) boot:  2 nvs              WiFi data        01 02 00010000 0000e000
      I (85) boot:  3 at_customize     unknown          40 00 0001e000 00042000
      I (92) boot:  4 ota_0            OTA app          00 10 00060000 001d0000
      I (100) boot:  5 ota_1            OTA app          00 11 00230000 001d0000
      I (107) boot: End of partition table
      I (112) esp_image: segment 0: paddr=00060020 vaddr=42140020 size=30628h (198184) map
      I (198) esp_image: segment 1: paddr=00090650 vaddr=40800000 size=0f9c8h ( 63944) load
      I (228) esp_image: segment 2: paddr=000a0020 vaddr=42000020 size=13c688h (1296008) map
      I (740) esp_image: segment 3: paddr=001dc6b0 vaddr=4080f9c8 size=05bf4h ( 23540) load
      I (752) esp_image: segment 4: paddr=001e22ac vaddr=408155c0 size=03c54h ( 15444) load
      I (760) esp_image: segment 5: paddr=001e5f08 vaddr=50000000 size=00068h (   104) load
      I (771) boot: Loaded app from partition at offset 0x60000
      I (772) boot: Disabling RNG early entropy source...
      no external 32k oscillator, disable it now.
      at param mode: 1
      AT cmd port:uart1 tx:7 rx:6 cts:5 rts:4 baudrate:115200
      module_name: ESP32C6-4MB
      max tx power=78, ret=0
      4.0.0

.. only:: esp32c61

   {IDF_TARGET_NAME} startup log:

   .. code-block:: none

      ESP-ROM:esp32c61-eco3-20250228
      Build:Feb 28 2025
      rst:0xc (SW_CPU),boot:0xc (SPI_FAST_FLASH_BOOT)
      Core0 Saved PC:0x4080a438
      SPI mode:DIO, clock div:1
      load:0x40845c00,len:0x1b80
      load:0x4083bd70,len:0xce4
      load:0x4083ea70,len:0x3248
      load:0x4084a000,len:0x222c
      entry 0x4083bd7a
      I (29) boot: ESP-IDF v5.5.1-255-g07e9bf4970-dirty 2nd stage bootloader
      I (30) boot: compile time Oct 17 2025 19:46:05
      I (32) boot: chip revision: v1.0
      I (32) boot: efuse block revision: v0.1
      I (35) boot.esp32c61: SPI Speed      : 80MHz
      I (39) boot.esp32c61: SPI Mode       : DIO
      I (43) boot.esp32c61: SPI Flash Size : 4MB
      I (47) boot: Enabling RNG early entropy source...
      I (51) boot: Partition Table:
      I (54) boot: ## Label            Usage          Type ST Offset   Length
      I (60) boot:  0 otadata          OTA data         01 00 0000d000 00002000
      I (67) boot:  1 phy_init         RF data          01 01 0000f000 00001000
      I (73) boot:  2 nvs              WiFi data        01 02 00010000 00020000
      I (80) boot:  3 at_customize     unknown          40 00 00030000 00070000
      I (86) boot:  4 ota_0            OTA app          00 10 000a0000 00220000
      I (93) boot:  5 ota_1            OTA app          00 11 002c0000 00140000
      I (100) boot: End of partition table
      I (103) esp_image: segment 0: paddr=000a0020 vaddr=42170020 size=2d18ch (184716) map
      I (157) esp_image: segment 1: paddr=000cd1b4 vaddr=40800000 size=02e64h ( 11876) load
      I (162) esp_image: segment 2: paddr=000d0020 vaddr=42000020 size=16ccb8h (1494200) map
      I (533) esp_image: segment 3: paddr=0023cce0 vaddr=40802e64 size=0ff78h ( 65400) load
      I (555) esp_image: segment 4: paddr=0024cc60 vaddr=40812e00 size=0416ch ( 16748) load
      I (570) boot: Loaded app from partition at offset 0xa0000
      I (571) boot: Disabling RNG early entropy source...
      I (1087) at-init: at param mode: 1
      I (1177) at-uart: AT cmd port:uart1 tx:6 rx:5 cts:4 rts:3 baudrate:115200
      I (1178) at-init: module_name: ESP32C61-4MB
      I (1179) at-init: max tx power=78, ret=0
      I (1181) at-init: v5.0.0.0 (gitlab)

.. only:: esp32s2

   {IDF_TARGET_NAME} startup log:

   .. code-block:: none

      ESP-ROM:esp32s2-rc4-20191025
      Build:Oct 25 2019
      rst:0x1 (POWERON),boot:0x8 (SPI_FAST_FLASH_BOOT)
      SPIWP:0xee
      mode:DIO, clock div:1
      load:0x3ffe6108,len:0x17d4
      load:0x4004c000,len:0xa9c
      load:0x40050000,len:0x3204
      entry 0x4004c1b8
      I (21) boot: ESP-IDF v5.0.6-dirty 2nd stage bootloader
      I (21) boot: compile time 06:47:54
      I (21) boot: chip revision: v0.0
      I (24) boot.esp32s2: SPI Speed      : 80MHz
      I (29) boot.esp32s2: SPI Mode       : DIO
      I (34) boot.esp32s2: SPI Flash Size : 4MB
      I (39) boot: Enabling RNG early entropy source...
      I (44) boot: Partition Table:
      I (48) boot: ## Label            Usage          Type ST Offset   Length
      I (55) boot:  0 phy_init         RF data          01 01 0000f000 00001000
      I (62) boot:  1 otadata          OTA data         01 00 00010000 00002000
      I (70) boot:  2 nvs              WiFi data        01 02 00012000 0000e000
      I (77) boot:  3 at_customize     unknown          40 00 00020000 000e0000
      I (85) boot:  4 ota_0            OTA app          00 10 00100000 00180000
      I (92) boot:  5 ota_1            OTA app          00 11 00280000 00180000
      I (100) boot: End of partition table
      I (104) esp_image: segment 0: paddr=00100020 vaddr=3f000020 size=28958h (166232) map
      I (146) esp_image: segment 1: paddr=00128980 vaddr=3ff9e02c size=00004h (     4) load
      I (146) esp_image: segment 2: paddr=0012898c vaddr=3ffc2f70 size=036f4h ( 14068) load
      I (155) esp_image: segment 3: paddr=0012c088 vaddr=40022000 size=03f90h ( 16272) load
      I (164) esp_image: segment 4: paddr=00130020 vaddr=40080020 size=d2214h (860692) map
      I (340) esp_image: segment 5: paddr=0020223c vaddr=40025f90 size=0cfdch ( 53212) load
      I (354) esp_image: segment 6: paddr=0020f220 vaddr=40070000 size=0002ch (    44) load
      I (363) boot: Loaded app from partition at offset 0x100000
      I (363) boot: Disabling RNG early entropy source...
      at param mode: 1
      AT cmd port:uart1 tx:17 rx:21 cts:20 rts:19 baudrate:115200
      module_name: MINI
      max tx power=78, ret=0
      v3.4.0.0-dev

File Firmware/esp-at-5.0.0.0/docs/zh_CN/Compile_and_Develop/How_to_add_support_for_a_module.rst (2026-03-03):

如何增加一个新的模组支持
============================

:link_to_translation:`en:[English]`

ESP-AT 工程支持多个模组，并提供了模组的配置文件：:component_file:`factory_param_data.csv <customized_partitions/raw_data/factory_param/factory_param_data.csv>` 和 :project:`module_config`。如果要在 ESP-AT 工程中添加对某个 {IDF_TARGET_NAME} 模组的支持，则需要修改这些配置文件。此处的”{IDF_TARGET_NAME} 模组“指的是：

- ESP-AT 工程暂未适配支持的模组，包括 ESP-AT 已适配相应芯片的模组，和未适配相应芯片的模组。但不建议添加后者，因为工作量巨大，此文档也不做阐述。

- ESP-AT 工程已适配支持的模组，但用户需要对其修改默认配置的。

.. only:: esp32c2 or esp32c3 or esp32c5 or esp32c6 or esp32c61

  本文档将说明如何在 ESP-AT 工程中为 ESP-AT 已支持的某款 {IDF_TARGET_NAME} 芯片添加新的模组支持，下文中以添加对 {IDF_TARGET_NAME}-MINI-1 支持为例，该模组使用 SPI 而不是默认的 UART 接口。

.. only:: esp32 or esp32s2

  本文档将说明如何在 ESP-AT 工程中为 ESP-AT 已支持的某款 {IDF_TARGET_NAME} 芯片/模组添加新的模组支持。下文将增加默认启用 :ref:`文件系统 AT 命令集 <FS-AT>` 的配置为例，来添加新的模组支持。

.. contents::
   :local:
   :depth: 1

第一步：配置新增模组的出厂参数
------------------------------------------------

打开本地的 :component_file:`factory_param_data.csv <customized_partitions/raw_data/factory_param/factory_param_data.csv>`，在表格最后插入一行，根据实际需要设置相关参数。本例中，我们将 ``platform`` 设置为 ``PLATFORM_{IDF_TARGET_CFG_PREFIX}``、``module_name`` 设置为 ``{IDF_TARGET_CFG_PREFIX}-USER-DEFINED``，其他参数设置值见下表（参数含义请参考 :ref:`factory-param-intro`）。

- platform: PLATFORM_{IDF_TARGET_CFG_PREFIX}
- module_name: {IDF_TARGET_CFG_PREFIX}-USER-DEFINED
- description:
- version: 4
- max_tx_power: 78
- uart_port: 1
- start_channel: 1
- channel_num: 13
- country_code: CN
- uart_baudrate: -1
- uart_tx_pin: -1
- uart_rx_pin: -1
- uart_cts_pin: -1
- uart_rts_pin: -1

第二步：配置新增模组的 OTA
-----------------------------------

在 :component_file:`at/src/at_default_config.c` 中的 ``s_module_info`` 结构体中添加自定义模组的信息。 

``s_module_info`` 结构体提供 ``OTA`` 升级验证 ``token``：

.. code-block:: c

    typedef struct {
        char* module_name;
        char* ota_token;
        char* ota_ssl_token;
    } at_module_info_t;

若不想使用 ``OTA`` 功能，那么第二个参数 ``ota_token`` 和第三个参数 ``ota_ssl_token`` 应该设置为 ``NULL``，第一个参数 ``module_name`` 必须与 factory_param_data.csv 文件中的 ``module_name`` 一致。

下面是修改后的 ``s_module_info`` 结构体。

.. code-block:: c

    static const at_module_info_t s_module_info[] = {
    #if defined(CONFIG_IDF_TARGET_ESP32)
      ...
    #endif

    #if defined(CONFIG_IDF_TARGET_ESP32C3)
      ...
    #endif

    #if defined(CONFIG_IDF_TARGET_ESP32C2)
      ...
    #endif

    #if defined(CONFIG_IDF_TARGET_ESP32C5)
      ...
    #endif

    #if defined(CONFIG_IDF_TARGET_ESP32C6)
      ...
    #endif

    #if defined(CONFIG_IDF_TARGET_{IDF_TARGET_CFG_PREFIX})
      {"MY_MODULE",       CONFIG_ESP_AT_OTA_TOKEN_MY_MODULE,      CONFIG_ESP_AT_OTA_SSL_TOKEN_MY_MODULE },     // MY_MODULE
    #endif
    };

宏 ``CONFIG_ESP_AT_OTA_TOKEN_MY_MODULE`` 和宏 ``CONFIG_ESP_AT_OTA_SSL_TOKEN_MY_MODULE`` 定义在头文件 :component_file:`at/private_include/at_ota_token.h` 中。

.. code-block:: none

    #if defined(CONFIG_IDF_TARGET_{IDF_TARGET_CFG_PREFIX})
    ...
    #define CONFIG_ESP_AT_OTA_TOKEN_MY_MODULE       CONFIG_ESP_AT_OTA_TOKEN_DEFAULT

    ...
    #define CONFIG_ESP_AT_OTA_SSL_TOKEN_MY_MODULE       CONFIG_ESP_AT_OTA_SSL_TOKEN_DEFAULT

第三步：新增模组配置
---------------------------

下表列出了 ESP-AT 工程支持的平台（即芯片系列）名称、模组配置名称以及各个模组配置对应的配置文件的位置。

.. list-table::
   :header-rows: 1
   :widths: 5 10 40

   * - 平台
     - 模组配置名称
     - 对应的默认配置文件
   * - ESP32
     - WROOM-32
     - - :project_file:`module_config/module_esp32_default/sdkconfig.defaults`
       - :project_file:`module_config/module_esp32_default/sdkconfig_silence.defaults`
   * - ESP32
     - PICO-D4
     - - :project_file:`module_config/module_esp32_default/sdkconfig.defaults`
       - :project_file:`module_config/module_esp32_default/sdkconfig_silence.defaults`
   * - ESP32
     - SOLO-1
     - - :project_file:`module_config/module_esp32_default/sdkconfig.defaults`
       - :project_file:`module_config/module_esp32_default/sdkconfig_silence.defaults`
   * - ESP32
     - MINI-1
     - - :project_file:`module_config/module_esp32_default/sdkconfig.defaults`
       - :project_file:`module_config/module_esp32_default/sdkconfig_silence.defaults`
   * - ESP32
     - WROVER-32
     - - :project_file:`module_config/module_wrover-32/sdkconfig.defaults`
       - :project_file:`module_config/module_wrover-32/sdkconfig_silence.defaults`
   * - ESP32
     - ESP32-D2WD
     - - :project_file:`module_config/module_esp32-d2wd/sdkconfig.defaults`
       - :project_file:`module_config/module_esp32-d2wd/sdkconfig_silence.defaults`
   * - ESP32
     - ESP32-SDIO
     - - :project_file:`module_config/module_esp32-sdio/sdkconfig.defaults`
       - :project_file:`module_config/module_esp32-sdio/sdkconfig_silence.defaults`
   * - ESP32-C2
     - ESP32C2-2MB
     - - :project_file:`module_config/module_esp32c2-2mb/sdkconfig.defaults`
       - :project_file:`module_config/module_esp32c2-2mb/sdkconfig_silence.defaults`
   * - ESP32-C2
     - ESP32C2-2MB-BLE
     - - :project_file:`module_config/module_esp32c2-2mb-ble/sdkconfig.defaults`
       - :project_file:`module_config/module_esp32c2-2mb-ble/sdkconfig_silence.defaults`
   * - ESP32-C2
     - ESP32C2-4MB
     - - :project_file:`module_config/module_esp32c2_default/sdkconfig.defaults`
       - :project_file:`module_config/module_esp32c2_default/sdkconfig_silence.defaults`
   * - ESP32-C3
     - MINI-1
     - - :project_file:`module_config/module_esp32c3_default/sdkconfig.defaults`
       - :project_file:`module_config/module_esp32c3_default/sdkconfig_silence.defaults`
   * - ESP32-C3
     - ESP32C3-SPI
     - - :project_file:`module_config/module_esp32c3-spi/sdkconfig.defaults`
       - :project_file:`module_config/module_esp32c3-spi/sdkconfig_silence.defaults`
   * - ESP32-C3
     - ESP32C3_RAINMAKER
     - - :project_file:`module_config/module_esp32c3_rainmaker/sdkconfig.defaults`
       - :project_file:`module_config/module_esp32c3_rainmaker/sdkconfig_silence.defaults`
   * - ESP32-C5
     - ESP32C5-4MB
     - - :project_file:`module_config/module_esp32c5_default/sdkconfig.defaults`
       - :project_file:`module_config/module_esp32c5_default/sdkconfig_silence.defaults`
   * - ESP32-C6
     - ESP32C6-4MB
     - - :project_file:`module_config/module_esp32c6_default/sdkconfig.defaults`
       - :project_file:`module_config/module_esp32c6_default/sdkconfig_silence.defaults`
   * - ESP32-C61
     - ESP32C61-4MB
     - - :project_file:`module_config/module_esp32c61_default/sdkconfig.defaults`
       - :project_file:`module_config/module_esp32c61_default/sdkconfig_silence.defaults`

.. 注意::

  - 当 :ref:`python build.py install <esp-at-install-env>` 中的 ``silence mode`` 为 ``0`` 时，模组配置对应的配置文件为 ``sdkconfig.defaults``。
  - 当 :ref:`python build.py install <esp-at-install-env>` 中的 ``silence mode`` 为 ``1`` 时，模组配置对应的配置文件为 ``sdkconfig_silence.defaults``。

首先，进入 ``module_config`` 文件夹，创建一个子文件夹来存放模组配置的配置文件（文件夹名称为小写），然后在其中加入配置文件 IDF_VERSION、patch、at_customize.csv、partitions_at.csv、sdkconfig.defaults 以及 sdkconfig_silence.defaults。

本例中，我们复制粘贴 ``module_{IDF_TARGET_PATH_NAME}_default`` 文件夹及其中的配置文件，并重命名为 ``module_{IDF_TARGET_PATH_NAME}-user-defined``。在本例中，配置文件 IDF_VERSION、patch、at_customize.csv 和 partitions_at.csv 无需修改，我们只需修改 sdkconfig.defaults 和 sdkconfig_silence.defaults：

- 使用 ``module_{IDF_TARGET_PATH_NAME}-user-defined`` 文件夹下的分区表，需要修改如下配置

  ::

    CONFIG_PARTITION_TABLE_CUSTOM_FILENAME="module_config/module_{IDF_TARGET_PATH_NAME}-user-defined/partitions_at.csv"
    CONFIG_PARTITION_TABLE_FILENAME="module_config/module_{IDF_TARGET_PATH_NAME}-user-defined/partitions_at.csv"
    CONFIG_AT_CUSTOMIZED_PARTITION_TABLE_FILE="module_config/module_{IDF_TARGET_PATH_NAME}-user-defined/at_customize.csv"

.. only:: esp32c2 or esp32c3 or esp32c5 or esp32c6 or esp32c61

  - 使用 SPI 配置，移除 UART 配置
  
    - 移除 UART 配置
    
      ::
  
        CONFIG_AT_BASE_ON_UART=n
  
    - 新增 SPI 配置
  
      ::
  
        CONFIG_AT_BASE_ON_SPI=y
        CONFIG_SPI_STANDARD_MODE=y
        CONFIG_SPI_SCLK_PIN=6
        CONFIG_SPI_MOSI_PIN=7
        CONFIG_SPI_MISO_PIN=2
        CONFIG_SPI_CS_PIN=10
        CONFIG_SPI_HANDSHAKE_PIN=3
        CONFIG_SPI_NUM=1
        CONFIG_SPI_MODE=0
        CONFIG_TX_STREAM_BUFFER_SIZE=4096
        CONFIG_RX_STREAM_BUFFER_SIZE=4096

.. only:: esp32 or esp32s2

  - 添加启用 :ref:`文件系统 AT 命令 <FS-AT>` 配置
    
    ::
  
      CONFIG_AT_FS_COMMAND_SUPPORT=y

完成上述步骤后，可重新编译 ESP-AT 工程生成模组固件。本例中，我们在本地编译 AT 固件 :ref:`第三步安装环境 <esp-at-install-env>` 时，就可以选择 ``PLATFORM_{IDF_TARGET_CFG_PREFIX}`` 和 ``{IDF_TARGET_CFG_PREFIX}-USER-DEFINED`` 来生成 AT 固件。

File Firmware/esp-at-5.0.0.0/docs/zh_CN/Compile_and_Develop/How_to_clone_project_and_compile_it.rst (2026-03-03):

本地编译 ESP-AT 工程
=============================

{IDF_TARGET_COMPILE_MNAME: default="undefined", esp32="WROOM-32", esp32c2="ESP32C2-4MB", esp32c3="MINI-1", esp32c5="ESP32C5-4MB", esp32c6="ESP32C6-4MB", esp32c61="ESP32C6-4MB", esp32s2="MINI"}
{IDF_TARGET_PRODUCT_NAME: default="undefined", esp32="ESP32-WROOM-32D", esp32c2="ESP8684-MINI-1 4MB", esp32c3="ESP32-C3-MINI-1", esp32c5="ESP32-C5-WROOM-1", esp32c6="ESP32-C6-MINI-1", esp32c61="ESP32-C61-WROOM-1", esp32s2="ESP32-S2-MINI"}
{IDF_TARGET_VER: default="5.4", esp32c5="5.5", esp32c61="5.5"}

:link_to_translation:`en:[English]`

.. only:: esp32 or esp32c3 or esp32c5 or esp32c6 or esp32c61

  本文档详细介绍了如何本地编译 ESP-AT 工程，并将生成的固件烧录到 {IDF_TARGET_NAME} 设备中。当默认的 :doc:`官方发布的固件 <../AT_Binary_Lists/index>` 无法满足需求时，如您需要自定义 :doc:`AT 端口管脚 <How_to_set_AT_port_pin>`、:doc:`低功耗蓝牙服务 <How_to_customize_BLE_services>` 以及 :doc:`分区 <How_to_customize_partitions>` 等，那么就需要编译 ESP-AT 工程。

.. only:: esp32c2 or esp32s2

  本文档详细介绍了如何本地编译 ESP-AT 工程，并将生成的固件烧录到 {IDF_TARGET_NAME} 设备中。当默认的 :doc:`官方发布的固件 <../AT_Binary_Lists/index>` 无法满足需求时，如您需要自定义 :doc:`AT 端口管脚 <How_to_set_AT_port_pin>` 以及 :doc:`分区 <How_to_customize_partitions>` 等，那么就需要编译 ESP-AT 工程。

如果本地编译 ESP-AT 工程有困难，或者需要修改的代码量较少，推荐您通过 :doc:`如何在 GitHub 网页上编译 ESP-AT 工程 <How_to_build_project_with_web_page>`。

.. _esp-at-started-steps:

详细步骤
^^^^^^^^^^^^^

请根据下方详细步骤，完成 ESP-AT 工程的克隆、环境安装、配置、编译以及烧录。**推荐您优先选择 Linux 系统开发。**

* :ref:`esp-at-idf-prerequisites`
* :ref:`esp-at-get-at-sdk`
* :ref:`esp-at-install-env`
* :ref:`esp-at-hardware-connection`
* :ref:`esp-at-project-config`
* :ref:`esp-at-project-build`
* :ref:`esp-at-project-flash`
* :ref:`esp-at-project-advanced-usage`

.. _esp-at-idf-prerequisites:

第一步：ESP-IDF 快速入门
^^^^^^^^^^^^^^^^^^^^^^^^^^^^

在编译 ESP-AT 工程之前，请先学习使用 ESP-IDF，因为 ESP-AT 是基于 ESP-IDF 开发的。

请您根据 `ESP-IDF v{IDF_TARGET_VER} 快速入门文档 <https://docs.espressif.com/projects/esp-idf/zh_CN/release-v{IDF_TARGET_VER}/{IDF_TARGET_PATH_NAME}/get-started/index.html>`__ 的指导，完成 ``hello_world`` 工程的配置、编译以及下载固件至 {IDF_TARGET_NAME} 开发板等步骤。

.. note::

  此步骤不是必须的，但如果您是初学者，强烈建议您完成此步骤，以熟悉 ESP-IDF 并确保顺利进行以下步骤。

完成上一步的 ESP-IDF 快速入门后，便可以开始下面的 ESP-AT 工程的编译。

.. _esp-at-get-at-sdk:

第二步：获取 ESP-AT
^^^^^^^^^^^^^^^^^^^^^^^

编译 ESP-AT 工程需下载乐鑫提供的软件库文件 ESP-AT 仓库。

打开终端，切换到您要保存 ESP-AT 的工作目录，使用 ``git clone`` 命令克隆远程仓库，获取 ESP-AT 的本地副本。以下是不同操作系统的获取方式。

- Linux 或 macOS

  ::

    cd ~/esp
    git clone --recursive https://github.com/espressif/esp-at.git

- Windows

  对于 {IDF_TARGET_NAME} 系列模组，推荐您以管理员权限运行 `ESP-IDF {IDF_TARGET_VER} CMD <https://dl.espressif.com/dl/esp-idf/?idf={IDF_TARGET_VER}>`__。

  ::

    cd %userprofile%\esp
    git clone --recursive https://github.com/espressif/esp-at.git

如果您在中国或无法访问 GitHub 的地区，可以通过以下镜像更快地克隆 ESP-AT：``git clone https://jihulab.com/esp-mirror/espressif/esp-at.git``。

ESP-AT 将下载至 Linux 和 macOS 的 ``~/esp/esp-at``、Windows 的 ``%userprofile%\esp\esp-at``。

.. note::

    在本文档中，Linux 和 macOS 操作系统中 ESP-AT 的默认安装路径为 ``~/esp``；Windows 操作系统的默认路径为 ``%userprofile%\esp``。您也可以将 ESP-AT 安装在任何其它路径下，但请注意在使用命令行时进行相应替换。注意，ESP-AT 不支持带有空格的路径。

.. _esp-at-install-env:

第三步：安装环境
^^^^^^^^^^^^^^^^^^^^^^^

运行项目工具 ``install`` 来安装环境。此安装工具将自动安装依赖的 Python 包、ESP-IDF 仓库以及 ESP-IDF 依赖的编译器、工具等。

- Linux 或 macOS
  
  ::
    
    ./build.py install

- Windows

  ::
    
    python build.py install

如果是第一次安装环境，请为 {IDF_TARGET_NAME} 设备选择以下配置选项。

  - 选择 ``Platform name``，例如 {IDF_TARGET_NAME} 系列设备选择 ``PLATFORM_{IDF_TARGET_CFG_PREFIX}``。``Platform name`` 由 :component_file:`factory_param_data.csv <customized_partitions/raw_data/factory_param/factory_param_data.csv>` 定义。
  - 选择 ``Module name``，例如 {IDF_TARGET_PRODUCT_NAME} 模组选择 ``{IDF_TARGET_COMPILE_MNAME}``。``Module name`` 由 :component_file:`factory_param_data.csv <customized_partitions/raw_data/factory_param/factory_param_data.csv>` 定义。

  .. _esp-at_silence_mode_cfg:

  - 在选择启用或禁用 silence mode 之前，请先阅读 :doc:`文档 <../Compile_and_Develop/How_to_configure_silence_mode>`，了解 silence mode。一般情况下请禁用。
  - 如果 ``build/module_info.json`` 文件存在，上述三个配置选项将不会出现。因此，如果您想重新配置模组信息，请删除该文件。

  .. only:: esp32

    以设置 ``Platform name`` 为 ``ESP32``，``Module name`` 为 ``WROOM-32``，并启用 silence mode 为例：

    .. code-block:: none

        $ ./build.py install
        Ready to install ESP-IDF prerequisites..
    
        ... (more lines of install ESP-IDF prerequisites)

        Ready to install ESP-AT prerequisites..

        ... (more lines of install ESP-IDF prerequisites)

        Platform name:
        1. PLATFORM_ESP32
        ...
        choose(range[1,7]):1

        Module name:
        1. WROOM-32 (Firmware description: ...)
        ...
        choose(range[1,7]):1

        Enable silence mode to remove some logs and reduce the firmware size?
        0. No
        1. Yes
        choose(range[0,1]):1
        Platform name:ESP32 Module name:WROOM-32 Silence:1
        Cloning into 'esp-idf'...

        ... (more lines of clone esp-idf)

        Ready to set up ESP-IDF tools..

        ... (more lines of set up ESP-IDF tools)

        All done! You can now run:

        ./build.py build

  .. only:: esp32c2

    以设置 ``Platform name`` 为 ``ESP32C2``，``Module name`` 为 ``ESP32C2-4MB``，并禁用 silence mode 为例：

    .. code-block:: none

        $ ./build.py install
        Ready to install ESP-IDF prerequisites..
    
        ... (more lines of install ESP-IDF prerequisites)

        Ready to install ESP-AT prerequisites..

        ... (more lines of install ESP-IDF prerequisites)

        Platform name:
        ...
        3. PLATFORM_ESP32C2
        ...
        choose(range[1,7]):3

        Module name:
        ...
        2. ESP32C2-4MB (Firmware description: ...)
        ...
        choose(range[1,3]):2

        Enable silence mode to remove some logs and reduce the firmware size?
        0. No
        1. Yes
        choose(range[0,1]):0
        Platform name:ESP32C2 Module name:ESP32C2-4MB Silence:0
        Cloning into 'esp-idf'...

        ... (more lines of clone esp-idf)

        Ready to set up ESP-IDF tools..

        ... (more lines of set up ESP-IDF tools)

        All done! You can now run:

        ./build.py build

  .. only:: esp32c3

    以设置 ``Platform name`` 为 ``ESP32C3``，``Module name`` 为 ``MINI-1``，并禁用 silence mode 为例：

    .. code-block:: none

        $ ./build.py install
        Ready to install ESP-IDF prerequisites..
    
        ... (more lines of install ESP-IDF prerequisites)

        Ready to install ESP-AT prerequisites..

        ... (more lines of install ESP-IDF prerequisites)

        Platform name:
        ...
        2. PLATFORM_ESP32C3
        ...
        choose(range[1,7]):2

        Module name:
        1. MINI-1 (Firmware description: ...)
        ...
        choose(range[1,3]):1

        Enable silence mode to remove some logs and reduce the firmware size?
        0. No
        1. Yes
        choose(range[0,1]):0
        Platform name:ESP32C3 Module name:MINI-1 Silence:0
        Cloning into 'esp-idf'...

        ... (more lines of clone esp-idf)

        Ready to set up ESP-IDF tools..

        ... (more lines of set up ESP-IDF tools)

        All done! You can now run:

        ./build.py build

  .. only:: esp32c5

    以设置 ``Platform name`` 为 ``ESP32C5``，``Module name`` 为 ``ESP32C5-4MB``，并禁用 silence mode 为例：

    .. code-block:: none

        $ ./build.py install
        Ready to install ESP-IDF prerequisites..
    
        ... (more lines of install ESP-IDF prerequisites)

        Ready to install ESP-AT prerequisites..

        ... (more lines of install ESP-IDF prerequisites)

        Platform name:
        ...
        4. PLATFORM_ESP32C5
        ...
        choose(range[1,7]):4

        Module name:
        1. ESP32C5-4MB (Firmware description: ...)
        ...
        choose(range[1,2]):1

        Enable silence mode to remove some logs and reduce the firmware size?
        0. No
        1. Yes
        choose(range[0,1]):0
        Platform name:ESP32C5 Module name:ESP32C5-4MB Silence:0

        Cloning into 'esp-idf'...

        ... (more lines of clone esp-idf)

        Ready to set up ESP-IDF tools..

        ... (more lines of set up ESP-IDF tools)

        All done! You can now run:

        ./build.py build

  .. only:: esp32c6

    以设置 ``Platform name`` 为 ``ESP32C6``，``Module name`` 为 ``ESP32C6-4MB``，并禁用 silence mode 为例：

    .. code-block:: none

        $ ./build.py install
        Ready to install ESP-IDF prerequisites..
    
        ... (more lines of install ESP-IDF prerequisites)

        Ready to install ESP-AT prerequisites..

        ... (more lines of install ESP-IDF prerequisites)

        Platform name:
        ...
        5. PLATFORM_ESP32C6
        ...
        choose(range[1,7]):5

        Module name:
        1. ESP32C6-4MB (Firmware description: ...)
        choose(range[1,1]):1

        Enable silence mode to remove some logs and reduce the firmware size?
        0. No
        1. Yes
        choose(range[0,1]):0
        Platform name:ESP32C6 Module name:ESP32C6-4MB Silence:0

        Cloning into 'esp-idf'...

        ... (more lines of clone esp-idf)

        Ready to set up ESP-IDF tools..

        ... (more lines of set up ESP-IDF tools)

        All done! You can now run:

        ./build.py build

  .. only:: esp32c61

    以设置 ``Platform name`` 为 ``ESP32C61``，``Module name`` 为 ``ESP32C61-4MB``，并禁用 silence mode 为例：

    .. code-block:: none

        $ ./build.py install
        Ready to install ESP-IDF prerequisites..
    
        ... (more lines of install ESP-IDF prerequisites)

        Ready to install ESP-AT prerequisites..

        ... (more lines of install ESP-IDF prerequisites)

        Platform name:
        ...
        6. PLATFORM_ESP32C61
        ...
        choose(range[1,7]):6

        Module name:
        1. ESP32C61-4MB (Firmware description: ...)
        choose(range[1,1]):1

        Enable silence mode to remove some logs and reduce the firmware size?
        0. No
        1. Yes
        choose(range[0,1]):0
        Platform name:ESP32C61 Module name:ESP32C61-4MB Silence:0

        Cloning into 'esp-idf'...

        ... (more lines of clone esp-idf)

        Ready to set up ESP-IDF tools..

        ... (more lines of set up ESP-IDF tools)

        All done! You can now run:

        ./build.py build

  .. only:: esp32s2

    以设置 ``Platform name`` 为 ``ESP32S2``，``Module name`` 为 ``MINI``，并禁用 silence mode 为例：

    .. code-block:: none

        $ ./build.py install
        Ready to install ESP-IDF prerequisites..
    
        ... (more lines of install ESP-IDF prerequisites)

        Ready to install ESP-AT prerequisites..

        ... (more lines of install ESP-IDF prerequisites)

        Platform name:
        ...
        7. PLATFORM_ESP32S2
        choose(range[1,7]):7

        Module name:
        1. MINI (Firmware description: ...)
        choose(range[1,1]):1

        Enable silence mode to remove some logs and reduce the firmware size?
        0. No
        1. Yes
        choose(range[0,1]):0
        Platform name:ESP32S2 Module name:MINI Silence:0

        Cloning into 'esp-idf'...

        ... (more lines of clone esp-idf)

        Ready to set up ESP-IDF tools..

        ... (more lines of set up ESP-IDF tools)

        All done! You can now run:

        ./build.py build

.. _esp-at-hardware-connection:

第四步：连接设备
^^^^^^^^^^^^^^^^

使用 USB 线将您的 {IDF_TARGET_NAME} 设备连接到 PC 上，以下载固件和输出日志，详情请见 :doc:`../Get_Started/Hardware_connection`。注意，如果您在编译过程中不发送 AT 命令和接收 AT 响应，则不需要建立 "AT 命令/响应" 连接。关于更改默认端口管脚的信息请参考 :doc:`How_to_set_AT_port_pin`。

.. _esp-at-project-config:

第五步：配置工程
^^^^^^^^^^^^^^^^

运行项目工具 ``menuconfig`` 来配置。

- Linux 或 macOS
  
  ::
    
    ./build.py menuconfig

- Windows

  ::
    
    python build.py menuconfig

如果以上所有步骤都正确，则会弹出下面的菜单：

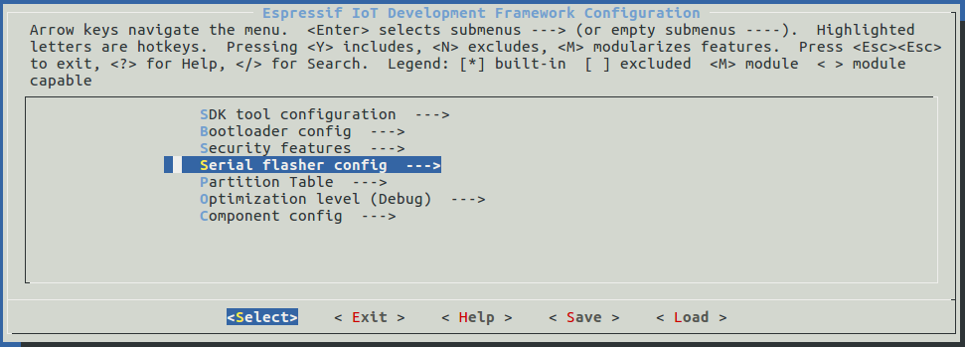
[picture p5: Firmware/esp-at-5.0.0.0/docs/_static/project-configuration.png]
工程配置 - 主窗口


   工程配置 - 主窗口

此菜单可以用来配置每个工程，如更改 AT 端口管脚、启用经典蓝牙功能等，如果不修改配置，那么就会按照默认配置编译工程。

.. _esp-at-project-build:

第六步：编译工程
^^^^^^^^^^^^^^^^

运行以下命令编译工程。

- Linux 或 macOS

::

  ./build.py build

- Windows

::

  python build.py build

如果启用了蓝牙功能，固件尺寸会大大增加。请确保它不超过 ota 分区的大小。

编译完成后会在 ``build/factory`` 路径下生成打包好的量产固件。更多信息请参见 :doc:`esp-at_firmware_differences`。

.. _esp-at-project-flash:

第七步：烧录到设备
^^^^^^^^^^^^^^^^^^^^^^

运行以下命令将生成的固件烧录到 {IDF_TARGET_NAME} 设备上。

- Linux 或 macOS

::

  ./build.py -p (PORT) flash

- Windows

::

  python build.py -p (PORT) flash

注意请用 {IDF_TARGET_NAME} 设备的串口名称替换 ``(PORT)``。或者按照提示信息将固件烧录到 flash 中。仍然需要注意替换 ``(PORT)``。

如果 ESP-AT bin 不能启动，并且打印出 "ota data partition invalid"，请运行 ``python build.py erase_flash`` 来擦除整个 flash，然后重新烧录 AT 固件。

.. _esp-at-project-advanced-usage:

build.py 进阶用法
^^^^^^^^^^^^^^^^^^^^^^

``build.py`` 脚本是基于 `idf.py <https://docs.espressif.com/projects/esp-idf/zh_CN/release-v{IDF_TARGET_VER}/{IDF_TARGET_PATH_NAME}/api-guides/build-system.html#idf-py>`__ 封装的工具（即 ``idf.py <cmd>`` 功能均包含在 ``build.py <cmd>`` 里），您可以运行以下命令查看更多用法。

- Linux 或 macOS

::

  ./build.py --help

- Windows

::

  python build.py --help

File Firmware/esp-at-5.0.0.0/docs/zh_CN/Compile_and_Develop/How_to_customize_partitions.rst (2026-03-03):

如何自定义分区
===========================

{IDF_TARGET_AT_SECOND_PARTITION_ADDR: default="undefined", esp32="0x20000", esp32c2="0x1E000", esp32c3="0x1E000", esp32c5="0x30000", esp32c6="0x1E000", esp32c61="0x30000", esp32s2="0x20000"}
{IDF_TARGET_PRODUCT_NAME: default="undefined", esp32="ESP32-WROOM-32", esp32c2="ESP8684-MINI-1 4MB", esp32c3="ESP32-C3-MINI-1", esp32c5="ESP32-C5-WROOM-1", esp32c6="ESP32-C6-MINI-1", esp32c61="ESP32-C61-WROOM-1", esp32s2="ESP32-S2-MINI"}

:link_to_translation:`en:[English]`

本文档介绍了如何通过修改 ESP-AT 提供的 at_customize.csv 表来自定义 {IDF_TARGET_NAME} 设备中的分区。共有两个分区表：一级分区表和二级分区表。

一级分区表 partitions_at.csv 供系统使用，在此基础上生成 partitions_at.bin 文件。如果一级分区表出错，系统将无法启动。因此，不建议修改 partitions_at.csv。

ESP-AT 提供了二级分区表 at_customize.csv 供您存储自定义数据块。它基于一级分区表。

要修改 {IDF_TARGET_NAME} 设备中的分区，请按照前三个步骤操作。第四部分举例说明了前三个步骤。

- :ref:`modify-at-customize-csv`
- :ref:`generate-at-customize-bin`
- :ref:`flash-at-customize-bin-into-ESP`
- :ref:`customize-partition-example`

.. _modify-at-customize-csv:

修改 at_customize.csv
-----------------------

请参考下表找到模组的 at_customize.csv。

.. only:: esp32

  .. list-table:: at_customize.csv 路径
    :header-rows: 1

    * - 平台
      - 模组
      - 路径
    * - ESP32
      - - WROOM-32
        - PICO-D4
        - SOLO-1
        - MINI-1
      - :project_file:`module_config/module_esp32_default/at_customize.csv`
    * - ESP32
      - WROVER-32
      - :project_file:`module_config/module_wrover-32/at_customize.csv`
    * - ESP32
      - ESP32-D2WD
      - :project_file:`module_config/module_esp32-d2wd/at_customize.csv`

.. only:: esp32c2

  .. list-table:: at_customize.csv 路径
    :header-rows: 1

    * - 平台
      - 模组
      - 路径
    * - ESP32-C2
      - ESP32C2-2MB（所有带 2 MB flash 的 ESP32-C2（ESP8684） 系列）
      - :project_file:`module_config/module_esp32c2-2mb/at_customize.csv`
    * - ESP32-C2
      - ESP32C2-4MB（所有带 4 MB flash 的 ESP32-C2（ESP8684） 系列）
      - :project_file:`module_config/module_esp32c2_default/at_customize.csv`

.. only:: esp32c3

  .. list-table:: at_customize.csv 路径
    :header-rows: 1

    * - 平台
      - 模组
      - 路径
    * - ESP32-C3
      - MINI-1
      - :project_file:`module_config/module_esp32c3_default/at_customize.csv`

.. only:: esp32c5

  .. list-table:: at_customize.csv 路径
    :header-rows: 1

    * - 平台
      - 模组
      - 路径
    * - ESP32-C5
      - ESP32C5-4MB（所有带 4 MB flash 的 ESP32-C5 系列）
      - :project_file:`module_config/module_esp32c5_default/at_customize.csv`

.. only:: esp32c6

  .. list-table:: at_customize.csv 路径
    :header-rows: 1

    * - 平台
      - 模组
      - 路径
    * - ESP32-C6
      - ESP32C6-4MB（所有带 4 MB flash 的 ESP32-C6 系列）
      - :project_file:`module_config/module_esp32c6_default/at_customize.csv`

.. only:: esp32c61

  .. list-table:: at_customize.csv 路径
    :header-rows: 1

    * - 平台
      - 模组
      - 路径
    * - ESP32-C61
      - ESP32C61-4MB（所有带 4 MB flash 的 ESP32-C61 系列）
      - :project_file:`module_config/module_esp32c61_default/at_customize.csv`

.. only:: esp32s2

  .. list-table:: at_customize.csv 路径
    :header-rows: 1

    * - 平台
      - 模组
      - 路径
    * - ESP32-S2
      - MINI
      - :project_file:`module_config/module_esp32s2_default/at_customize.csv`

然后，在修改 at_customize.csv 时遵循以下规则。

- 已定义的用户分区的 ``Name`` 和 ``Type`` 不可更改，但 ``SubType``、``Offset`` 和 ``Size`` 可以更改。
- 如果您需要添加一个新的用户分区，请先检查它是否已经在 ESP-IDF (``esp_partition.h``) 中定义。

    - 如果已定义，请保持 ``Type`` 值与 ESP-IDF 的相同。
    - 如果未定义，请将 ``Type`` 设置为 ``0x40``。
- 用户分区的 ``Name`` 不应超过 ``16`` 字节。
- ``at_customize`` 分区的默认大小定义在 partitions_at.csv 表中，添加新用户分区时请不要超出范围。

.. _generate-at-customize-bin:

生成 at_customize.bin
--------------------------

修改 at_customize.csv 后，您可以重新编译 ESP-AT 工程或使用 python 脚本 ``gen_esp32part.py`` 来生成 at_customize.bin 文件。

如果使用脚本，在 ESP-AT 工程根目录下执行以下命令，并替换 ``INPUT`` 和 ``OUTPUT``。

::

    python esp-idf/components/partition_table/gen_esp32part.py <INPUT> [OUTPUT]

- ``INPUT`` 替换为待解析的 at_customize.csv 或二进制文件的路径。
- ``OUTPUT`` 替换为生成的二进制或 CSV 文件的路径，如果省略，将使用标准输出。

.. _flash-at-customize-bin-into-ESP:

烧录 at_customize.bin 至 {IDF_TARGET_NAME} 设备
-----------------------------------------------------

将 at_customize.bin 下载到 flash 中。关于如何将二进制文件烧录至 {IDF_TARGET_NAME} 设备，请参考 :ref:`flash-at-firmware-into-your-device`。下表为不同模组 at_customize.bin 文件的下载地址。

.. only:: esp32

  .. list-table:: 不同模组 at_customize.bin 的下载地址
    :header-rows: 1

    * - 平台
      - 模组
      - 地址
      - 大小
    * - ESP32
      - - WROOM-32
        - WROVER-32
        - PICO-D4
        - SOLO-1
        - MINI-1
        - ESP32-D2WD
      - 0x20000
      - 0xE0000

.. only:: esp32c2

  .. list-table:: 不同模组 at_customize.bin 的下载地址
    :header-rows: 1

    * - 平台
      - 模组
      - 地址
      - 大小
    * - ESP32-C2
      - ESP32C2-2MB（所有带 2 MB flash 的 ESP32-C2（ESP8684） 系列）
      - 0x1A000
      - 0x26000
    * - ESP32-C2
      - ESP32C2-4MB（所有带 4 MB flash 的 ESP32-C2（ESP8684） 系列）
      - {IDF_TARGET_AT_SECOND_PARTITION_ADDR}
      - 0x42000

.. only:: esp32c3

  .. list-table:: 不同模组 at_customize.bin 的下载地址
    :header-rows: 1

    * - 平台
      - 模组
      - 地址
      - 大小
    * - ESP32-C3
      - MINI-1
      - 0x1E000
      - 0x42000

.. only:: esp32c6

  .. list-table:: 不同模组 at_customize.bin 的下载地址
    :header-rows: 1

    * - 平台
      - 模组
      - 地址
      - 大小
    * - {IDF_TARGET_NAME}
      - {IDF_TARGET_CFG_PREFIX}-4MB（所有带 4 MB flash 的 {IDF_TARGET_NAME} 系列）
      - 0x1E000
      - 0x42000

.. only:: esp32c5 or esp32c61

  .. list-table:: 不同模组 at_customize.bin 的下载地址
    :header-rows: 1

    * - 平台
      - 模组
      - 地址
      - 大小
    * - {IDF_TARGET_NAME}
      - {IDF_TARGET_CFG_PREFIX}-4MB（所有带 4 MB flash 的 {IDF_TARGET_NAME} 系列）
      - 0x30000
      - 0x70000

.. only:: esp32s2

  .. list-table:: 不同模组 at_customize.bin 的下载地址
    :header-rows: 1

    * - 平台
      - 模组
      - 地址
      - 大小
    * - ESP32-S2
      - MINI
      - 0x20000
      - 0xE0000

在某些情况下，必须将 at_customize.bin 下载到 flash 后才能使用一些 AT 命令：

- :ref:`cmd-SYSFLASH`
- :ref:`cmd-FS`
- ``SSL`` 服务器相关命令
- ``BLE`` 服务器相关命令

.. _customize-partition-example:

示例
-------

本节介绍如何将名为 ``test`` 的 4 KB 分区添加到 {IDF_TARGET_PRODUCT_NAME} 模组中。

首先找到 {IDF_TARGET_PRODUCT_NAME} 的 at_customize.csv 表，设置新分区的 ``Name``、``Type``、``SubType``、``Offset`` 和 ``Size``。

.. only:: esp32 or esp32s2

  ::

      # Name,Type,SubType,Offset,Size
      ... ...
      test,0x40,15,0x3D000,4K
      fatfs,data,fat,0x70000,576K

.. only:: esp32c2 or esp32c3 or esp32c5 or esp32c6 or esp32c61

  ::

      # Name,Type,SubType,Offset,Size
      ... ...
      test,0x40,15,0x3E000,4K
      fatfs,data,fat,0x47000,100K

第二步，重新编译 ESP-AT 工程，或者在 ESP-AT 根目录下执行 python 脚本生成 at_customize.bin。

::

    python esp-idf/components/partition_table/gen_esp32part.py -q ./module_config/module_{IDF_TARGET_PATH_NAME}_default/at_customize.csv at_customize.bin

然后，ESP-AT 根目录中会生成 at_customize.bin。

第三步，下载 at_customize.bin 至 flash。

在 ESP-AT 工程根目录下执行以下命令，并替换 ``PORT`` 和 ``BAUD``。

::

    python esp-idf/components/esptool_py/esptool/esptool.py -p PORT -b BAUD --before default_reset --after hard_reset --chip auto  write_flash --flash_mode dio --flash_size detect --flash_freq 40m {IDF_TARGET_AT_SECOND_PARTITION_ADDR} ./at_customize.bin

- ``PORT`` 替换为端口名称。
- ``BAUD`` 替换为波特率。

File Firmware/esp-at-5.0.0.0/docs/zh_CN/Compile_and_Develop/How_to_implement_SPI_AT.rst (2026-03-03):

SPI AT 指南
=============

:link_to_translation:`en:[English]`

本文档主要介绍 SPI AT 的实现与使用，主要涉及以下几个方面：

.. contents::
   :local:
   :depth: 1

简介
------

SPI AT 基于 AT 工程，使用 SPI 协议进行数据通信。在使用 SPI AT 时，MCU 设备作为 SPI master，{IDF_TARGET_NAME} 设备作为 SPI slave，通信双方通过 SPI 协议实现基于 AT 命令的数据交互。

使用 SPI AT 的优势
^^^^^^^^^^^^^^^^^^^

AT 工程默认使用 UART 协议进行数据通信，但是 UART 协议在一些需要高速传输数据的应用场景并不适用，因此，使用支持更高传输速率的 SPI 协议传输数据成为一种较好的选择。

如何启用 SPI AT？
^^^^^^^^^^^^^^^^^^^

您可以通过下述步骤配置并启用 SPI AT：

1. 通过 ``./build.py menuconfig`` -> ``Component config`` -> ``AT`` -> ``communicate method for AT command`` -> ``AT through SPI`` 使能 SPI AT。
2. 通过 ``./build.py menuconfig`` -> ``Component config`` -> ``AT`` -> ``communicate method for AT command`` -> ``AT SPI Data Transmission Mode`` 选择 SPI 数据传输模式。
3. 通过 ``./build.py menuconfig`` -> ``Component config`` -> ``AT`` -> ``communicate method for AT command`` -> ``AT SPI GPIO settings`` 配置 SPI 使用的 GPIO 管脚。
4. 通过 ``./build.py menuconfig`` -> ``Component config`` -> ``AT`` -> ``communicate method for AT command`` -> ``AT SPI driver settings`` 选择 SPI 从机的工作模式，并配置相关缓存区的大小。
5. 重新编译 ``esp-at`` 工程（参考 :doc:`../Compile_and_Develop/How_to_clone_project_and_compile_it`），烧录新的固件并运行。

SPI AT 默认管脚
^^^^^^^^^^^^^^^^

下表给出了不同系列的 {IDF_TARGET_NAME} 设备使用 SPI AT 时默认的硬件管脚：

.. only:: esp32c2 or esp32c3

  .. list-table:: SPI AT 默认管脚
    :widths: 10 25
    :header-rows: 1

    * - 信号
      - GPIO 编号
    * - SCLK
      - 6
    * - MISO
      - 2
    * - MOSI
      - 7
    * - CS
      - 10
    * - HANDSHAKE
      - 3
    * - GND
      - GND
    * - QUADWP (qio/qout) :sup:`1`
      - 8
    * - QUADHD (qio/qout) :sup:`1`
      - 9

.. only:: esp32c6 or esp32c61

  .. list-table:: SPI AT 默认管脚
    :widths: 10 25
    :header-rows: 1

    * - 信号
      - GPIO 编号
    * - SCLK
      - 19
    * - MISO
      - 20
    * - MOSI
      - 18
    * - CS
      - 23
    * - HANDSHAKE
      - 21
    * - GND
      - GND
    * - QUADWP (qio/qout) :sup:`1`
      - 22
    * - QUADHD (qio/qout) :sup:`1`
      - 2

.. only:: esp32c5

  .. list-table:: SPI AT 默认管脚
    :widths: 10 25
    :header-rows: 1

    * - 信号
      - GPIO 编号
    * - SCLK
      - 6
    * - MISO
      - 2
    * - MOSI
      - 7
    * - CS
      - 10
    * - HANDSHAKE
      - 3
    * - GND
      - GND
    * - QUADWP (qio/qout) :sup:`1`
      - 5
    * - QUADHD (qio/qout) :sup:`1`
      - 4

**说明** 1：QUADWP 引脚和 QUADHD 引脚仅在使用 4 线 SPI 工作时使用。

您可以通过 ``./build.py menuconfig`` > ``Component config`` > ``AT`` > ``communicate method for AT command`` > ``AT through SPI`` > ``AT SPI GPIO settings``，然后编译工程来配置 SPI AT 对应的管脚（参考 :doc:`../Compile_and_Develop/How_to_clone_project_and_compile_it`）。

使用 SPI AT
--------------

在使用 SPI AT 时，{IDF_TARGET_NAME} 设备上运行的 SPI slave 工作在半双工通信模式下。

握手线 (handshake line)
^^^^^^^^^^^^^^^^^^^^^^^^

SPI 是一种 master-slave 结构的外设，所有的传输均由 master 发起，slave 无法主动传输数据。但是，使用 AT 命令进行数据交互时，需要 {IDF_TARGET_NAME} 设备主动能够主动上报一些信息。因此，我们在 SPI master 和 slave 之间添加了一个握手线，来实现 slave 主动向 master 上报信息的功能。

当 slave 需要传输数据时，将会把握手管脚主动拉高，这会在 master 侧产生一个上升沿的 GPIO 中断，master 发起与 slave 的通信，传输完成后，slave 将握手管脚拉低，结束此次通信。 

使用握手线的具体方法为：

- Master 向 slave 发送 AT 数据时，使用握手线的方法为：

  1. master 向 slave 发送请求传输数据的请求，然后等待 slave 向握手线发出的允许发送数据的信号。
  2. master 检测到握手线上的 slave 发出的允许发送的信号后，开始发送数据。
  3. master 发送数据后，通知 slave 数据发送结束。

- Master 接收 slave 发送的 AT 数据时，使用握手线的方法为：

  1. slave 通过握手线通知 master 开始接收数据。
  2. master 接收数据，并在接收所有数据后，通知 slave 数据已经全部接收。

通信格式
^^^^^^^^^^^^

SPI AT 的通信格式为 CMD+ADDR+DUMMY+DATA（读/写）。在使用 SPI AT 时，SPI master 使用到的一些通信报文介绍如下：

- Master 向 slave 发送数据时的通信报文：

.. list-table:: 主机向从机发送数据
   :header-rows: 1
   :widths: 25 25 15 30

   * - CMD（1 字节）
     - ADDR（1 字节）
     - DUMMY（1 字节）
     - DATA（高达 4092 字节）
   * - 0x3
     - 0x0
     - 0x0
     - data_buffer

- Master 向 slave 发送数据结束后，需要发送一条通知消息来结束本次传输，具体的通信报文为：

.. list-table:: 主机通知从机，主机发送数据已经结束
   :header-rows: 1
   :widths: 25 25 15 30

   * - CMD（1 字节）
     - ADDR（1 字节）
     - DUMMY（1 字节）
     - DATA
   * - 0x7
     - 0x0
     - 0x0
     - null

- Master 接收 slave 发送的数据时的通信报文：

.. list-table:: 主机读取从机发送的数据
   :header-rows: 1
   :widths: 25 25 15 30

   * - CMD（1 字节）
     - ADDR（1 字节）
     - DUMMY（1 字节）
     - DATA（高达 4092 字节）
   * - 0x4
     - 0x0
     - 0x0
     - data_buffer

- Master 接收 slave 发送的数据后，需要发送一条通知消息来结束本次传输，具体的通信报文为：

.. list-table:: 主机通知从机，主机读取数据已经结束
   :header-rows: 1
   :widths: 25 25 15 30

   * - CMD（1 字节）
     - ADDR（1 字节）
     - DUMMY（1 字节）
     - DATA
   * - 0x8
     - 0x0
     - 0x0
     - null

- Master 向 slave 发送请求传输指定大小数据的通信报文：

.. list-table:: 主机向从机发送写数据请求
   :header-rows: 1
   :widths: 25 25 15 30

   * - CMD（1 字节）
     - ADDR（1 字节）
     - DUMMY（1 字节）
     - DATA（4 字节）
   * - 0x1
     - 0x0
     - 0x0
     - data_info

其中 4 字节的 data_info 中包含了本次请求传输数据的数据包信息，具体格式如下：

1. Master 向 slave 发送的数据的字节数，长度 0～15 bit。
2. Master 向 slave 发送的数据包的序列号，该序列号在 master 每次发送时递增，长度 16～23 bit。
3. Magic 值，长度 24～31 bit，固定为 0xFE。

- Master 检测到握手线上有 slave 发出的信号后，需要发送一条消息查询 slave 进入接收数据的工作模式，还是进入到发送数据的工作模式，具体的通信报文为：

.. list-table:: 主机发送请求，查询从机的可读/可写状态
   :header-rows: 1
   :widths: 25 25 15 30

   * - CMD（1 字节）
     - ADDR（1 字节）
     - DUMMY（1 字节）
     - DATA（4 字节）
   * - 0x2
     - 0x4
     - 0x0
     - slave_status

发送查询请求后，slave 返回的状态信息将存储在 4 字节的 slave_status 中，其具体的格式如下：

1. slave 需要向 master 发送的数据的字节数，长度 0～15 bit；仅当 slave 处于可读状态时，该字段数字有效。
2. 数据包序列号，长度 16～23 bit，当序列号达到最大值 0xFF 时，下一个数据包的序列号重新设置为 0x0。当 slave 处于可写状态时，该字段为 master 需向 slave 发送的下一下数据包的序列号；当 slave 处于可读状态时，该字段为 slave 向 master 发送的下一个数据包的序列号。
3. slave 的可读/可写状态，长度 24～31 bit， 其中，0x1 代表可读， 0x2 代表可写。

SPI AT 数据交互流程
^^^^^^^^^^^^^^^^^^^^^^
SPI AT 数据交互流程主要分为两个方面：

- SPI master 向 slave 发送 AT 命令 ：

.. code-block:: none

         | SPI master |                            | SPI slave |
                |                                        |
                |   -------step 1: request to send---->  |
                |                                        |
                |   <------step 2: GPIO interrupt------  |
                |                                        |
                |   -------step 3: read slave status-->  |
                |                                        |
                |   -------step 4: send data---------->  |
                |                                        |
                |   -------step 5: send done---------->  |

每个步骤具体的说明如下：

1. master 向 slave 发送请求向 slave 写数据的请求。
2. slave 接收 master 的发送请求，若此时 slave 允许接收数据，则向 slave_status 寄存器写入允许 master 写入的标志位，然后通过握手线触发 master 上的 GPIO 中断。
3. master 接收到中断后，读取 slave 的 slave_status 寄存器，检测到 slave 进入接收数据的状态。
4. master 开始向 slave 发送数据。
5. 发送数据结束后，master 向 slave 发送一条代表发送结束的消息。

- SPI slave 向 master 发送 AT 响应：

.. code-block:: none

         | SPI master |                            | SPI slave |
                |                                        |
                |   <------step 1: GPIO interrupt------  |
                |                                        |
                |   -------step 2: read slave status-->  |
                |                                        |
                |   <------step 3: send data-----------  |
                |                                        |
                |   -------step 4: receive done------->  |

每个步骤具体的说明如下：

1. slave 向 slave_status 寄存器写入允许 master 读取来自 slave 的数据的标志位,然后通过握手线触发 master 上的 GPIO 中断。
2. master 接收到中断后，读取 slave 的 slave_status 寄存器，检测到 slave 进入发送数据的状态。 
3. master 开始接收来自 slave 的数据。
4. 数据接收完毕后，master 向 slave 发送一条代表接收数据结束的消息。

**说明** 1. 为了方便理解，我们还以发送 AT 命令为例，提供了通信涉及的所有交互流程和逻辑分析仪数据，请参考 :example_file:`at_spi_master/spi/esp32_c_series/README.md`。

SPI AT 对应的 SPI master 侧示例代码
^^^^^^^^^^^^^^^^^^^^^^^^^^^^^^^^^^^^^^^^^^^^^^

SPI AT 本身是作为 SPI slave 使用的，使用 SPI master 与 SPI slave 进行通信的示例代码请参考 :example:`at_spi_master/spi/esp32_c_series`。

**说明** 1. 在使用 MCU 开发之前，强烈建议使用 ESP32-C3 或者 ESP32 模拟 MCU 作为 SPI master 来运行此示例，以方便在出现问题时更容易调试问题。

SPI AT 速率
--------------

测试说明
^^^^^^^^^

- 使用 ESP32 或者 ES32-C3 开发板作为 SPI master，运行 `ESP-AT <https://github.com/espressif/esp-at>`_ 中的 :example:`at_spi_master/spi/esp32_c_series` 目录的代码。其软硬件配置如下：

1. 硬件：CPU 工作频率设置为 240 MHz，flash SPI mode 配置为 QIO 模式，flash 频率设置为 40 MHz。

2. 软件：基于 ESP-IDF v4.3 的编译环境，并将示例代码中的 streambuffer 的大小调整为 8192 字节。

- 使用 {IDF_TARGET_NAME} 作为 SPI slave，编译并烧录 SPI AT 固件（参考 :doc:`../Compile_and_Develop/How_to_clone_project_and_compile_it`），并将 {IDF_TARGET_NAME} 配置工作在 TCP 透传模式。其软硬件配置如下：

1. 硬件：CPU 工作频率设置为 160 MHz。

2. 软件：SPI-AT 的实现代码中，将 streambuffer 的大小设置为 8192 字节，并使用 ESP-IDF 下的 example/wifi/iperf 中的 `sdkconfig.defaults.esp32c3 <https://github.com/espressif/esp-idf/blob/master/examples/wifi/iperf/sdkconfig.defaults.esp32c3>`_ 中的相关配置参数。

测试结果
^^^^^^^^^^^^

下表显示了我们在屏蔽箱中得到的通信速率结果：

.. only:: esp32c6 or esp32c3

  .. list-table:: SPI AT Wi-Fi TCP 通信速率
    :header-rows: 1
    :widths: 15 20 25 25

    * - Clock
      - SPI mode
      - master->slave
      - slave->master
    * - 10 M
      - Standard
      - 0.95 MByte/s
      - 1.00 MByte/s
    * - 10 M
      - Dual
      - 1.37 MByte/s
      - 1.29 MByte/s
    * - 10 M
      - Quad
      - 1.43 MByte/s
      - 1.31 MByte/s
    * - 20 M
      - Standard
      - 1.41 MByte/s
      - 1.30 MByte/s
    * - 20 M
      - Dual
      - 1.39 MByte/s
      - 1.30 MByte/s
    * - 20 M
      - Quad
      - 1.39 MByte/s
      - 1.30 MByte/s
    * - 40 M
      - Standard
      - 1.37 MByte/s
      - 1.30 MByte/s
    * - 40 M
      - Dual
      - 1.40 MByte/s
      - 1.31 MByte/s
    * - 40 M
      - Quad
      - 1.48 MByte/s
      - 1.31 MByte/s

  **说明** ：当 SPI 的时钟频率较高时，受限于上层网络组件的限制，使用 Dual 或者 Quad 工作模式的通信速率想比较于 Standard 模式并未显著改善。

.. only:: esp32c5

  .. list-table:: SPI AT Wi-Fi 5G TCP 通信速率
    :header-rows: 1
    :widths: 15 20 25 25

    * - Clock
      - SPI mode
      - master->slave
      - slave->master
    * - 26 M
      - Standard
      - 2.15 MByte/s
      - 2.25 MByte/s
    * - 26 M
      - Dual
      - 2.97 MByte/s
      - 2.59 MByte/s

**说明** ：更多关于 SPI 通信的介绍请参考对应模组的 `技术参考手册 <https://www.espressif.com/zh-hans/support/documents/technical-documents>`_。

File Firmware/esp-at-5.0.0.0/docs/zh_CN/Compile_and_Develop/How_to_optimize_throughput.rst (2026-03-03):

如何提高 ESP-AT 吞吐性能
=========================

:link_to_translation:`en:[English]`

默认情况下，ESP-AT 和主机之间使用 UART 进行通信，因此最高吞吐速率不会超过其默认配置，即不会超过 115200 bps。用户如要 ESP-AT 实现较高的吞吐量，需了解本文，并做出有针对性的配置。本文以 {IDF_TARGET_NAME} 为例，介绍如何提高 ESP-AT 吞吐性能。

.. note::

    本文基于 ESP-AT 处于 :term:`透传模式` 下，描述提高 TCP/UDP/SSL 吞吐性能的一般性方法。

用户可以选择下面其中一种方法，提高吞吐性能：

- `（简单）快速配置`_
- `（推荐）熟悉数据流、针对性地配置`_

（简单）快速配置
-----------------

**1. 配置系统、LWIP、Wi-Fi 适用于高吞吐的参数**

  将下面代码段拷贝并追加至 :project_file:`module_config/module_{IDF_TARGET_PATH_NAME}_default/sdkconfig.defaults` 文件最后，其它 {IDF_TARGET_NAME} 系列设备请修改对应文件夹下的 sdkconfig.defaults 文件。

  .. only:: esp32

    ::

      # System
      CONFIG_ESP_SYSTEM_EVENT_TASK_STACK_SIZE=4096
      CONFIG_FREERTOS_UNICORE=n
      CONFIG_FREERTOS_HZ=1000
      CONFIG_ESP_DEFAULT_CPU_FREQ_240=y
      CONFIG_ESP_DEFAULT_CPU_FREQ_MHZ=240
      CONFIG_ESPTOOLPY_FLASHMODE_QIO=y
      CONFIG_ESPTOOLPY_FLASHFREQ_80M=y

      # LWIP
      CONFIG_LWIP_TCP_SND_BUF_DEFAULT=65534
      CONFIG_LWIP_TCP_WND_DEFAULT=65534
      CONFIG_LWIP_TCP_RECVMBOX_SIZE=12
      CONFIG_LWIP_UDP_RECVMBOX_SIZE=12
      CONFIG_LWIP_TCPIP_RECVMBOX_SIZE=64

      # Wi-Fi
      CONFIG_ESP32_WIFI_STATIC_RX_BUFFER_NUM=16
      CONFIG_ESP32_WIFI_DYNAMIC_RX_BUFFER_NUM=64
      CONFIG_ESP32_WIFI_DYNAMIC_TX_BUFFER_NUM=64
      CONFIG_ESP32_WIFI_TX_BA_WIN=32
      CONFIG_ESP32_WIFI_RX_BA_WIN=32
      CONFIG_ESP32_WIFI_AMPDU_TX_ENABLED=y
      CONFIG_ESP32_WIFI_AMPDU_RX_ENABLED=y

  .. only:: esp32c2

    ::

      # System
      CONFIG_ESP_SYSTEM_EVENT_TASK_STACK_SIZE=4096
      CONFIG_FREERTOS_UNICORE=n
      CONFIG_FREERTOS_HZ=1000
      CONFIG_ESP_DEFAULT_CPU_FREQ_MHZ_120=y
      CONFIG_ESP_DEFAULT_CPU_FREQ_MHZ=120
      CONFIG_ESPTOOLPY_FLASHMODE_QIO=y
      CONFIG_ESPTOOLPY_FLASHFREQ_60M=y

      # LWIP
      CONFIG_LWIP_TCP_SND_BUF_DEFAULT=65534
      CONFIG_LWIP_TCP_WND_DEFAULT=65534
      CONFIG_LWIP_TCP_RECVMBOX_SIZE=12
      CONFIG_LWIP_UDP_RECVMBOX_SIZE=12
      CONFIG_LWIP_TCPIP_RECVMBOX_SIZE=64

      # Wi-Fi
      CONFIG_ESP32_WIFI_STATIC_RX_BUFFER_NUM=16
      CONFIG_ESP32_WIFI_DYNAMIC_RX_BUFFER_NUM=64
      CONFIG_ESP32_WIFI_DYNAMIC_TX_BUFFER_NUM=64
      CONFIG_ESP32_WIFI_TX_BA_WIN=32
      CONFIG_ESP32_WIFI_RX_BA_WIN=32
      CONFIG_ESP32_WIFI_AMPDU_TX_ENABLED=y
      CONFIG_ESP32_WIFI_AMPDU_RX_ENABLED=y

  .. only:: esp32c3 or esp32s2

    ::

      # System
      CONFIG_ESP_SYSTEM_EVENT_TASK_STACK_SIZE=4096
      CONFIG_FREERTOS_UNICORE=n
      CONFIG_FREERTOS_HZ=1000
      CONFIG_ESP_DEFAULT_CPU_FREQ_160=y
      CONFIG_ESP_DEFAULT_CPU_FREQ_MHZ=160
      CONFIG_ESPTOOLPY_FLASHMODE_QIO=y
      CONFIG_ESPTOOLPY_FLASHFREQ_80M=y

      # LWIP
      CONFIG_LWIP_TCP_SND_BUF_DEFAULT=65534
      CONFIG_LWIP_TCP_WND_DEFAULT=65534
      CONFIG_LWIP_TCP_RECVMBOX_SIZE=12
      CONFIG_LWIP_UDP_RECVMBOX_SIZE=12
      CONFIG_LWIP_TCPIP_RECVMBOX_SIZE=64

      # Wi-Fi
      CONFIG_ESP32_WIFI_STATIC_RX_BUFFER_NUM=16
      CONFIG_ESP32_WIFI_DYNAMIC_RX_BUFFER_NUM=64
      CONFIG_ESP32_WIFI_DYNAMIC_TX_BUFFER_NUM=64
      CONFIG_ESP32_WIFI_TX_BA_WIN=32
      CONFIG_ESP32_WIFI_RX_BA_WIN=32
      CONFIG_ESP32_WIFI_AMPDU_TX_ENABLED=y
      CONFIG_ESP32_WIFI_AMPDU_RX_ENABLED=y

  .. only:: esp32c5 or esp32c61

    ::

      # System
      CONFIG_ESP_SYSTEM_EVENT_TASK_STACK_SIZE=4096
      CONFIG_FREERTOS_UNICORE=n
      CONFIG_FREERTOS_HZ=1000
      CONFIG_ESP_DEFAULT_CPU_FREQ_240=y
      CONFIG_ESP_DEFAULT_CPU_FREQ_MHZ=240
      CONFIG_ESPTOOLPY_FLASHMODE_QIO=y
      CONFIG_ESPTOOLPY_FLASHFREQ_80M=y

      # LWIP
      CONFIG_LWIP_TCP_SND_BUF_DEFAULT=65534
      CONFIG_LWIP_TCP_WND_DEFAULT=65534
      CONFIG_LWIP_TCP_RECVMBOX_SIZE=12
      CONFIG_LWIP_UDP_RECVMBOX_SIZE=12
      CONFIG_LWIP_TCPIP_RECVMBOX_SIZE=64

      # Wi-Fi
      CONFIG_ESP_WIFI_STATIC_RX_BUFFER_NUM=16
      CONFIG_ESP_WIFI_DYNAMIC_RX_BUFFER_NUM=64
      CONFIG_ESP_WIFI_DYNAMIC_TX_BUFFER_NUM=64
      CONFIG_ESP_WIFI_TX_BA_WIN=32
      CONFIG_ESP_WIFI_RX_BA_WIN=32
      CONFIG_ESP_WIFI_AMPDU_TX_ENABLED=y
      CONFIG_ESP_WIFI_AMPDU_RX_ENABLED=y

  .. only:: esp32c6

    ::

      # System
      CONFIG_ESP_SYSTEM_EVENT_TASK_STACK_SIZE=4096
      CONFIG_FREERTOS_UNICORE=n
      CONFIG_FREERTOS_HZ=1000
      CONFIG_ESP_DEFAULT_CPU_FREQ_160=y
      CONFIG_ESP_DEFAULT_CPU_FREQ_MHZ=160
      CONFIG_ESPTOOLPY_FLASHMODE_QIO=y
      CONFIG_ESPTOOLPY_FLASHFREQ_80M=y

      # LWIP
      CONFIG_LWIP_TCP_SND_BUF_DEFAULT=65534
      CONFIG_LWIP_TCP_WND_DEFAULT=65534
      CONFIG_LWIP_TCP_RECVMBOX_SIZE=12
      CONFIG_LWIP_UDP_RECVMBOX_SIZE=12
      CONFIG_LWIP_TCPIP_RECVMBOX_SIZE=64

      # Wi-Fi
      CONFIG_ESP_WIFI_STATIC_RX_BUFFER_NUM=16
      CONFIG_ESP_WIFI_DYNAMIC_RX_BUFFER_NUM=64
      CONFIG_ESP_WIFI_DYNAMIC_TX_BUFFER_NUM=64
      CONFIG_ESP_WIFI_TX_BA_WIN=32
      CONFIG_ESP_WIFI_RX_BA_WIN=32
      CONFIG_ESP_WIFI_AMPDU_TX_ENABLED=y
      CONFIG_ESP_WIFI_AMPDU_RX_ENABLED=y

**2. 提高 UART 缓冲区大小**

  将下面代码段拷贝并替换 :project_file:`at_uart_task.c <main/interface/uart/at_uart_task.c>` 文件中 `uart_driver_install()` 行。

  ::

    uart_driver_install(g_at_cmd_port, 1024 * 16, 1024 * 16, 100, &s_at_uart_queue, 0);

**3. 删除默认配置、重新编译固件、烧录运行**

  ::

    rm -rf build sdkconfig
    ./build.py build
    ./build.py flash monitor

**4. 透传前提高 UART 波特率**

  典型 AT 命令序列如下：

  ::

    AT+CWMODE=1
    AT+CWJAP="ssid","password"
    AT+UART_CUR=3000000,8,1,0,3
    AT+CIPSTART="TCP","192.168.105.13",3344
    AT+CIPMODE=1
    AT+CIPSEND
    // 传输数据

此快速配置的方法在一定程度上可以提高吞吐，但有时可能不能达到用户的预期。另外有些配置可能不是吞吐的瓶颈，配置较高可能会牺牲内存资源或功耗等。因此，用户也可以熟悉下面推荐的方法，进行有针对性地配置。

（推荐）熟悉数据流、针对性地配置
------------------------------------------------------

影响 ESP-AT 吞吐的因素大体描述如下图：

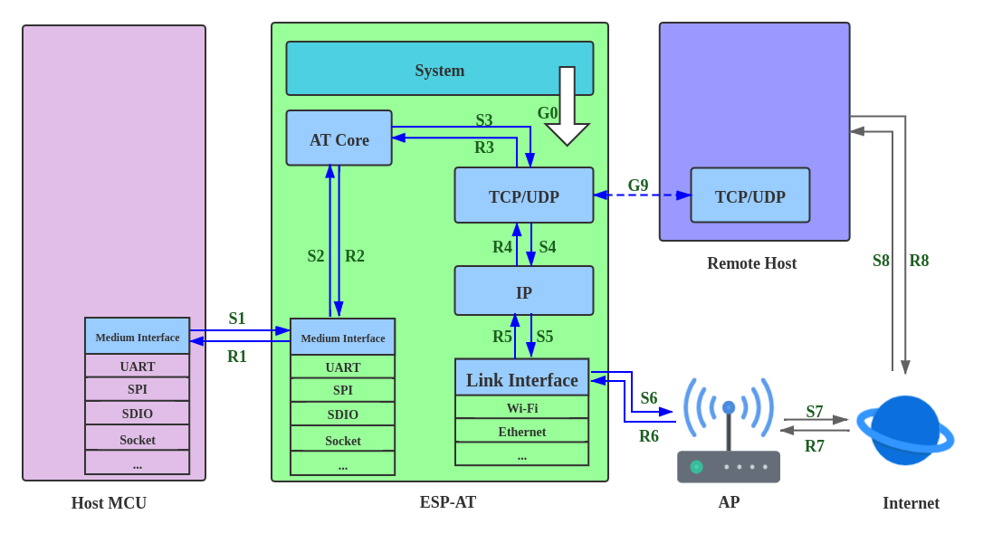
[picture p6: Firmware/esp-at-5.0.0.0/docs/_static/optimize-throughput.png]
吞吐数据流


   吞吐数据流

如图中箭头所示：

- ESP-AT 发送 (TX) 的数据流为 S1 -> S2 -> S3 -> S4 -> S5 -> S6 -> S7 -> S8
- ESP-AT 接收 (RX) 的数据流为 R8 -> R7 -> R6 -> R5 -> R4 -> R3 -> R2 -> R1

吞吐的数据流类似于水流，要想提高吞吐，需要考虑在数据流速较低的节点之间进行优化，而不需要在数据流速本就达到预期的节点之间进行额外的配置，以免造成不必要的资源浪费。在实际产品中，往往只需要提高其中一条数据流吞吐即可，用户需要根据下面指导进行对应的配置即可。

.. note::

  下面的配置均以可用内存充足为前提的，用户可以通过 :ref:`AT+SYSRAM <cmd-SYSRAM>` 命令来查询可用内存。

**1. G0 吞吐优化**

  G0 是系统可以优化的部分，建议参考配置如下：

  .. only:: esp32

    ::
      
      CONFIG_ESP_SYSTEM_EVENT_TASK_STACK_SIZE=4096
      CONFIG_FREERTOS_UNICORE=n
      CONFIG_FREERTOS_HZ=1000
      CONFIG_ESP_DEFAULT_CPU_FREQ_240=y
      CONFIG_ESP_DEFAULT_CPU_FREQ_MHZ=240
      CONFIG_ESPTOOLPY_FLASHMODE_QIO=y
      CONFIG_ESPTOOLPY_FLASHFREQ_80M=y

  .. only:: esp32c2

    ::
      
      CONFIG_ESP_SYSTEM_EVENT_TASK_STACK_SIZE=4096
      CONFIG_FREERTOS_UNICORE=n
      CONFIG_FREERTOS_HZ=1000
      CONFIG_ESP_DEFAULT_CPU_FREQ_MHZ_120=y
      CONFIG_ESP_DEFAULT_CPU_FREQ_MHZ=120
      CONFIG_ESPTOOLPY_FLASHMODE_QIO=y
      CONFIG_ESPTOOLPY_FLASHFREQ_60M=y

  .. only:: esp32c5

    ::
      
      CONFIG_ESP_SYSTEM_EVENT_TASK_STACK_SIZE=4096
      CONFIG_FREERTOS_UNICORE=n
      CONFIG_FREERTOS_HZ=1000
      CONFIG_ESP_DEFAULT_CPU_FREQ_240=y
      CONFIG_ESP_DEFAULT_CPU_FREQ_MHZ=240
      CONFIG_ESPTOOLPY_FLASHMODE_QIO=y
      CONFIG_ESPTOOLPY_FLASHFREQ_80M=y

  .. only:: esp32c3 or esp32c6 or esp32c61

    ::
      
      CONFIG_ESP_SYSTEM_EVENT_TASK_STACK_SIZE=4096
      CONFIG_FREERTOS_UNICORE=n
      CONFIG_FREERTOS_HZ=1000
      CONFIG_ESP_DEFAULT_CPU_FREQ_160=y
      CONFIG_ESP_DEFAULT_CPU_FREQ_MHZ=160
      CONFIG_ESPTOOLPY_FLASHMODE_QIO=y
      CONFIG_ESPTOOLPY_FLASHFREQ_80M=y

**2. S1、R1 吞吐优化**

  通常情况下，S1 和 R1 是 ESP-AT 吞吐高低的关键。因为默认情况下，ESP-AT 和主机之间使用 UART 进行通信，波特率为 115200，而 UART 硬件上，速率上限为 5 Mbps。因此，用户使用场景吞吐低于 5 Mbps，可以使用默认的 UART 作为和主机之间的通信介质，同时可以进行下面优化。

2.1 提高 UART 缓冲区大小

  将下面代码段拷贝并替换 :project_file:`at_uart_task.c <main/interface/uart/at_uart_task.c>` 文件中 `uart_driver_install()` 行。

  - 提高 UART TX 吞吐

    ::

      uart_driver_install(g_at_cmd_port, 1024 * 16, 8192, 100, &s_at_uart_queue, 0);

  - 提高 UART RX 吞吐

    ::

      uart_driver_install(g_at_cmd_port, 2048, 1024 * 16, 100, &s_at_uart_queue, 0);

  - 提高 UART TX 和 RX 吞吐

    ::

      uart_driver_install(g_at_cmd_port, 1024 * 16, 1024 * 16, 100, &s_at_uart_queue, 0);

2.2 透传前提高 UART 波特率

  典型 AT 命令序列如下：

  ::

    AT+CWMODE=1
    AT+CWJAP="ssid","password"
    AT+UART_CUR=3000000,8,1,0,3
    AT+CIPSTART="TCP","192.168.105.13",3344
    AT+CIPMODE=1
    AT+CIPSEND
    // 传输数据

.. note::
  用户需要确保主机的 UART 可以支持到这么高的速率，并且主机和 ESP-AT 之间的 UART 连线尽可能地短。

.. note::

    如果用户期望吞吐速率大于或接近于 5 Mbps，可以考虑使用 SPI、SDIO、Socket 等方式。具体请参考：

    .. list::

      :esp32 or esp32c5 or esp32c6 or esp32c61: - SDIO：:doc:`SDIO AT 指南 </Compile_and_Develop/How_to_implement_SDIO_AT>`
      :esp32c2 or esp32c3 or esp32c5 or esp32c6 or esp32c61: - SPI：:doc:`SPI AT 指南 </Compile_and_Develop/How_to_implement_SPI_AT>`
      - Socket：:project_file:`Socket AT 指南 <main/interface/socket/README.md>`

**3. S2、R2、R3、S3 吞吐优化**

  通常情况下，S2、R2、R3、S3 不是 ESP-AT 吞吐高低的瓶颈。因为 AT core 在 UART 缓冲区和通信协议的传输层之间传递数据，仅有极少的且不耗时的应用逻辑，无需优化。

**4. S4、R4、S5、R5、S6、R6 吞吐优化**

  ESP-AT 和主机之间使用 UART 进行通信，S4、R4、S5、R5、S6、R6 无需优化。ESP-AT 和主机之间使用其他传输介质进行通信时，S4、R4、S5、R5、S6、R6 是影响吞吐的一个因素。

  S4、R4、S5、R5、S6、R6 是通信协议的传输层、网络层、和数据链路层之间的数据流。用户需要阅读 ESP-IDF 中 `如何提高 Wi-Fi 性能 <https://docs.espressif.com/projects/esp-idf/zh_CN/latest/{IDF_TARGET_PATH_NAME}/api-guides/wifi.html#how-to-improve-wi-fi-performance>`_ 文档，了解原理，进行合理配置。这些配置均可以在 ``./build.py menuconfig`` 里进行配置。

  - 优化 S4 -> S5 -> S6：`发送数据方向配置 <https://docs.espressif.com/projects/esp-idf/zh_CN/latest/{IDF_TARGET_PATH_NAME}/api-guides/wifi.html#id64>`_
  - 优化 R6 -> R5 -> R4：`接收数据方向配置 <https://docs.espressif.com/projects/esp-idf/zh_CN/latest/{IDF_TARGET_PATH_NAME}/api-guides/wifi.html#id64>`_

**5. S6、R6 吞吐优化**

  S6 和 R6 是通信协议的数据链路层，{IDF_TARGET_NAME} 可以使用 Wi-Fi 或者以太网作为传输介质。Wi-Fi 除了上述介绍的优化方法之外，可能还需要用户关心：

  - 提高 RF 发射功率

    默认发射功率通常不是吞吐高低的瓶颈，用户也可以通过 :ref:`AT+RFPOWER <cmd-RFPOWER>` 命令查询和设置 RF 发射功率。

  - 设置 802.11 b/g/n 协议

    默认 Wi-Fi 模式即为 802.11 b/g/n 协议，用户可通过 :ref:`AT+CWSTAPROTO <cmd-STAPROTO>` 命令查询和设置 802.11 b/g/n 协议。配置是双向的，因此建议 AP 端 Wi-Fi 模式配置为 802.11 b/g/n 协议，频宽配置为 HT20/HT40 (20/40 MHz) 模式。

**6. S7、R7、S8、R8 吞吐优化**

  通常情况下，S7、R7、S8、R8 不是 ESP-AT 吞吐优化的范围。因为这和实际网络带宽、网络路由、物理距离等有关。

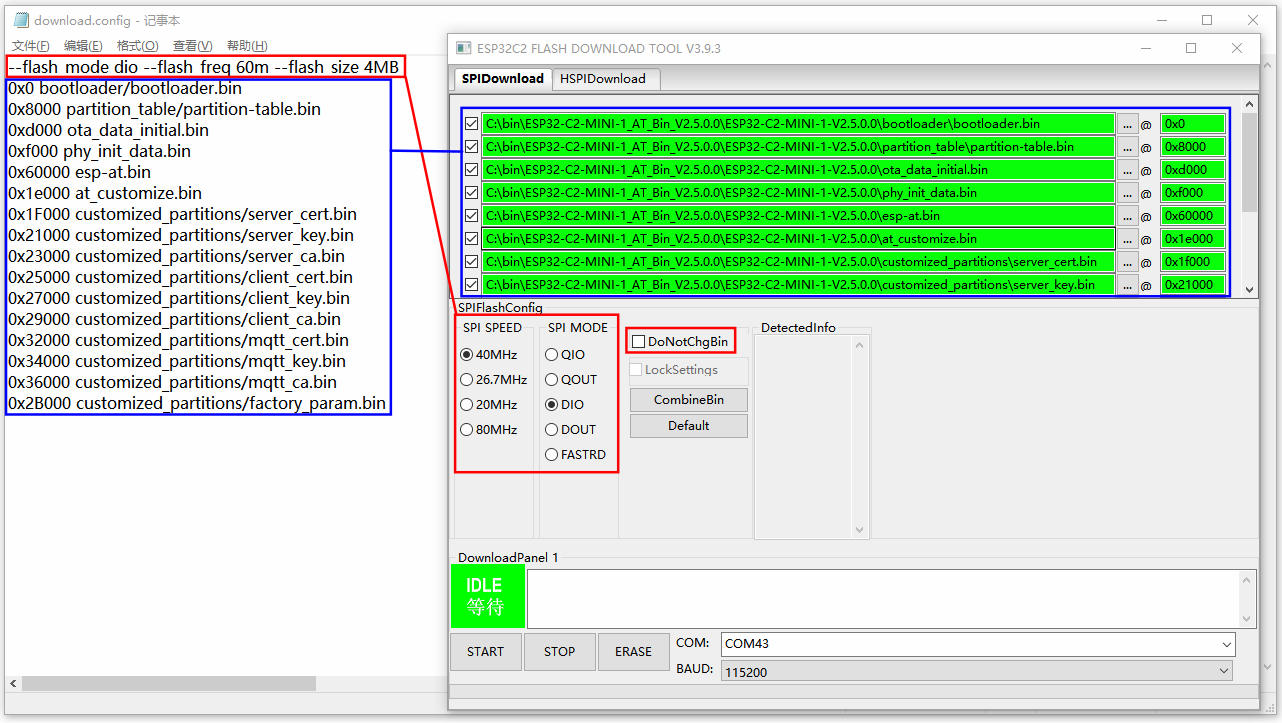
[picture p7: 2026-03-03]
Firmware/esp-at-5.0.0.0/docs/_static/get_started/download_guide/download_multi_bin_esp32c2.png

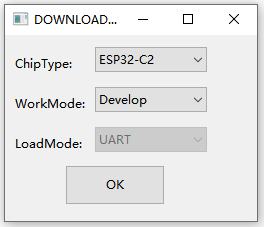
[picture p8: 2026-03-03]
Firmware/esp-at-5.0.0.0/docs/_static/get_started/download_guide/download_tool_esp32c2.png

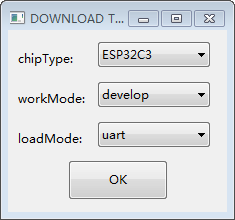
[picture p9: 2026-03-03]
Firmware/esp-at-5.0.0.0/docs/_static/get_started/download_guide/download_tool_esp32c3.png

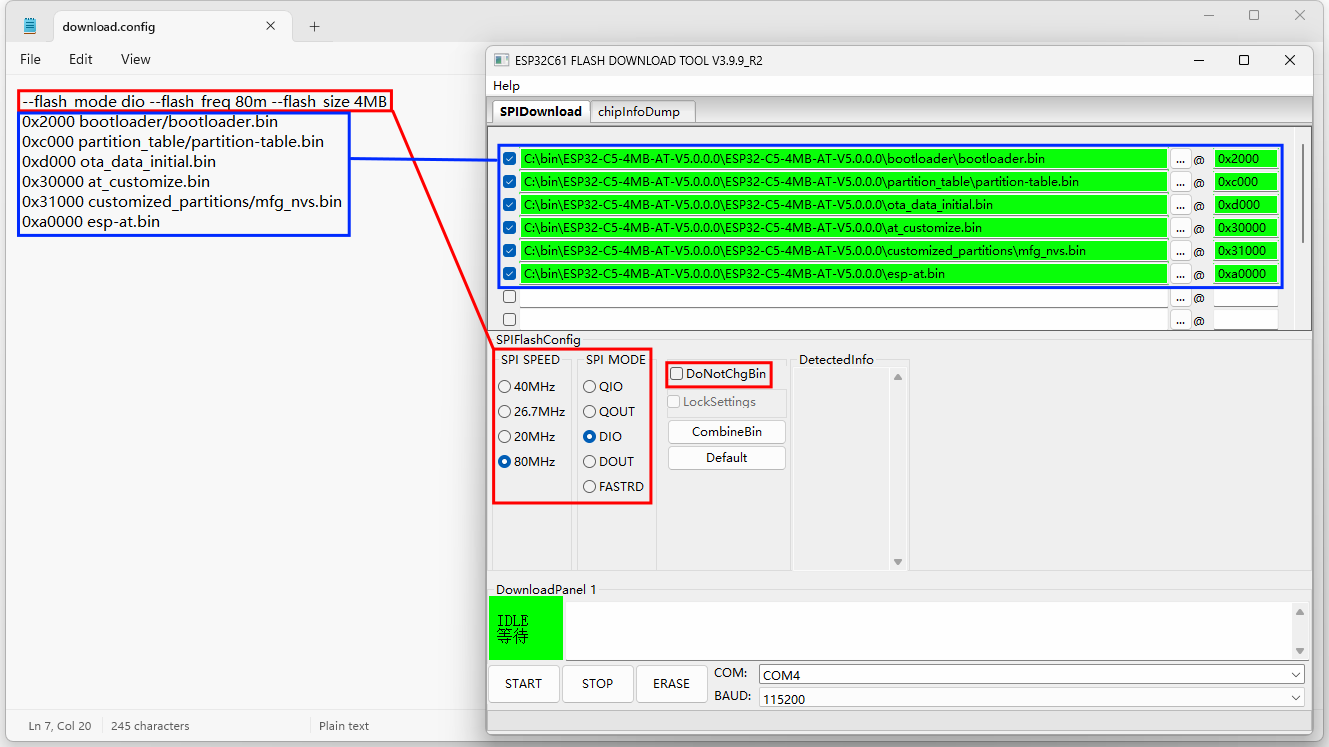
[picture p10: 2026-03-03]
Firmware/esp-at-5.0.0.0/docs/_static/get_started/download_guide/download_multi_bin_esp32c5.png

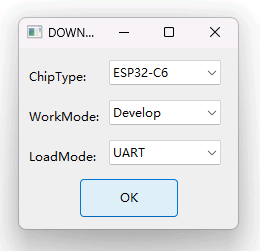
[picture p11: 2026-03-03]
Firmware/esp-at-5.0.0.0/docs/_static/get_started/download_guide/download_tool_esp32c6.png

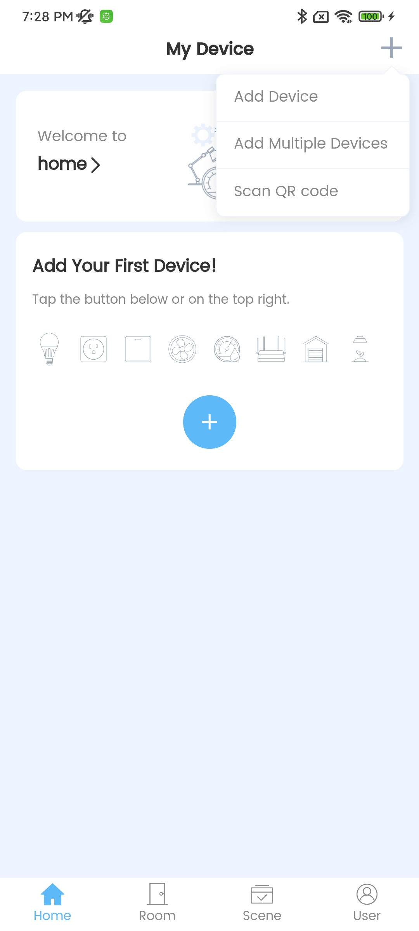
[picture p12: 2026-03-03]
Firmware/esp-at-5.0.0.0/docs/_static/RainMaker/nova_add_device.png

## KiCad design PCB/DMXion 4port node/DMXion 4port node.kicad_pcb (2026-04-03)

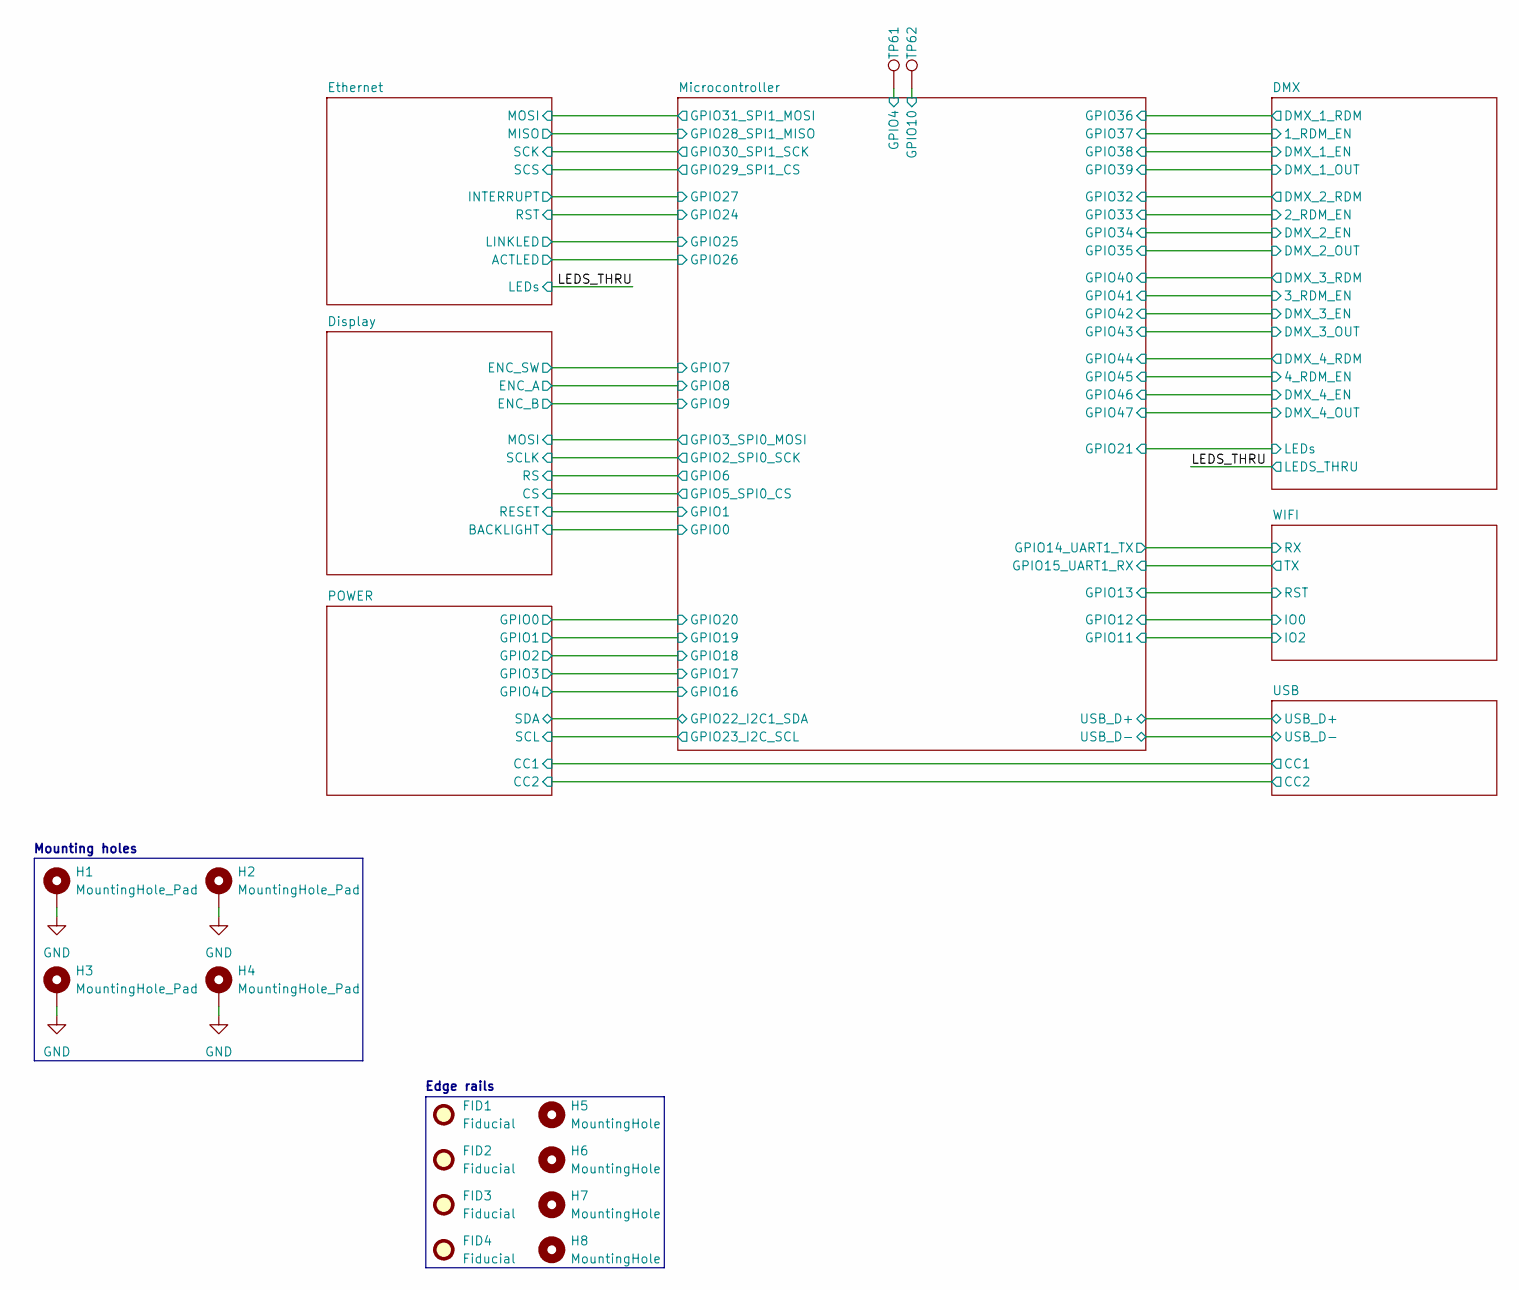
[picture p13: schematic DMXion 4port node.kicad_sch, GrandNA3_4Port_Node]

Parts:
FID1, FID2, FID3, FID4: Fiducial; Fiducial_1mm_Mask2mm
H1, H2, H3, H4: MountingHole_Pad; MountingHole_3.2mm_M3_Pad
H5, H6, H7, H8: MountingHole; MountingHole_2mm
TP61, TP62: TestPoint; TestPoint_Pad_D1.5mm

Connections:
/Microcontroller/GPIO4: TP61.1 (1_1); also elsewhere on the board
/Microcontroller/GPIO10: TP62.1 (1_1); also elsewhere on the board
GND: H1.1 (1_1), H2.1 (1_1), H3.1 (1_1), H4.1 (1_1); also elsewhere on the board

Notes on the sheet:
Edge rails
Mounting holes

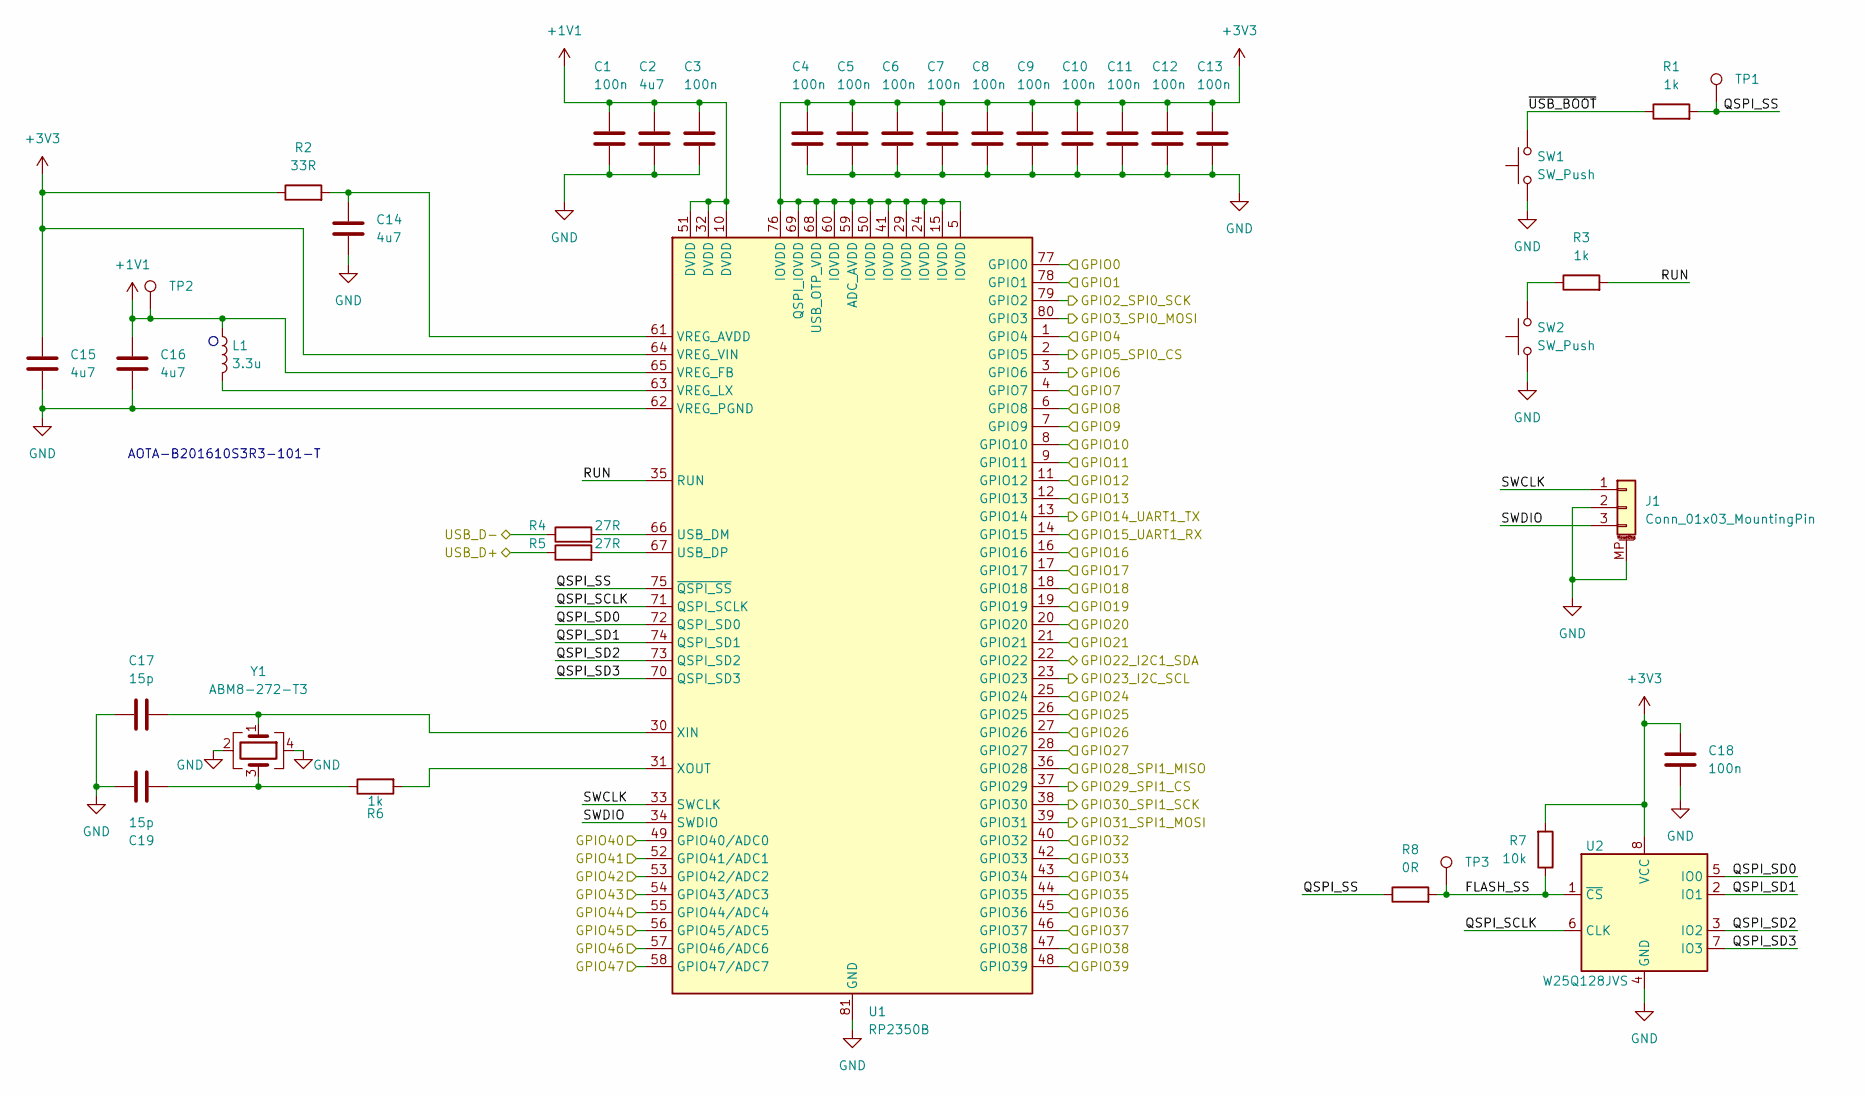
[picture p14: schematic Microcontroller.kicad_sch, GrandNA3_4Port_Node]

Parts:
C1, C3, C4, C5, C6, C7, C8, C9, C10, C11, C12, C13: 100n; C_0402_1005Metric
C2, C14: 4u7; C_0402_1005Metric
C15, C16: 4u7; C_0402_1005Metric_small_pads
C17, C19: 15p; C_0402_1005Metric
C18: 100n; C_0603_1608Metric
J1: Conn_01x03_MountingPin; JST_SH_SM03B-SRSS-TB_1x03-1MP_P1.00mm_Horizontal
L1: 3.3u; L_pol_2016
R1, R3: 1k; R_0603_1608Metric
R2: 33R; R_0402_1005Metric
R4, R5: 27R; R_0402_1005Metric
R6: 1k; R_0402_1005Metric
R7: 10k; R_0603_1608Metric
R8: 0R; R_0603_1608Metric
SW1, SW2: SW_Push; SW_SPST_B3U-1000P
TP1, TP2, TP3: TestPoint; TestPoint_Pad_D1.5mm
U1: RP2350B; RP2350-QFN-80-1EP_10x10_P0.4mm_EP3.4x3.4mm_ThermalVias
U2: W25Q128JVS; SOIC-8_5.3x5.3mm_P1.27mm
Y1: ABM8-272-T3; Crystal_SMD_3225-4Pin_3.2x2.5mm

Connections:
+1V1: C1.1, C2.1, C3.1, C16.1, L1.1, TP2.1 (1_1), U1.10 (DVDD), U1.32 (DVDD), U1.51 (DVDD), U1.65 (VREG_FB)
+3V3: C4.1, C5.1, C6.1, C7.1, C8.1, C9.1, C10.1, C11.1, C12.1, C13.1, C15.1, C18.1, R2.1, R7.2, U1.5 (IOVDD), U1.15 (IOVDD), U1.24 (IOVDD), U1.29 (IOVDD), U1.41 (IOVDD), U1.50 (IOVDD), U1.59 (ADC_AVDD), U1.60 (IOVDD), U1.64 (VREG_VIN), U1.68 (USB_OTP_VDD), U1.69 (QSPI_IOVDD), U1.76 (IOVDD), U2.8 (VCC); also elsewhere on the board
/DMX/1_RDM_EN: U1.46 (GPIO37); also elsewhere on the board
/DMX/2_RDM_EN: U1.42 (GPIO33); also elsewhere on the board
/DMX/3_RDM_EN: U1.52 (GPIO41/ADC1); also elsewhere on the board
/DMX/4_RDM_EN: U1.56 (GPIO45/ADC5); also elsewhere on the board
/DMX/DMX_1_EN: U1.47 (GPIO38); also elsewhere on the board
/DMX/DMX_1_OUT: U1.48 (GPIO39); also elsewhere on the board
/DMX/DMX_1_RDM: U1.45 (GPIO36); also elsewhere on the board
/DMX/DMX_2_EN: U1.43 (GPIO34); also elsewhere on the board
/DMX/DMX_2_OUT: U1.44 (GPIO35); also elsewhere on the board
/DMX/DMX_2_RDM: U1.40 (GPIO32); also elsewhere on the board
/DMX/DMX_3_EN: U1.53 (GPIO42/ADC2); also elsewhere on the board
/DMX/DMX_3_OUT: U1.54 (GPIO43/ADC3); also elsewhere on the board
/DMX/DMX_3_RDM: U1.49 (GPIO40/ADC0); also elsewhere on the board
/DMX/DMX_4_EN: U1.57 (GPIO46/ADC6); also elsewhere on the board
/DMX/DMX_4_OUT: U1.58 (GPIO47/ADC7); also elsewhere on the board
/DMX/DMX_4_RDM: U1.55 (GPIO44/ADC4); also elsewhere on the board
/DMX/LEDs: U1.21 (GPIO21); also elsewhere on the board
/Display/BACKLIGHT: U1.77 (GPIO0); also elsewhere on the board
/Display/CS: U1.2 (GPIO5); also elsewhere on the board
/Display/ENC_A: U1.6 (GPIO8); also elsewhere on the board
/Display/ENC_B: U1.7 (GPIO9); also elsewhere on the board
/Display/ENC_SW: U1.4 (GPIO7); also elsewhere on the board
/Display/MOSI: U1.80 (GPIO3); also elsewhere on the board
/Display/RESET: U1.78 (GPIO1); also elsewhere on the board
/Display/RS: U1.3 (GPIO6); also elsewhere on the board
/Display/SCLK: U1.79 (GPIO2); also elsewhere on the board
/Ethernet/ACTLED: U1.27 (GPIO26); also elsewhere on the board
/Ethernet/INTERRUPT: U1.28 (GPIO27); also elsewhere on the board
/Ethernet/LINKLED: U1.26 (GPIO25); also elsewhere on the board
/Ethernet/MISO: U1.36 (GPIO28); also elsewhere on the board
/Ethernet/MOSI: U1.39 (GPIO31); also elsewhere on the board
/Ethernet/RST: U1.25 (GPIO24); also elsewhere on the board
/Ethernet/SCK: U1.38 (GPIO30); also elsewhere on the board
/Ethernet/SCS: U1.37 (GPIO29); also elsewhere on the board
/Microcontroller/FLASH_SS: R7.1, R8.2, TP3.1 (1_1), U2.1 (~CS)
/Microcontroller/GPIO4: U1.1 (GPIO4); also elsewhere on the board
/Microcontroller/GPIO10: U1.8 (GPIO10); also elsewhere on the board
/Microcontroller/GPIO11: U1.9 (GPIO11); also elsewhere on the board
/Microcontroller/GPIO12: U1.11 (GPIO12); also elsewhere on the board
/Microcontroller/GPIO13: U1.12 (GPIO13); also elsewhere on the board
/Microcontroller/GPIO14_UART1_TX: U1.13 (GPIO14); also elsewhere on the board
/Microcontroller/GPIO15_UART1_RX: U1.14 (GPIO15); also elsewhere on the board
/Microcontroller/GPIO16: U1.16 (GPIO16); also elsewhere on the board
/Microcontroller/GPIO17: U1.17 (GPIO17); also elsewhere on the board
/Microcontroller/GPIO18: U1.18 (GPIO18); also elsewhere on the board
/Microcontroller/GPIO19: U1.19 (GPIO19); also elsewhere on the board
/Microcontroller/GPIO20: U1.20 (GPIO20); also elsewhere on the board
/Microcontroller/GPIO22_I2C1_SDA: U1.22 (GPIO22); also elsewhere on the board
/Microcontroller/GPIO23_I2C_SCL: U1.23 (GPIO23); also elsewhere on the board
/Microcontroller/QSPI_SCLK: U1.71 (QSPI_SCLK), U2.6 (CLK)
/Microcontroller/QSPI_SD0: U1.72 (QSPI_SD0), U2.5 (IO0)
/Microcontroller/QSPI_SD1: U1.74 (QSPI_SD1), U2.2 (IO1)
/Microcontroller/QSPI_SD2: U1.73 (QSPI_SD2), U2.3 (IO2)
/Microcontroller/QSPI_SD3: U1.70 (QSPI_SD3), U2.7 (IO3)
/Microcontroller/QSPI_SS: R1.2, R8.1, TP1.1 (1_1), U1.75 (~QSPI_SS)
/Microcontroller/RUN: R3.2, U1.35 (RUN)
/Microcontroller/SWCLK: J1.1, U1.33 (SWCLK)
/Microcontroller/SWDIO: J1.3, U1.34 (SWDIO)
/Microcontroller/~USB_BOOT: R1.1, SW1.2
/USB/USB_D+: R5.1; also elsewhere on the board
/USB/USB_D-: R4.1; also elsewhere on the board
GND: C1.2, C2.2, C3.2, C4.2, C5.2, C6.2, C7.2, C8.2, C9.2, C10.2, C11.2, C12.2, C13.2, C14.2, C15.2, C16.2, C17.1, C18.2, C19.1, J1.2, J1.MP (MountPin), SW1.1, SW2.1, U1.62 (VREG_PGND), U1.81 (GND), U2.4 (GND), Y1.2 (G), Y1.4 (G); also elsewhere on the board
unnamed: C19.2, R6.1, Y1.3
unnamed: R3.1, SW2.2
unnamed: R4.2, U1.66 (USB_DM)
unnamed: R5.2, U1.67 (USB_DP)
unnamed: C14.1, R2.2, U1.61 (VREG_AVDD)
unnamed: L1.2, U1.63 (VREG_LX)
unnamed: C17.2, U1.30 (XIN), Y1.1
unnamed: R6.2, U1.31 (XOUT)

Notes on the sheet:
AOTA-B201610S3R3-101-T

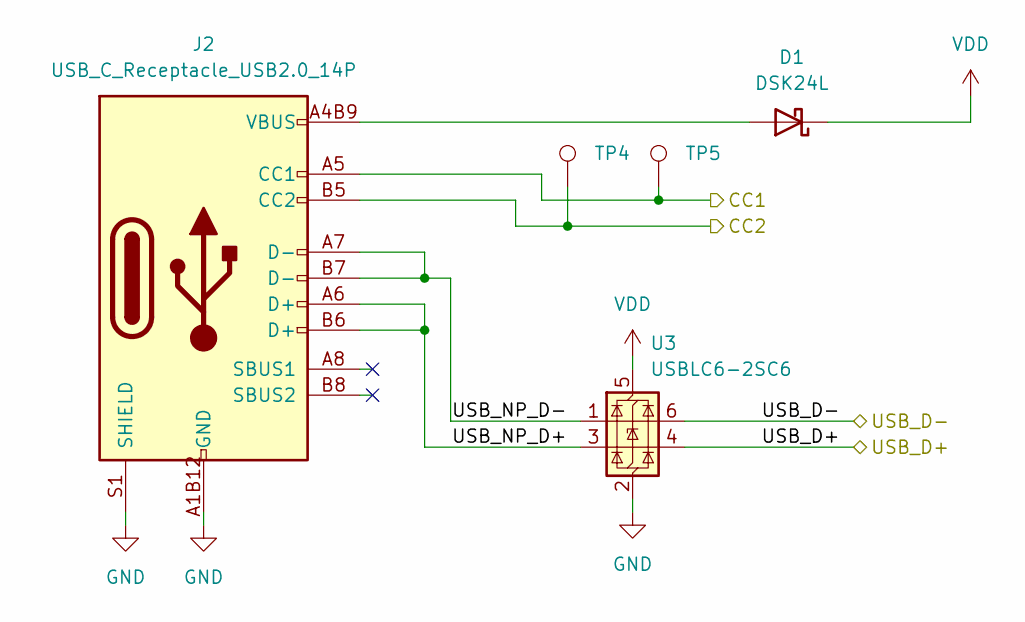
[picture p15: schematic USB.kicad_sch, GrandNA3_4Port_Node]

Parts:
D1: DSK24L; D_SOD-123F
J2: USB_C_Receptacle_USB2.0_14P; USB-C_SMD-TYPE-C-31-M-12_1
TP4, TP5: TestPoint; TestPoint_Pad_D1.5mm
U3: USBLC6-2SC6; SOT-23-6

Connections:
/POWER/CC1: J2.A5 (CC1), TP5.1 (1_1); also elsewhere on the board
/POWER/CC2: J2.B5 (CC2), TP4.1 (1_1); also elsewhere on the board
/USB/USB_D+: U3.4 (I/O2); also elsewhere on the board
/USB/USB_D-: U3.6 (I/O1); also elsewhere on the board
/USB/USB_NP_D+: J2.A6 (D+), J2.B6 (D+), U3.3 (I/O2)
/USB/USB_NP_D-: J2.A7 (D-), J2.B7 (D-), U3.1 (I/O1)
GND: J2.A1B12 (GND), J2.B1A12 (GND), J2.S1 (SHIELD), U3.2 (GND); also elsewhere on the board
unnamed: D1.2 (A), J2.A4B9 (VBUS), J2.B4A9 (VBUS)
VDD: D1.1 (K), U3.5 (VBUS); also elsewhere on the board

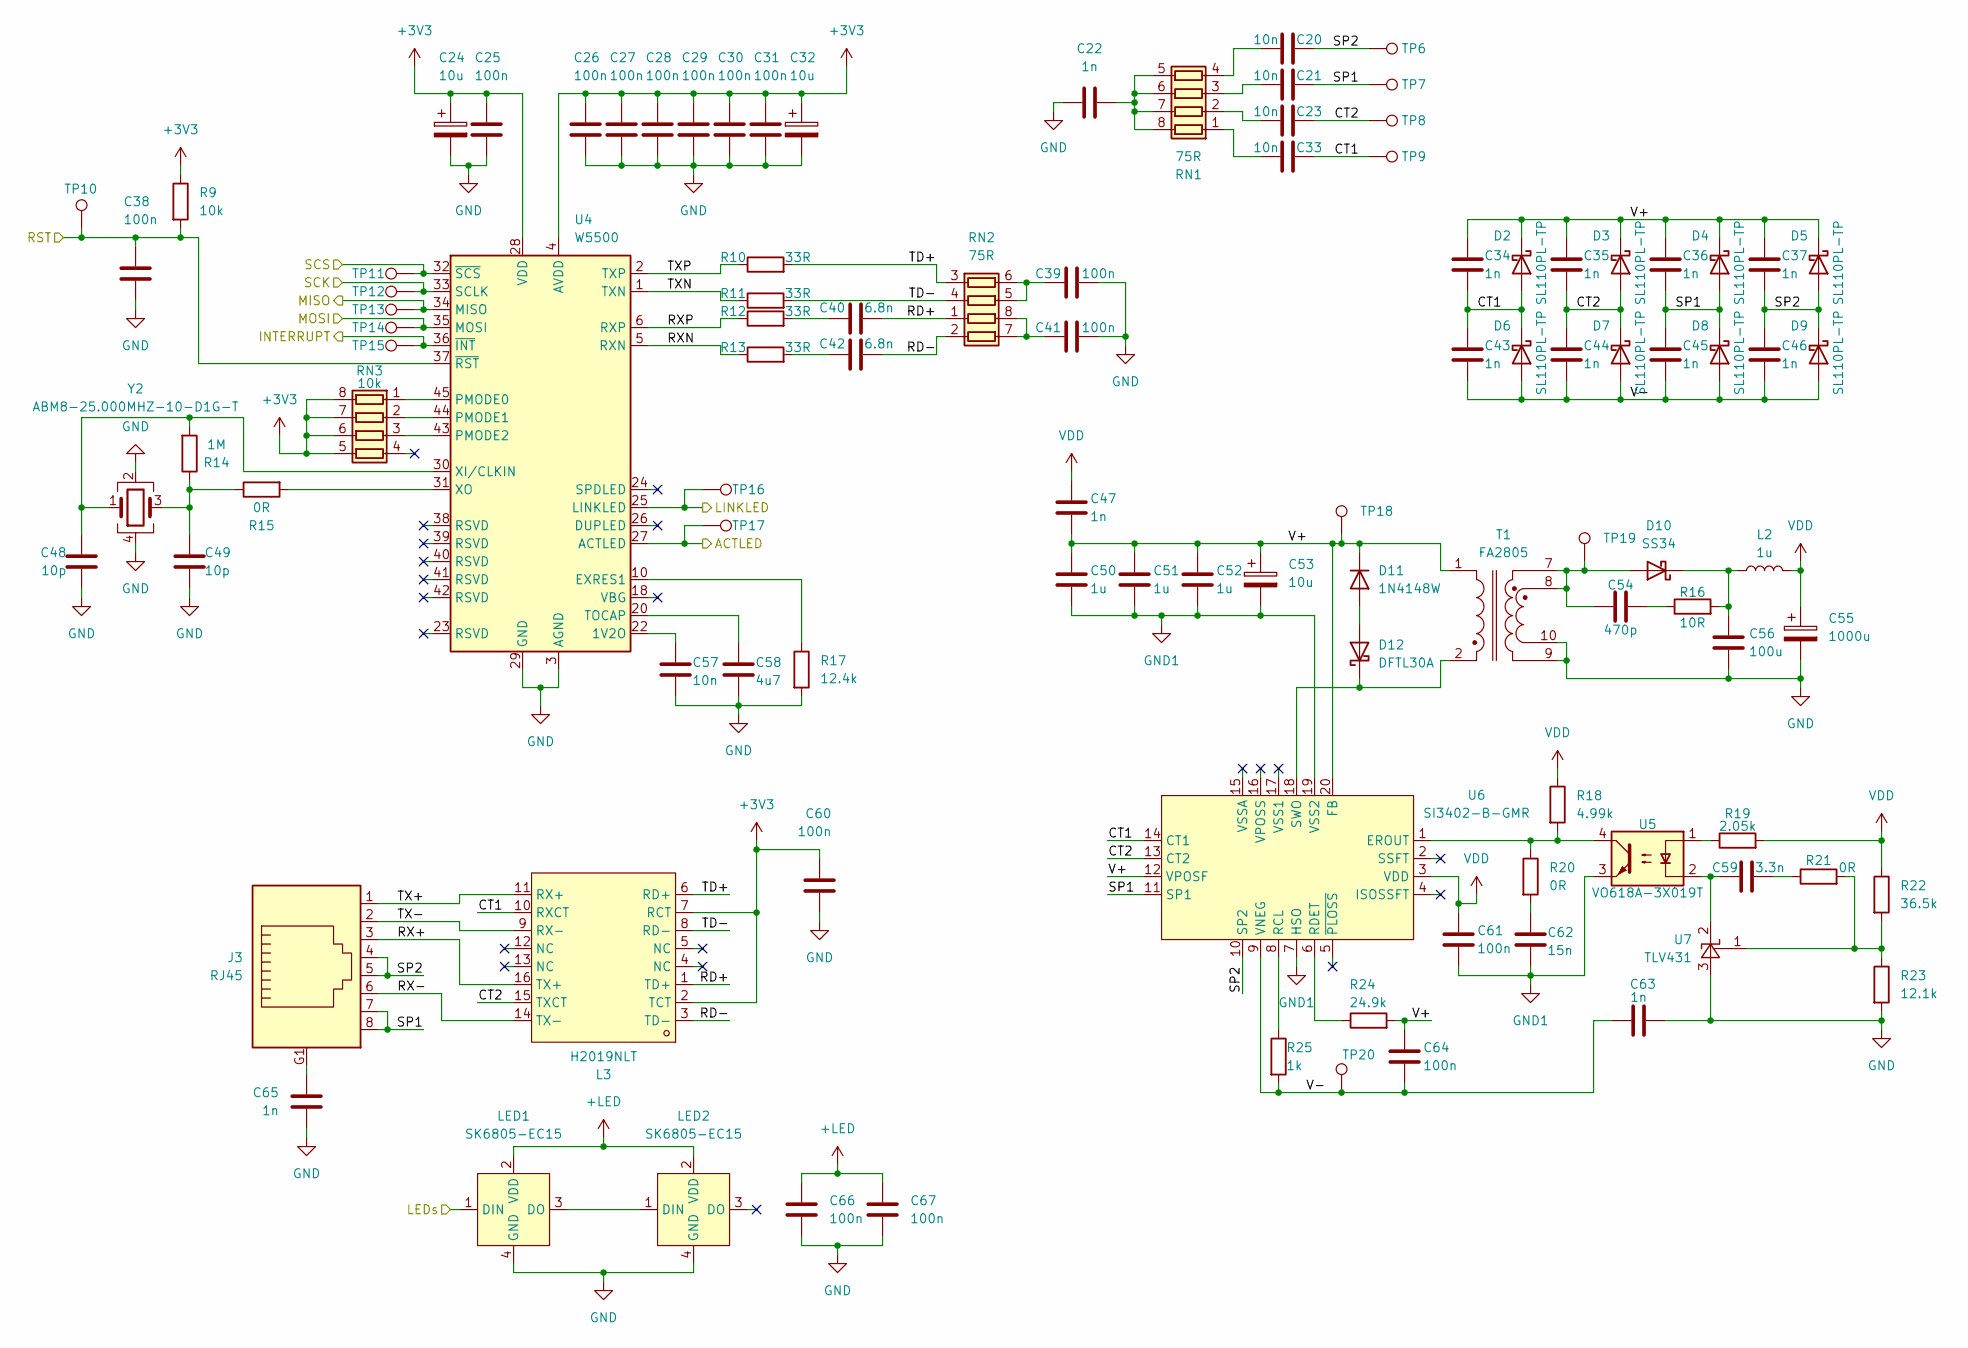
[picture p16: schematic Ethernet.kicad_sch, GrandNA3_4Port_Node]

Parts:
C20, C21, C23, C33, C57: 10n; C_0603_1608Metric
C22, C34, C35, C36, C37, C43, C44, C45, C46, C47, C63, C65: 1n; C_0603_1608Metric
C24, C32: 10u; CP_EIA-2012-12_Kemet-R
C25, C26, C27, C28, C29, C30, C31, C38, C39, C41, C60, C61, C64, C66, C67: 100n; C_0603_1608Metric
C40, C42: 6.8n; C_0603_1608Metric
C48, C49: 10p; C_0603_1608Metric
C50, C51, C52: 1u; C_0805_2012Metric
C53: 10u; CP_Elec_6.3x5.8
C54: 470p; C_0603_1608Metric
C55: 1000u; CP_Elec_10x10.5
C56: 100u; C_1206_3216Metric
C58: 4u7; C_0603_1608Metric
C59: 3.3n; C_0603_1608Metric
C62: 15n; C_0603_1608Metric
D2, D3, D4, D5, D6, D7, D8, D9: SL110PL-TP; D_SOD-123F
D10: SS34; D_SMA
D11: 1N4148W; D_SOD-123
D12: DFTL30A; D_SOD-123F
J3: RJ45; NE8FAHLRDAE
L2: 1u; L_Vishay_IHLP-1616
L3: H2019NLT; XFMR-SMD_16P-L12.7-W7.1-P1.27-LS9.4-BL; LCSC Part C110250
LED1, LED2: SK6805-EC15; LED-SMD_4P-L1.5-W1.5-BL; LCSC Part C2890035
R9: 10k; R_0603_1608Metric
R10, R11, R12, R13: 33R; R_0603_1608Metric
R14: 1M; R_0603_1608Metric
R15, R20, R21: 0R; R_0603_1608Metric
R16: 10R; R_0603_1608Metric
R17: 12.4k; R_0603_1608Metric
R18: 4.99k; R_0603_1608Metric
R19: 2.05k; R_0603_1608Metric
R22: 36.5k; R_0603_1608Metric
R23: 12.1k; R_0603_1608Metric
R24: 24.9k; R_0603_1608Metric
R25: 1k; R_0603_1608Metric
RN1, RN2: 75R; R_Array_Concave_4x0603
RN3: 10k; R_Array_Concave_4x0603
T1: FA2805; FA2924ALD
TP6, TP7, TP8, TP9, TP10, TP11, TP12, TP13, TP14, TP15, TP16, TP17, TP18, TP19, TP20: TestPoint; TestPoint_Pad_D1.5mm
U4: W5500; LQFP-48_7x7mm_P0.5mm
U5: VO618A-3X019T; SMDIP-4_W9.53mm_Clearance8mm
U6: SI3402-B-GMR; QFN-20_L5.0-W5.0-P0.80-TL-EP2.8; LCSC Part C510771
U7: TLV431; TSOT-23
Y2: ABM8-25.000MHZ-10-D1G-T; Crystal_SMD_3225-4Pin_3.2x2.5mm

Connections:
+3V3: C24.1, C25.1, C26.1, C27.1, C28.1, C29.1, C30.1, C31.1, C32.1, C60.1, L3.2 (TCT), L3.7 (RCT), R9.1, RN3.5 (R4.2), RN3.6 (R3.2), RN3.7 (R2.2), RN3.8 (R1.2), U4.4 (AVDD), U4.8 (AVDD), U4.11 (AVDD), U4.15 (AVDD), U4.17 (AVDD), U4.21 (AVDD), U4.28 (VDD); also elsewhere on the board
+LDO: C66.1, C67.1, LED1.2 (VDD), LED2.2 (VDD); also elsewhere on the board
/Ethernet/ACTLED: TP17.1 (1_1), U4.27 (ACTLED); also elsewhere on the board
/Ethernet/CT1: C33.1, C34.2, C43.1, D2.2 (A), D6.1 (K), L3.10 (RXCT), TP9.1 (1_1), U6.14 (CT1)
/Ethernet/CT2: C23.1, C35.2, C44.1, D3.2 (A), D7.1 (K), L3.15 (TXCT), TP8.1 (1_1), U6.13 (CT2)
/Ethernet/INTERRUPT: TP15.1 (1_1), U4.36 (~INT); also elsewhere on the board
/Ethernet/LINKLED: TP16.1 (1_1), U4.25 (LINKLED); also elsewhere on the board
/Ethernet/MISO: TP13.1 (1_1), U4.34 (MISO); also elsewhere on the board
/Ethernet/MOSI: TP14.1 (1_1), U4.35 (MOSI); also elsewhere on the board
/Ethernet/RD+: C40.2, L3.1 (TD+), RN2.1 (R1.1)
/Ethernet/RD-: C42.2, L3.3 (TD-), RN2.2 (R2.1)
/Ethernet/RST: C38.1, R9.2, TP10.1 (1_1), U4.37 (~RST); also elsewhere on the board
/Ethernet/RX+: J3.3, L3.16 (TX+)
/Ethernet/RX-: J3.6, L3.14 (TX-)
/Ethernet/RXN: R13.1, U4.5 (RXN)
/Ethernet/RXP: R12.1, U4.6 (RXP)
/Ethernet/SCK: TP12.1 (1_1), U4.33 (SCLK); also elsewhere on the board
/Ethernet/SCS: TP11.1 (1_1), U4.32 (~SCS); also elsewhere on the board
/Ethernet/SP1: C21.1, C36.2, C45.1, D4.2 (A), D8.1 (K), J3.7, J3.8, TP7.1 (1_1), U6.11 (SP1)
/Ethernet/SP2: C20.1, C37.2, C46.1, D5.2 (A), D9.1 (K), J3.4, J3.5, TP6.1 (1_1), U6.10 (SP2)
/Ethernet/TD+: L3.6 (RD+), R10.2, RN2.3 (R3.1)
/Ethernet/TD-: L3.8 (RD-), R11.2, RN2.4 (R4.1)
/Ethernet/TX+: J3.1, L3.11 (RX+)
/Ethernet/TX-: J3.2, L3.9 (RX-)
/Ethernet/TXN: R11.1, U4.1 (TXN)
/Ethernet/TXP: R10.1, U4.2 (TXP)
/Ethernet/V+: C34.1, C35.1, C36.1, C37.1, C47.2, C50.1, C51.1, C52.1, C53.1, C64.1, D2.1 (K), D3.1 (K), D4.1 (K), D5.1 (K), D11.1 (K), R24.2, T1.1, TP18.1 (1_1), U6.12 (VPOSF), U6.20 (FB)
/Ethernet/V-: C43.2, C44.2, C45.2, C46.2, C63.1, C64.2, D6.2 (A), D7.2 (A), D8.2 (A), D9.2 (A), R25.2, TP20.1 (1_1), U6.9 (VNEG), U6.21 (EP)
/LEDS_THRU: LED1.1 (DIN); also elsewhere on the board
GND: C22.2, C24.2, C25.2, C26.2, C27.2, C28.2, C29.2, C30.2, C31.2, C32.2, C38.2, C39.2, C41.2, C48.2, C49.2, C55.2, C56.2, C57.2, C58.2, C60.2, C63.2, C65.2, C66.2, C67.2, LED1.4 (GND), LED2.4 (GND), R17.2, R23.2, T1.9, T1.10, U4.3 (AGND), U4.9 (AGND), U4.14 (AGND), U4.16 (AGND), U4.19 (AGND), U4.29 (GND), U4.48 (AGND), U7.3 (A), Y2.2 (G), Y2.4 (G); also elsewhere on the board
GND1: C50.2, C51.2, C52.2, C53.2, C61.2, C62.2, U5.3, U6.7 (HSO), U6.19 (VSS2)
unnamed: C40.1, R12.2
unnamed: C42.1, R13.2
unnamed: C49.1, R14.1, R15.1, Y2.3
unnamed: C54.2, R16.1
unnamed: C59.2, R21.1
unnamed: C62.1, R20.2
unnamed: C65.1, J3.G1
unnamed: C54.1, D10.2 (A), T1.7, T1.8, TP19.1 (1_1)
unnamed: C56.1, D10.1 (K), L2.1, R16.2
unnamed: D11.2 (A), D12.2 (A)
unnamed: D12.1 (K), T1.2, U6.18 (SWO)
unnamed: LED1.3 (DO), LED2.1 (DIN)
unnamed: R19.1, U5.1
unnamed: C33.2, RN1.1 (R1.1)
unnamed: C22.1, RN1.5 (R4.2), RN1.6 (R3.2), RN1.7 (R2.2), RN1.8 (R1.2)
unnamed: C23.2, RN1.2 (R2.1)
unnamed: C21.2, RN1.3 (R3.1)
unnamed: C20.2, RN1.4 (R4.1)
unnamed: C41.1, RN2.7 (R2.2), RN2.8 (R1.2)
unnamed: C39.1, RN2.5 (R4.2), RN2.6 (R3.2)
unnamed: RN3.1 (R1.1), U4.45 (PMODE0)
unnamed: RN3.2 (R2.1), U4.44 (PMODE1)
unnamed: RN3.3 (R3.1), U4.43 (PMODE2)
unnamed: C57.1, U4.22 (1V2O)
unnamed: R17.1, U4.10 (EXRES1)
unnamed: C58.1, U4.20 (TOCAP)
unnamed: C48.1, R14.2, U4.30 (XI/CLKIN), Y2.1
unnamed: R15.2, U4.31 (XO)
unnamed: R18.2, R20.1, U5.4, U6.1 (EROUT)
unnamed: R25.1, U6.8 (RCL)
unnamed: R24.1, U6.6 (RDET)
unnamed: C59.1, U5.2, U7.2 (K)
unnamed: R21.2, R22.2, R23.1, U7.1 (Test)
VDD: C47.1, C55.1, C61.1, L2.2, R18.1, R19.2, R22.1, U6.3 (VDD); also elsewhere on the board

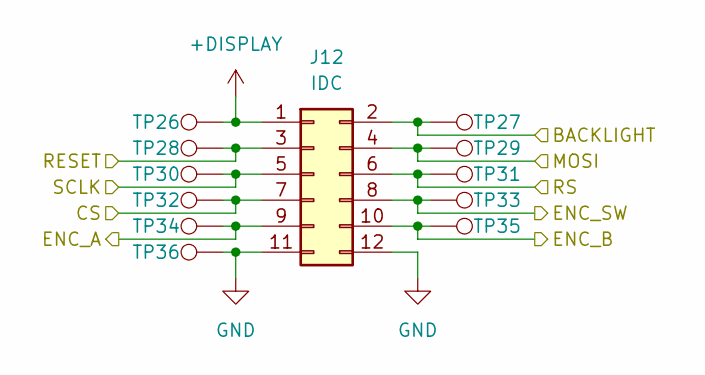
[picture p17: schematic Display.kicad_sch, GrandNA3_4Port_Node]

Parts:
J12: IDC; IDC-Header_2x06_P2.54mm_Vertical
TP26, TP27, TP28, TP29, TP30, TP31, TP32, TP33, TP34, TP35, TP36: TestPoint; TestPoint_Pad_D1.5mm

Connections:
+DISPLAY: J12.1, TP26.1 (1_1); also elsewhere on the board
/Display/BACKLIGHT: J12.2, TP27.1 (1_1); also elsewhere on the board
/Display/CS: J12.7, TP32.1 (1_1); also elsewhere on the board
/Display/ENC_A: J12.9, TP34.1 (1_1); also elsewhere on the board
/Display/ENC_B: J12.10, TP35.1 (1_1); also elsewhere on the board
/Display/ENC_SW: J12.8, TP33.1 (1_1); also elsewhere on the board
/Display/MOSI: J12.4, TP29.1 (1_1); also elsewhere on the board
/Display/RESET: J12.3, TP28.1 (1_1); also elsewhere on the board
/Display/RS: J12.6, TP31.1 (1_1); also elsewhere on the board
/Display/SCLK: J12.5, TP30.1 (1_1); also elsewhere on the board
GND: J12.11, J12.12, TP36.1 (1_1); also elsewhere on the board

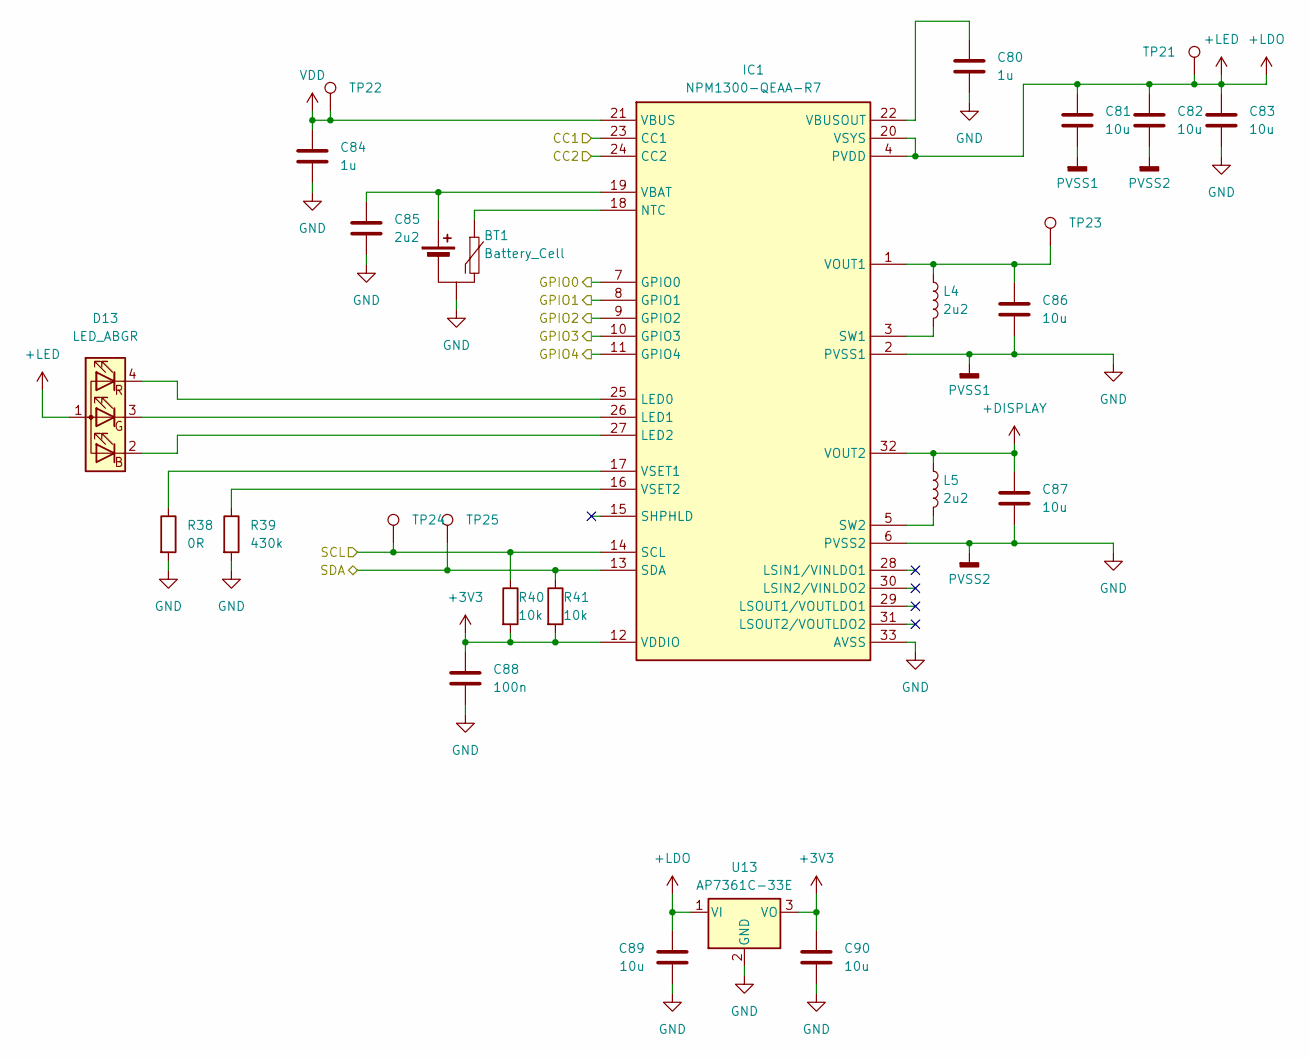
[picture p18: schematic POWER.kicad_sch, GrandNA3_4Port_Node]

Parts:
BT1: Battery_Cell; JST_XH_B3B-XH-A_1x03_P2.50mm_Vertical
C80, C84: 1u; C_0603_1608Metric
C81, C82, C83, C86, C87, C89, C90: 10u; C_0603_1608Metric
C85: 2u2; C_0603_1608Metric
C88: 100n; C_0603_1608Metric
D13: LED_ABGR; LED-SMD_4P-L1.6-W1.5-TR
IC1: NPM1300-QEAA-R7; QFN-32-1EP_5x5mm_P0.5mm_EP3.45x3.45mm_ThermalVias; Mouser Part Number 949-NPM1300-QEAA-R7
L4, L5: 2u2; L_0805_2012Metric
R38: 0R; R_0603_1608Metric
R39: 430k; R_0603_1608Metric
R40, R41: 10k; R_0603_1608Metric
TP21, TP22, TP23, TP24, TP25: TestPoint; TestPoint_Pad_D1.5mm
U13: AP7361C-33E; SOT-223-3_TabPin2

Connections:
+3V3: C88.1, C90.1, IC1.12 (VDDIO), R40.2, R41.2, U13.3 (VO); also elsewhere on the board
+DISPLAY: C87.1, IC1.32 (VOUT2), L5.1; also elsewhere on the board
+LDO: C81.1, C82.1, C83.1, C89.1, D13.1 (A), IC1.4 (PVDD), IC1.20 (VSYS), TP21.1 (1_1), U13.1 (VI); also elsewhere on the board
/Microcontroller/GPIO16: IC1.11 (GPIO4); also elsewhere on the board
/Microcontroller/GPIO17: IC1.10 (GPIO3); also elsewhere on the board
/Microcontroller/GPIO18: IC1.9 (GPIO2); also elsewhere on the board
/Microcontroller/GPIO19: IC1.8 (GPIO1); also elsewhere on the board
/Microcontroller/GPIO20: IC1.7 (GPIO0); also elsewhere on the board
/Microcontroller/GPIO22_I2C1_SDA: IC1.13 (SDA), R41.1, TP25.1 (1_1); also elsewhere on the board
/Microcontroller/GPIO23_I2C_SCL: IC1.14 (SCL), R40.1, TP24.1 (1_1); also elsewhere on the board
/POWER/CC1: IC1.23 (CC1); also elsewhere on the board
/POWER/CC2: IC1.24 (CC2); also elsewhere on the board
GND: BT1.2 (-), C80.2, C81.2, C82.2, C83.2, C84.2, C85.2, C86.2, C87.2, C88.2, C89.2, C90.2, IC1.2 (PVSS1), IC1.6 (PVSS2), IC1.33 (AVSS), R38.2, R39.2, U13.2 (GND); also elsewhere on the board
unnamed: BT1.1 (+), C85.1, IC1.19 (VBAT)
unnamed: BT1.3 (NTC), IC1.18 (NTC)
unnamed: D13.2 (BK), IC1.27 (LED2)
unnamed: D13.3 (GK), IC1.26 (LED1)
unnamed: D13.4 (RK), IC1.25 (LED0)
unnamed: IC1.3 (SW1), L4.2
unnamed: IC1.5 (SW2), L5.2
unnamed: C80.1, IC1.22 (VBUSOUT)
unnamed: C86.1, IC1.1 (VOUT1), L4.1, TP23.1 (1_1)
unnamed: IC1.17 (VSET1), R38.1
unnamed: IC1.16 (VSET2), R39.1
VDD: C84.1, IC1.21 (VBUS), TP22.1 (1_1); also elsewhere on the board

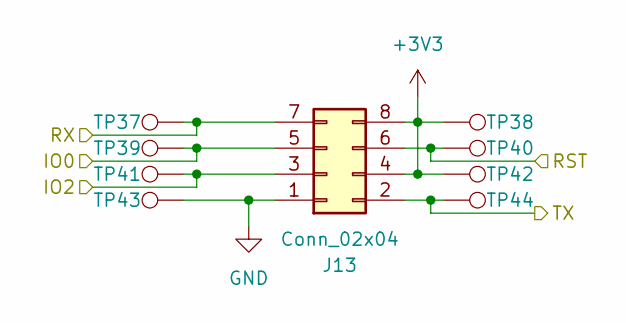
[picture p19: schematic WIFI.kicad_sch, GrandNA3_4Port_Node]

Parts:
J13: Conn_02x04; PinSocket_2x04_P2.54mm_Vertical
TP37, TP38, TP39, TP40, TP41, TP42, TP43, TP44: TestPoint; TestPoint_Pad_D1.5mm

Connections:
+3V3: J13.4, J13.8, TP38.1 (1_1), TP42.1 (1_1); also elsewhere on the board
/Microcontroller/GPIO11: J13.3, TP41.1 (1_1); also elsewhere on the board
/Microcontroller/GPIO12: J13.5, TP39.1 (1_1); also elsewhere on the board
/Microcontroller/GPIO13: J13.6, TP40.1 (1_1); also elsewhere on the board
/Microcontroller/GPIO14_UART1_TX: J13.7, TP37.1 (1_1); also elsewhere on the board
/Microcontroller/GPIO15_UART1_RX: J13.2, TP44.1 (1_1); also elsewhere on the board
GND: J13.1, TP43.1 (1_1); also elsewhere on the board

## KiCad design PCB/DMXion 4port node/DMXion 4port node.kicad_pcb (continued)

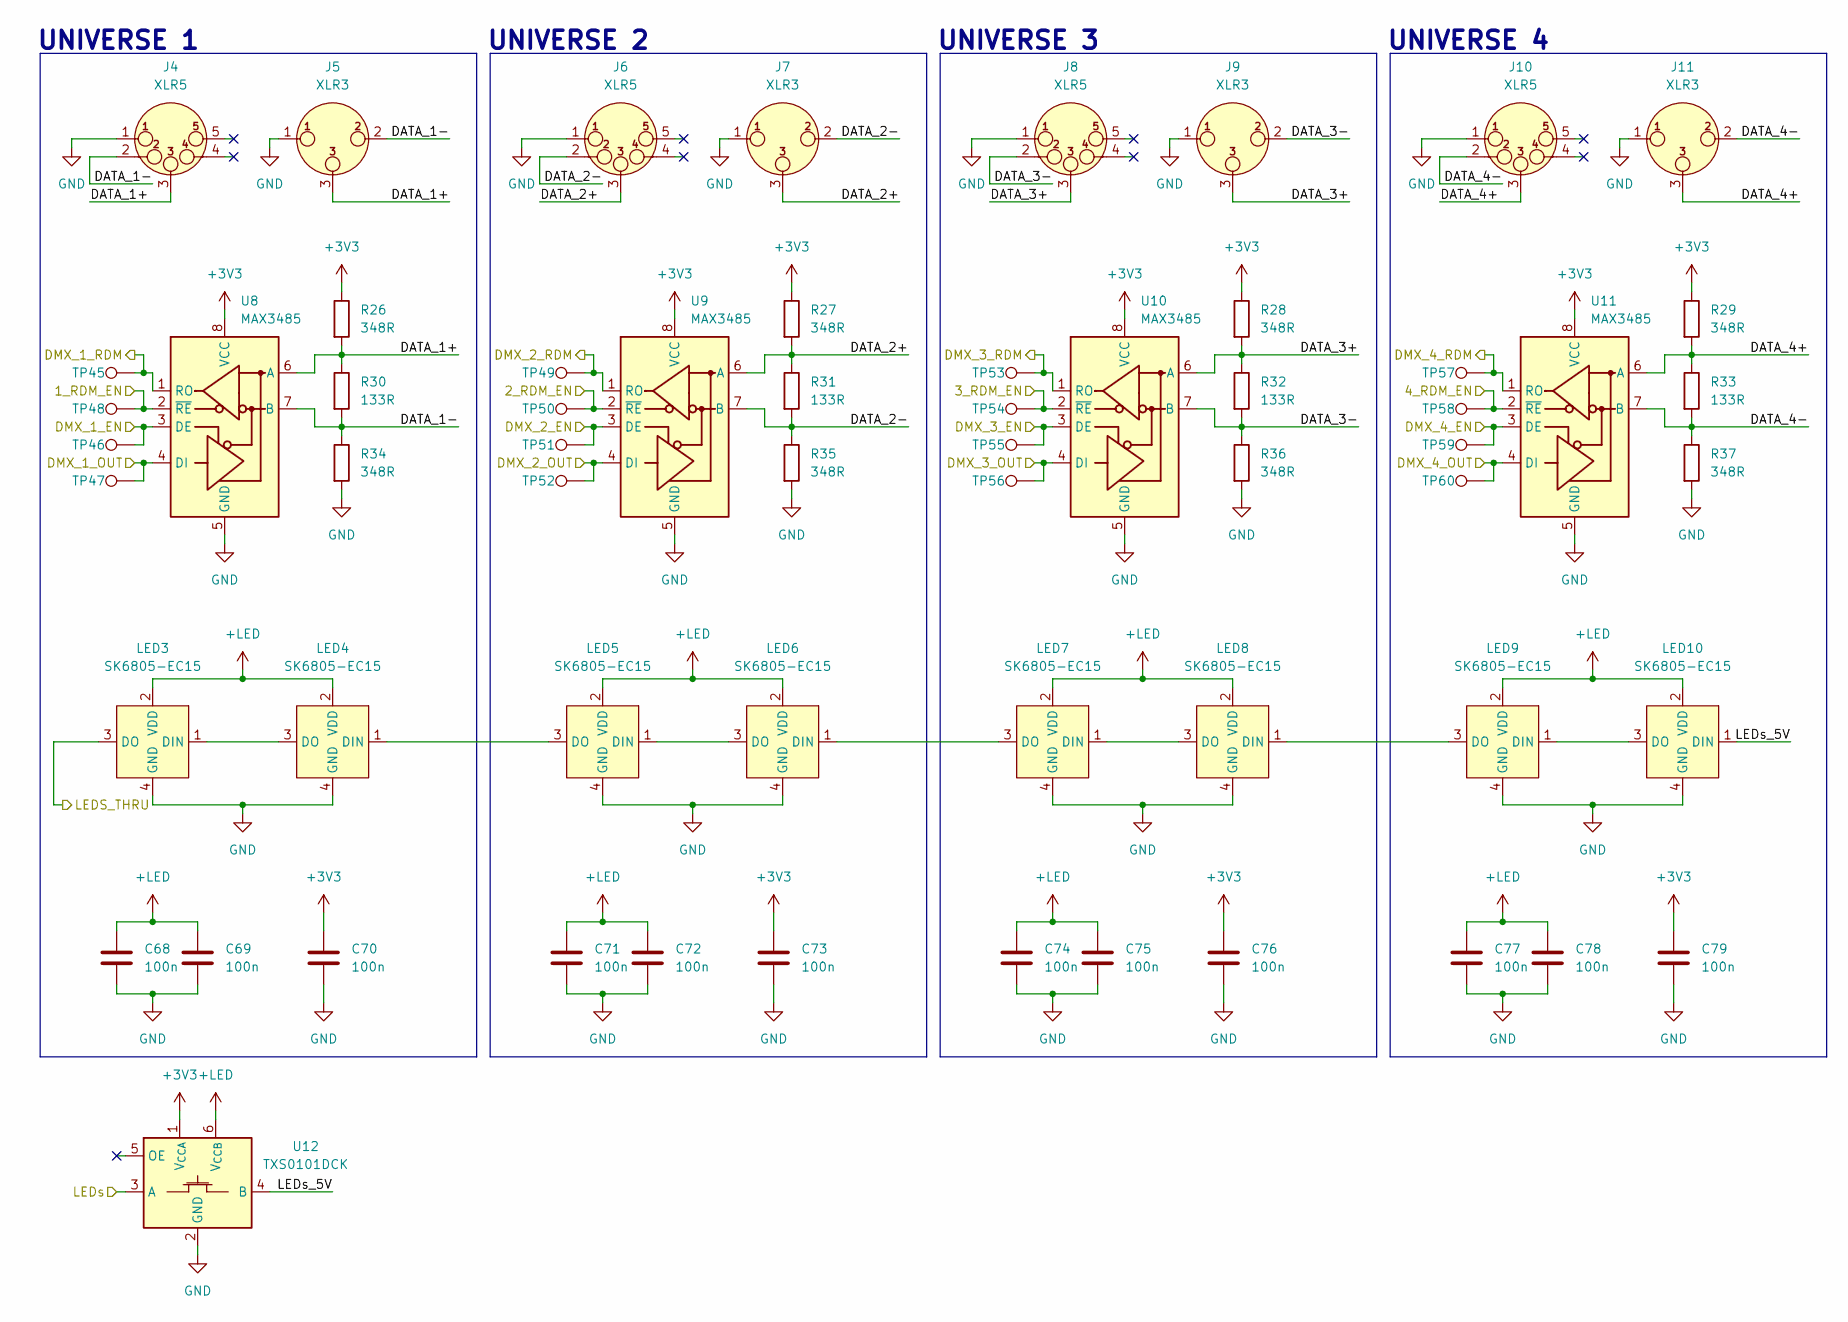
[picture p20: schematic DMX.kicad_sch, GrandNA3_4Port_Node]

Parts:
C68, C69, C70, C71, C72, C73, C74, C75, C76, C77, C78, C79: 100n; C_0603_1608Metric
J4, J6, J8, J10: XLR5; NC5FAH1-LR-DAE
J5, J7, J9, J11: XLR3; NC3FAH2-LR-DAE
LED3, LED4, LED5, LED6, LED7, LED8, LED9, LED10: SK6805-EC15; LED-SMD_4P-L1.5-W1.5-BL; LCSC Part C2890035
R26, R27, R28, R29, R34, R35, R36, R37: 348R; R_0603_1608Metric
R30, R31, R32, R33: 133R; R_0603_1608Metric
TP45, TP46, TP47, TP48, TP49, TP50, TP51, TP52, TP53, TP54, TP55, TP56, TP57, TP58, TP59, TP60: TestPoint; TestPoint_Pad_D1.5mm
U8, U9, U10, U11: MAX3485; SOIC-8_3.9x4.9mm_P1.27mm
U12: TXS0101DCK; SOT-363_SC-70-6

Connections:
+3V3: C70.1, C73.1, C76.1, C79.1, R26.1, R27.1, R28.1, R29.1, U8.8 (VCC), U9.8 (VCC), U10.8 (VCC), U11.8 (VCC), U12.1 (V_{CCA}); also elsewhere on the board
+LDO: C68.1, C69.1, C71.1, C72.1, C74.1, C75.1, C77.1, C78.1, LED3.2 (VDD), LED4.2 (VDD), LED5.2 (VDD), LED6.2 (VDD), LED7.2 (VDD), LED8.2 (VDD), LED9.2 (VDD), LED10.2 (VDD), U12.6 (V_{CCB}); also elsewhere on the board
/DMX/1_RDM_EN: TP48.1 (1_1), U8.2 (~RE); also elsewhere on the board
/DMX/2_RDM_EN: TP50.1 (1_1), U9.2 (~RE); also elsewhere on the board
/DMX/3_RDM_EN: TP54.1 (1_1), U10.2 (~RE); also elsewhere on the board
/DMX/4_RDM_EN: TP58.1 (1_1), U11.2 (~RE); also elsewhere on the board
/DMX/DATA_1+: J4.3, J5.3, R26.2, R30.1, U8.6 (A)
/DMX/DATA_1-: J4.2, J5.2, R30.2, R34.1, U8.7 (B)
/DMX/DATA_2+: J6.3, J7.3, R27.2, R31.1, U9.6 (A)
/DMX/DATA_2-: J6.2, J7.2, R31.2, R35.1, U9.7 (B)
/DMX/DATA_3+: J8.3, J9.3, R28.2, R32.1, U10.6 (A)
/DMX/DATA_3-: J8.2, J9.2, R32.2, R36.1, U10.7 (B)
/DMX/DATA_4+: J10.3, J11.3, R29.2, R33.1, U11.6 (A)
/DMX/DATA_4-: J10.2, J11.2, R33.2, R37.1, U11.7 (B)
/DMX/DMX_1_EN: TP46.1 (1_1), U8.3 (DE); also elsewhere on the board
/DMX/DMX_1_OUT: TP47.1 (1_1), U8.4 (DI); also elsewhere on the board
/DMX/DMX_1_RDM: TP45.1 (1_1), U8.1 (RO); also elsewhere on the board
/DMX/DMX_2_EN: TP51.1 (1_1), U9.3 (DE); also elsewhere on the board
/DMX/DMX_2_OUT: TP52.1 (1_1), U9.4 (DI); also elsewhere on the board
/DMX/DMX_2_RDM: TP49.1 (1_1), U9.1 (RO); also elsewhere on the board
/DMX/DMX_3_EN: TP55.1 (1_1), U10.3 (DE); also elsewhere on the board
/DMX/DMX_3_OUT: TP56.1 (1_1), U10.4 (DI); also elsewhere on the board
/DMX/DMX_3_RDM: TP53.1 (1_1), U10.1 (RO); also elsewhere on the board
/DMX/DMX_4_EN: TP59.1 (1_1), U11.3 (DE); also elsewhere on the board
/DMX/DMX_4_OUT: TP60.1 (1_1), U11.4 (DI); also elsewhere on the board
/DMX/DMX_4_RDM: TP57.1 (1_1), U11.1 (RO); also elsewhere on the board
/DMX/LEDs: U12.3 (A); also elsewhere on the board
/DMX/LEDs_5V: LED10.1 (DIN), U12.4 (B)
/LEDS_THRU: LED3.3 (DO); also elsewhere on the board
GND: C68.2, C69.2, C70.2, C71.2, C72.2, C73.2, C74.2, C75.2, C76.2, C77.2, C78.2, C79.2, J4.1, J5.1, J6.1, J7.1, J8.1, J9.1, J10.1, J11.1, LED3.4 (GND), LED4.4 (GND), LED5.4 (GND), LED6.4 (GND), LED7.4 (GND), LED8.4 (GND), LED9.4 (GND), LED10.4 (GND), R34.2, R35.2, R36.2, R37.2, U8.5 (GND), U9.5 (GND), U10.5 (GND), U11.5 (GND), U12.2 (GND); also elsewhere on the board
unnamed: LED3.1 (DIN), LED4.3 (DO)
unnamed: LED4.1 (DIN), LED5.3 (DO)
unnamed: LED5.1 (DIN), LED6.3 (DO)
unnamed: LED6.1 (DIN), LED7.3 (DO)
unnamed: LED7.1 (DIN), LED8.3 (DO)
unnamed: LED8.1 (DIN), LED9.3 (DO)
unnamed: LED9.1 (DIN), LED10.3 (DO)

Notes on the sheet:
UNIVERSE 1
UNIVERSE 3
UNIVERSE 4
UNIVERSE 2

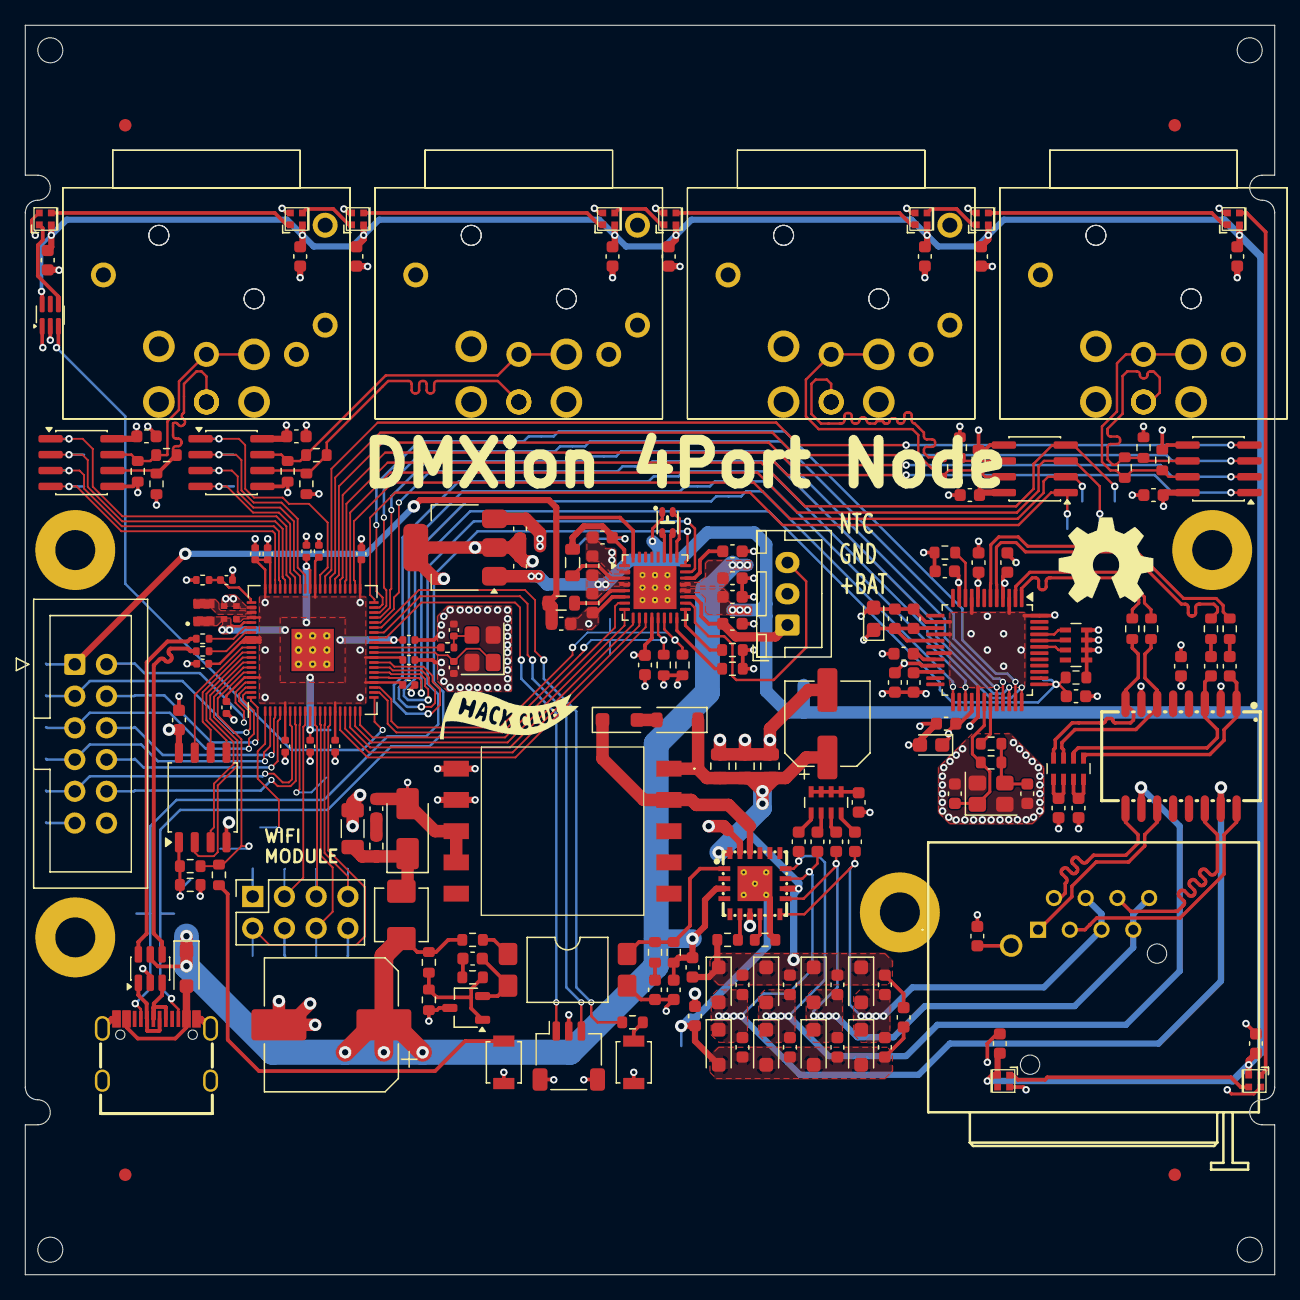
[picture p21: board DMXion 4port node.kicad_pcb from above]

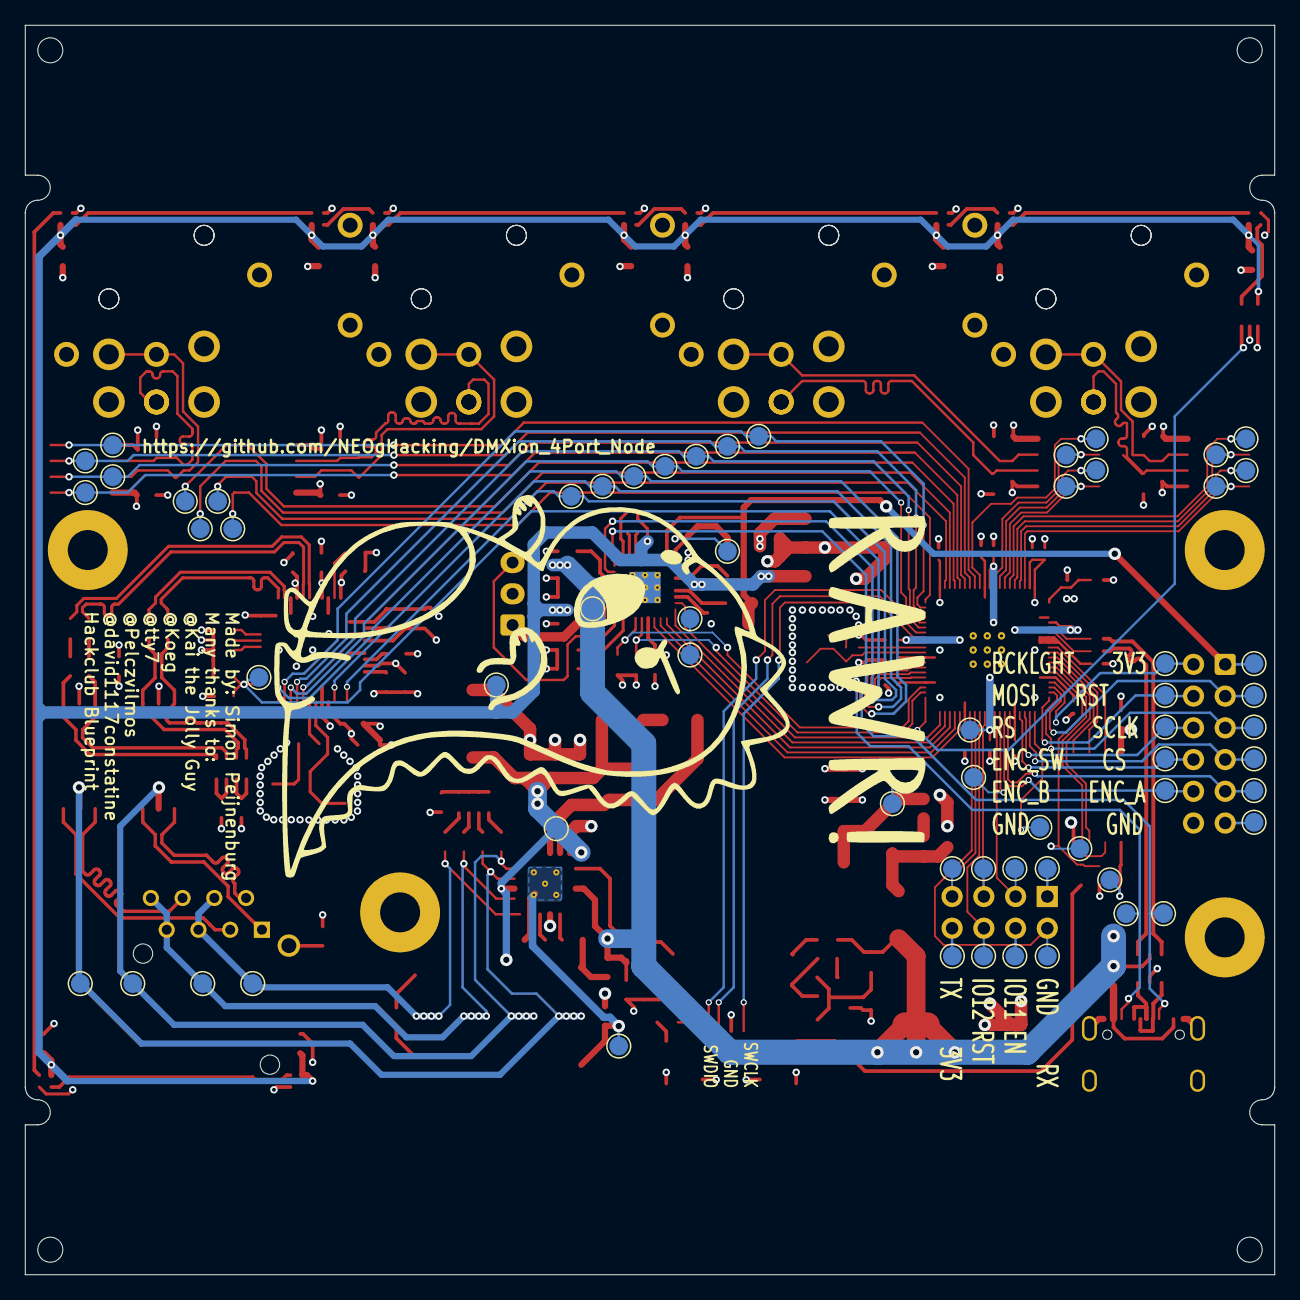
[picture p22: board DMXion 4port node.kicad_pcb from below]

Board: 4 copper layers, 100.0 x 100.0 mm, 269 parts (62 on the bottom side), 160 nets.

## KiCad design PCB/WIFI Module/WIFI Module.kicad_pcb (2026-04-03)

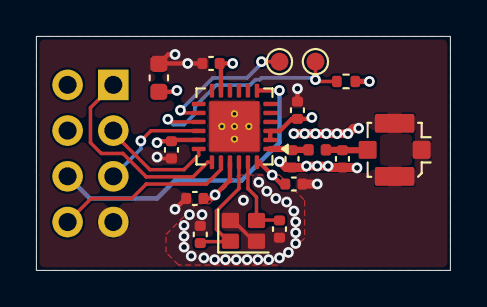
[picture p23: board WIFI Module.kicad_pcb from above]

Board: 4 copper layers, 23.0 x 13.0 mm, 18 parts (1 on the bottom side), 13 nets.

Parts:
C1: 10u; C_0603_1608Metric
C2, C3, C4, C5, C6: 100n; C_0402_1005Metric
C7, C8: 3p; C_0402_1005Metric
C9, C10: 14p; C_0402_1005Metric
J1: Conn_01x01_Shielded; U.FL_Molex_MCRF_73412-0110_Vertical
J2: Conn_02x04; PinHeader_2x04_P2.54mm_Vertical
L1: 2n; L_0402_1005Metric
R1: 10k; R_0402_1005Metric
TP1, TP2: TestPoint; TestPoint_Pad_D1.0mm
U1: ESP8684; QFN-24-1EP_4x4mm_P0.5mm_EP2.8x2.8mm
Y1: Q22FA12800230; Crystal_SMD_SeikoEpson_FA128-4Pin_2.0x1.6mm

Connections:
+3V3: C1.1, C2.1, C3.1, C4.1, C5.1, C6.1, J2.2, R1.2, U1.2 (VDDA3P3), U1.3 (VDDA3P3), U1.11 (VDD3P3_RTC), U1.17 (VDD3P3_CPU), U1.21 (VDDA), U1.24 (VDDA)
/EN: J2.6, U1.7 (CHIP_EN)
/GPIO9: R1.1, TP2.1, U1.15 (GPIO9/BOOT)
/GPIO10: J2.5, U1.16 (GPIO10/FSPICS0)
/GPIO18: J2.3, U1.18 (GPIO18)
/RX: J2.1, U1.19 (U0RXD/GPIO19)
/TX: J2.8, U1.20 (U0TXD/GPIO20)
GND: C1.2, C2.2, C3.2, C4.2, C5.2, C6.2, C7.2, C8.2, C9.1, C10.1, J1.SH (Shield), J2.7, U1.25 (GND), Y1.2 (G), Y1.4 (G)
unnamed: C7.1, J1.1, L1.1
unnamed: C8.1, L1.2, U1.1 (ANT)
unnamed: TP1.1, U1.14 (GPIO8)
unnamed: C9.2, U1.22 (XTAL_N), Y1.1
unnamed: C10.2, U1.23 (XTAL_P), Y1.3

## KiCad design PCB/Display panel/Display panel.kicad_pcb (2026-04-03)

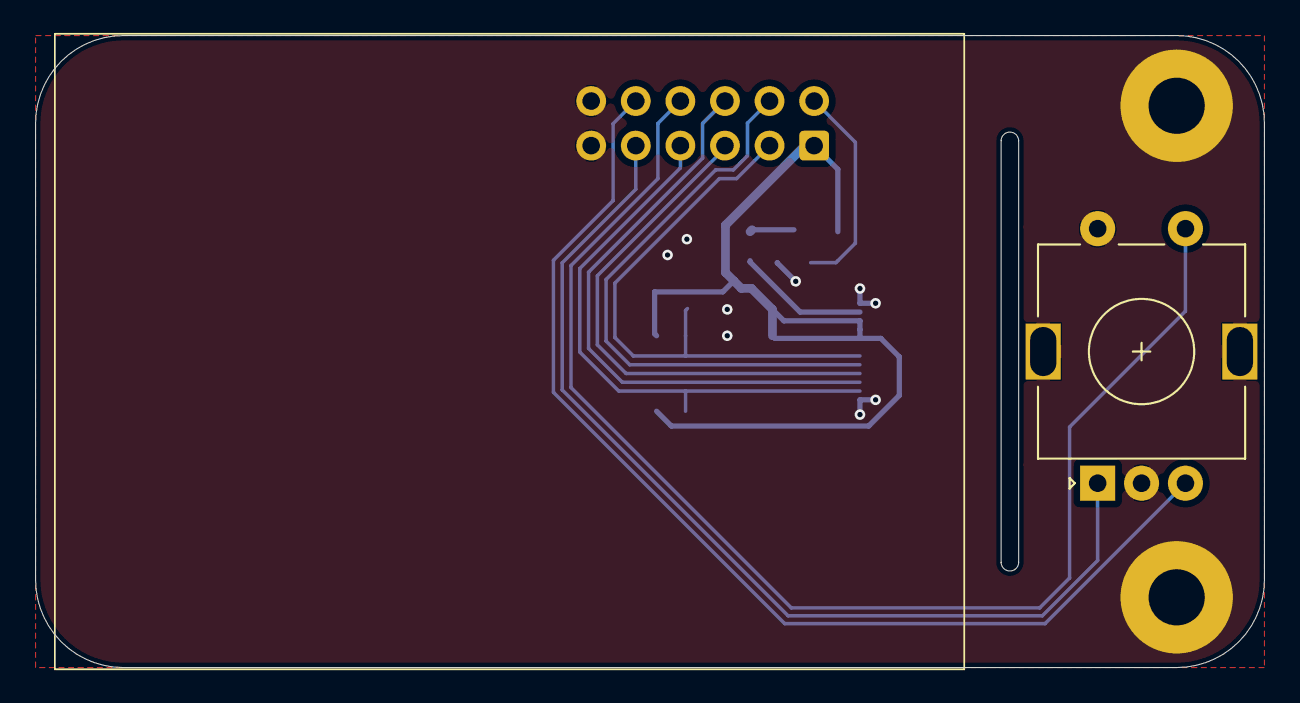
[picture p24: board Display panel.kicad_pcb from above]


Board: 2 copper layers, 70.0 x 36.0 mm, 13 parts (10 on the bottom side), 13 nets.

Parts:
C1: 4u7; C_0603_1608Metric
C2: 100n; C_0603_1608Metric
H1, H2: MountingHole_Pad; MountingHole_3.2mm_M3_Pad
J1: Conn_01x12_MountingPin; FPC-SMD_5034801200
J2: IDC; IDC-Header_2x06_P2.54mm_Vertical
Q2: BSS138; SOT-23
R1: 10R; R_0603_1608Metric
R2, R3, R4: 10k; R_0603_1608Metric
SW2: EC11E18244AU; RotaryEncoder_Alps_EC11E-Switch_Vertical_H20mm
U1: APX803S-31SA-7; SOT-23

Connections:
+3V3: C1.1, C2.1, J1.3, J1.4, J1.5, J2.1, R2.2, R3.1, R4.2, U1.3 (VCC)
/BACKLIGHT: J2.2, Q2.1 (G), R2.1
/CS: J1.11, J2.7, R3.2
/ENC_A: J2.9, SW2.A
/ENC_B: J2.10, SW2.B
/ENC_SW: J2.8, SW2.S1
/LED_K: J1.2, R1.2
/MOSI: J1.8, J2.4
/RESET: J1.7, J2.3, R4.1, U1.2 (~RESET)
/RS: J1.10, J2.6
/SCLK: J1.9, J2.5
GND: C1.2, C2.2, H1.1, H2.1, J1.1, J1.12, J1.MP (MountPin), J2.11, J2.12, Q2.2 (S), SW2.C, SW2.MP, SW2.S2, U1.1 (GND)
unnamed: Q2.3 (D), R1.1

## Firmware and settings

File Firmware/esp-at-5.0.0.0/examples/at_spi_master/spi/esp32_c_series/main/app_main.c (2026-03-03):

/*
 * SPDX-FileCopyrightText: 2024-2025 Espressif Systems (Shanghai) CO LTD
 *
 * SPDX-License-Identifier: Apache-2.0
 */
#include <stdio.h>
#include <stdint.h>
#include <stddef.h>
#include <string.h>
#include <time.h>

#include "freertos/FreeRTOS.h"
#include "freertos/task.h"
#include "freertos/semphr.h"
#include "freertos/queue.h"
#include "freertos/stream_buffer.h"

#include "esp_system.h"
#include "esp_err.h"
#include "esp_log.h"
#include "esp_intr_alloc.h"

#include "driver/gpio.h"
#include "driver/uart.h"
#include "driver/spi_master.h"

/*
Pins in use. The SPI Master can use the GPIO mux, so feel free to change these if needed.
*/
#define GPIO_HANDSHAKE        CONFIG_SPI_HANDSHAKE_PIN
#define GPIO_MOSI             CONFIG_SPI_MOSI_PIN
#define GPIO_MISO             CONFIG_SPI_MISO_PIN
#define GPIO_SCLK             CONFIG_SPI_SCLK_PIN
#define GPIO_CS               CONFIG_SPI_CS_PIN

#ifdef CONFIG_SPI_QUAD_MODE
#define GPIO_WP               CONFIG_SPI_WP_PIN
#define GPIO_HD               CONFIG_SPI_HD_PIN
#endif

#ifdef CONFIG_IDF_TARGET_ESP32
#define MASTER_HOST           HSPI_HOST
#elif defined CONFIG_IDF_TARGET_ESP32C3
#define MASTER_HOST           SPI2_HOST
#endif

#define DMA_CHAN              SPI_DMA_CH_AUTO
#define ESP_SPI_DMA_MAX_LEN   4092
#define CMD_HD_WRBUF_REG      0x01
#define CMD_HD_RDBUF_REG      0x02
#define CMD_HD_WRDMA_REG      0x03
#define CMD_HD_RDDMA_REG      0x04
#define CMD_HD_WR_END_REG     0x07
#define CMD_HD_INT0_REG       0x08
#define WRBUF_START_ADDR      0x0
#define RDBUF_START_ADDR      0x4
#define STREAM_BUFFER_SIZE    1024 * 8

typedef enum {
    SPI_NULL = 0,
    SPI_READ,         // slave -> master
    SPI_WRITE,             // maste -> slave
} spi_mode_t;

typedef struct {
    bool slave_notify_flag; // when slave recv done or slave notify master to recv, it will be true
} spi_master_msg_t;

typedef struct {
    uint32_t     magic    : 8;    // 0xFE
    uint32_t     send_seq : 8;
    uint32_t     send_len : 16;
} spi_send_opt_t;

typedef struct {
    uint32_t     direct : 8;
    uint32_t     seq_num : 8;
    uint32_t     transmit_len : 16;
} spi_recv_opt_t;

typedef struct {
    spi_mode_t direct;
} spi_msg_t;

static QueueHandle_t msg_queue; // meaasge queue used for communicating read/write start
static QueueHandle_t esp_at_uart_queue = NULL;
static spi_device_handle_t handle;
static StreamBufferHandle_t spi_master_tx_ring_buf = NULL;
static const char* TAG = "SPI AT Master";
static SemaphoreHandle_t pxMutex;
static uint8_t initiative_send_flag = 0; // it means master has data to send to slave
static uint32_t plan_send_len = 0; // master plan to send data len

static uint8_t current_send_seq = 0;
static uint8_t current_recv_seq = 0;

static void spi_mutex_lock(void)
{
    while (xSemaphoreTake(pxMutex, portMAX_DELAY) != pdPASS);
}

static void spi_mutex_unlock(void)
{
    xSemaphoreGive(pxMutex);
}

/*
This isr handler is called when the handshake line goes high.
There are two ways to trigger the GPIO interrupt:
1. Master sends data, slave has received successfully
2. Slave has data want to transmit
*/
static void IRAM_ATTR gpio_handshake_isr_handler(void* arg)
{
    //Give the semaphore.
    BaseType_t mustYield = false;
    spi_master_msg_t spi_msg = {
        .slave_notify_flag = true,
    };
    xQueueSendFromISR(msg_queue, (void*)&spi_msg, &mustYield); // notify master to do next transaction

    if (mustYield) {
        portYIELD_FROM_ISR();
    }
}

static void at_spi_master_send_data(uint8_t* data, uint32_t len)
{
    spi_transaction_t trans = {
#if defined(CONFIG_SPI_QUAD_MODE)
        .flags = SPI_TRANS_MODE_QIO,
        .cmd = CMD_HD_WRDMA_REG | (0x2 << 4),    // master -> slave command, do not change
#elif defined(CONFIG_SPI_DUAL_MODE)
        .flags = SPI_TRANS_MODE_DIO,
        .cmd = CMD_HD_WRDMA_REG | (0x1 << 4),
#else
        .cmd = CMD_HD_WRDMA_REG,    // master -> slave command, do not change
#endif
        .length = len * 8,
        .tx_buffer = (void*)data
    };
    spi_device_polling_transmit(handle, &trans);
}

static void at_spi_master_recv_data(uint8_t* data, uint32_t len)
{
    spi_transaction_t trans = {
#if defined(CONFIG_SPI_QUAD_MODE)
        .flags = SPI_TRANS_MODE_QIO,
        .cmd = CMD_HD_RDDMA_REG | (0x2 << 4),    // master -> slave command, do not change
#elif defined(CONFIG_SPI_DUAL_MODE)
        .flags = SPI_TRANS_MODE_DIO,
        .cmd = CMD_HD_RDDMA_REG | (0x1 << 4),
#else
        .cmd = CMD_HD_RDDMA_REG,    // master -> slave command, do not change
#endif
        .rxlength = len * 8,
        .rx_buffer = (void*)data
    };
    spi_device_polling_transmit(handle, &trans);
}

// send a single to slave to tell slave that master has read DMA done
static void at_spi_rddma_done(void)
{
    spi_transaction_t end_t = {
        .cmd = CMD_HD_INT0_REG,
    };
    spi_device_polling_transmit(handle, &end_t);
}

// send a single to slave to tell slave that master has write DMA done
static void at_spi_wrdma_done(void)
{
    spi_transaction_t end_t = {
        .cmd = CMD_HD_WR_END_REG,
    };
    spi_device_polling_transmit(handle, &end_t);
}

// when spi slave ready to send/recv data from the spi master, the spi slave will a trigger GPIO interrupt,
// then spi master should query whether the slave will perform read or write operation.
static spi_recv_opt_t query_slave_data_trans_info()
{
    spi_recv_opt_t recv_opt;
    spi_transaction_t trans = {
        .cmd = CMD_HD_RDBUF_REG,
        .addr = RDBUF_START_ADDR,
        .rxlength = 4 * 8,
        .rx_buffer = &recv_opt,
    };
    spi_device_polling_transmit(handle, (spi_transaction_t*)&trans);
    return recv_opt;
}

// before spi master write to slave, the master should write WRBUF_REG register to notify slave,
// and then wait for handshark line trigger gpio interrupt to start the data transmission.
static void spi_master_request_to_write(uint8_t send_seq, uint16_t send_len)
{
    spi_send_opt_t send_opt;
    send_opt.magic = 0xFE;
    send_opt.send_seq = send_seq;
    send_opt.send_len = send_len;

    spi_transaction_t trans = {
        .cmd = CMD_HD_WRBUF_REG,
        .addr = WRBUF_START_ADDR,
        .length = 4 * 8,
        .tx_buffer = &send_opt,
    };
    spi_device_polling_transmit(handle, (spi_transaction_t*)&trans);
    // increment
    current_send_seq  = send_seq;
}

// spi master write data to slave
static int8_t spi_write_data(uint8_t* buf, int32_t len)
{
    if (len > ESP_SPI_DMA_MAX_LEN) {
        ESP_LOGE(TAG, "Send length error, len:%ld", len);
        return -1;
    }
    at_spi_master_send_data(buf, len);
    at_spi_wrdma_done();
    return 0;
}

// write data to spi tx_ring_buf, this is just for test
static int32_t write_data_to_spi_task_tx_ring_buf(const void* data, size_t size)
{
    int32_t length = size;

    if (data == NULL  || length > STREAM_BUFFER_SIZE) {
        ESP_LOGE(TAG, "Write data error, len:%ld", length);
        return -1;
    }

    length = xStreamBufferSend(spi_master_tx_ring_buf, data, size, portMAX_DELAY);
    return length;
}

// notify slave to recv data
static void notify_slave_to_recv(void)
{
    if (initiative_send_flag == 0) {
        spi_mutex_lock();
        uint32_t tmp_send_len = xStreamBufferBytesAvailable(spi_master_tx_ring_buf);
        if (tmp_send_len > 0) {
            plan_send_len = tmp_send_len > ESP_SPI_DMA_MAX_LEN ? ESP_SPI_DMA_MAX_LEN : tmp_send_len;
            spi_master_request_to_write(current_send_seq + 1, plan_send_len); // to tell slave that the master want to write data
            initiative_send_flag = 1;
        }
        spi_mutex_unlock();
    }
}

static void IRAM_ATTR spi_trans_control_task(void* arg)
{
    esp_err_t ret;
    spi_master_msg_t trans_msg = {0};
    uint32_t send_len = 0;

    uint8_t* trans_data = (uint8_t*)malloc(ESP_SPI_DMA_MAX_LEN * sizeof(uint8_t));
    if (trans_data == NULL) {
        ESP_LOGE(TAG, "malloc fail");
        return;
    }

    while (1) {
        xQueueReceive(msg_queue, (void*)&trans_msg, (TickType_t)portMAX_DELAY);
        spi_mutex_lock();
        spi_recv_opt_t recv_opt = query_slave_data_trans_info();

        if (recv_opt.direct == SPI_WRITE) {
            if (plan_send_len == 0) {
                ESP_LOGE(TAG, "master want send data but length is 0");
                continue;
            }

            if (recv_opt.seq_num != current_send_seq) {
                ESP_LOGE(TAG, "SPI send seq error, %x, %x", recv_opt.seq_num, current_send_seq);
                if (recv_opt.seq_num == 1) {
                    ESP_LOGE(TAG, "Maybe SLAVE restart, ignore");
                    current_send_seq = recv_opt.seq_num;
                } else {
                    break;
                }
            }

            //initiative_send_flag = 0;
            send_len = xStreamBufferReceive(spi_master_tx_ring_buf, (void*) trans_data, plan_send_len, 0);

            if (send_len != plan_send_len) {
                ESP_LOGE(TAG, "Read len expect %lu, but actual read%lu", plan_send_len, send_len);
                break;
            }

            ret = spi_write_data(trans_data, plan_send_len);
            if (ret < 0) {
                ESP_LOGE(TAG, "Load data error");
                return;
            }

            // maybe streambuffer filled some data when SPI transimit, just consider it after send done, because send flag has already in SLAVE queue
            uint32_t tmp_send_len = xStreamBufferBytesAvailable(spi_master_tx_ring_buf);
            if (tmp_send_len > 0) {
                plan_send_len = tmp_send_len > ESP_SPI_DMA_MAX_LEN ? ESP_SPI_DMA_MAX_LEN : tmp_send_len;
                spi_master_request_to_write(current_send_seq + 1, plan_send_len);
            } else {
                initiative_send_flag = 0;
            }

        } else if (recv_opt.direct == SPI_READ) {
            if (recv_opt.seq_num != ((current_recv_seq + 1) & 0xFF)) {
                ESP_LOGE(TAG, "SPI recv seq error, %x, %x", recv_opt.seq_num, (current_recv_seq + 1));
                if (recv_opt.seq_num == 1) {
                    ESP_LOGE(TAG, "Maybe SLAVE restart, ignore");
                } else {
                    break;
                }
            }

            if (recv_opt.transmit_len > STREAM_BUFFER_SIZE || recv_opt.transmit_len == 0) {
                ESP_LOGE(TAG, "SPI read len error, %x", recv_opt.transmit_len);
                break;
            }

            current_recv_seq = recv_opt.seq_num;
            memset(trans_data, 0x0, recv_opt.transmit_len);
            at_spi_master_recv_data(trans_data, recv_opt.transmit_len);
            at_spi_rddma_done();
            trans_data[recv_opt.transmit_len] = '\0';
            printf("%s", trans_data);
            fflush(stdout);    //Force to print even if have not '\n'
        } else {
            ESP_LOGD(TAG, "Unknown direct: %d", recv_opt.direct);
            spi_mutex_unlock();
            continue;
        }

        spi_mutex_unlock();
    }

    free(trans_data);
    vTaskDelete(NULL);
}

// read data from uart, and then send data to spi_master_tx_ring_buf.
// this is just used to use uart port to send command.
void uart_task(void* pvParameters)
{
    uart_event_t event;
    uint8_t* dtmp = (uint8_t*) malloc(1024);

    for (;;) {
        //Waiting for UART event.
        if (xQueueReceive(esp_at_uart_queue, (void *) &event,
                          (TickType_t) portMAX_DELAY)) {
            switch (event.type) {
            //Event of UART receiving data
            case UART_DATA:
                if (event.size) {
                    memset(dtmp, 0x0, 1024);
                    // read the data which spi master want to send
                    uart_read_bytes(0, dtmp, event.size, portMAX_DELAY);
                    // send data to spi task
                    write_data_to_spi_task_tx_ring_buf(dtmp, event.size);
                    notify_slave_to_recv();
                }
                break;

            case UART_PATTERN_DET:
                break;

            //Others
            default:
                break;
            }
        }
    }

    free(dtmp);
    dtmp = NULL;
    vTaskDelete(NULL);
}

inline void spi_bus_defalut_config(spi_bus_config_t* bus_cfg)
{
    bus_cfg->mosi_io_num = GPIO_MOSI;
    bus_cfg->miso_io_num = GPIO_MISO;
    bus_cfg->sclk_io_num = GPIO_SCLK;
#if defined(CONFIG_SPI_QUAD_MODE)
    bus_cfg->quadwp_io_num = GPIO_WP;
    bus_cfg->quadhd_io_num = GPIO_HD;
#else
    bus_cfg->quadwp_io_num = -1;
    bus_cfg->quadhd_io_num = -1;
#endif
    bus_cfg->max_transfer_sz = 14000;
}

inline void spi_device_default_config(spi_device_interface_config_t* dev_cfg)
{
    dev_cfg->clock_speed_hz = SPI_MASTER_FREQ_20M;
    dev_cfg->mode = 0;
    dev_cfg->spics_io_num = GPIO_CS;
    dev_cfg->cs_ena_pretrans = 8;
    dev_cfg->cs_ena_posttrans = 8;
    dev_cfg->command_bits = 8;
    dev_cfg->address_bits = 8;
    dev_cfg->dummy_bits = 8;
    dev_cfg->queue_size = 16;
    dev_cfg->flags = SPI_DEVICE_HALFDUPLEX;
    dev_cfg->input_delay_ns = 25;
}

static void init_master_hd(spi_device_handle_t* spi)
{
    // GPIO config for the handshake line.
    gpio_config_t io_conf = {
        .intr_type = GPIO_INTR_POSEDGE,
        .mode = GPIO_MODE_INPUT,
        .pull_up_en = 1,
        .pin_bit_mask = (1 << GPIO_HANDSHAKE)
    };

    //Set up handshake line interrupt.
    gpio_config(&io_conf);
    gpio_install_isr_service(0);
    gpio_set_intr_type(GPIO_HANDSHAKE, GPIO_INTR_POSEDGE);
    gpio_isr_handler_add(GPIO_HANDSHAKE, gpio_handshake_isr_handler, NULL);

    // Create the meaasge queue.
    msg_queue = xQueueCreate(5, sizeof(spi_master_msg_t));
    // Create the tx_buf.
    spi_master_tx_ring_buf = xStreamBufferCreate(STREAM_BUFFER_SIZE, 1);
    // Create the semaphore.
    pxMutex = xSemaphoreCreateMutex();

    //init bus
    spi_bus_config_t bus_cfg = {};
    spi_bus_defalut_config(&bus_cfg);
    ESP_ERROR_CHECK(spi_bus_initialize(MASTER_HOST, &bus_cfg, DMA_CHAN));

    //add device
    spi_device_interface_config_t dev_cfg = {};
    spi_device_default_config(&dev_cfg);
    ESP_ERROR_CHECK(spi_bus_add_device(MASTER_HOST, &dev_cfg, spi));

    spi_mutex_lock();

    spi_recv_opt_t recv_opt = query_slave_data_trans_info();
    ESP_LOGI(TAG, "now direct:%u", recv_opt.direct);

    if (recv_opt.direct == SPI_READ) { // if slave in waiting response status, master need to give a read done single.
        if (recv_opt.seq_num != ((current_recv_seq + 1) & 0xFF)) {
            ESP_LOGE(TAG, "SPI recv seq error, %x, %x", recv_opt.seq_num, (current_recv_seq + 1));
            if (recv_opt.seq_num == 1) {
                ESP_LOGE(TAG, "Maybe SLAVE restart, ignore");
            }
        }

        current_recv_seq = recv_opt.seq_num;

        at_spi_rddma_done();
    }
    spi_mutex_unlock();
}

void app_main()
{
    init_master_hd(&handle);

    // init UART
    uart_driver_install(0, 2048, 8192, 10, &esp_at_uart_queue, 1);
    xTaskCreate(uart_task, "uTask", 2048, NULL, 4, NULL);

    xTaskCreate(spi_trans_control_task, "spi_trans_control_task", 1024 * 2, NULL, 8, NULL);
}

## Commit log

2026-03-02 Update README with schematics and PCB details
    Added schematics and PCB images to the README.
2026-03-03 Updated BOM
    [BOM_ORDER.xlsx]
2026-03-03 Made BOM collapsible
2026-03-03 Added firware for the wifi module
    [at_customize.csv, at_customized_config_dependency.txt, factory_param_data.csv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]
2026-03-14 Updated the PCB Allot
    [Artnet_DMX_Converter.kicad_pcb, Artnet_DMX_Converter.kicad_sch, DMX.kicad_sch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]
2026-03-15 EVEN MORE PCB updates
    [Artnet_DMX_Converter.kicad_pcb]
2026-03-16 Fixed allot of problems
    Added a new LDO for the 3.3V rail to support the load i miscalculated 💀
    [Artnet_DMX_Converter.kicad_pcb, POWER.kicad_sch]
2026-03-16 Fixed RP2350 power layout
    [Artnet_DMX_Converter.kicad_pcb, Microcontroller.kicad_sch, RP2350_QFN80.step]
2026-03-17 Testpoints and GND1 Fill
    [Artnet_DMX_Converter.kicad_pcb, Display.kicad_sch, Ethernet.kicad_sch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]
2026-03-23 Renamed device
    [Artnet_DMX_Converter.kicad_pcb, Artnet_DMX_Converter.kicad_sch, DMX.kicad_sch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]
2026-03-24 Auto stash before merge of "main" and "origin/main"
    [DMXion 4port node.kicad_pcb]
2026-04-01 Added more testpoints
    [DMX.kicad_sch, DMXion 4port node.kicad_pcb, DMXion 4port node.kicad_sch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]
2026-04-01 Even more testpads
    [DMXion 4port node.kicad_pcb, DMXion 4port node.kicad_sch]
2026-04-03 Fixed allot of PCB mistakes and added more silkscreen
    [BOM_ORDER.xlsx, DMXion 4port node.kicad_pcb, Display panel Panelized.kicad_pcb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]
